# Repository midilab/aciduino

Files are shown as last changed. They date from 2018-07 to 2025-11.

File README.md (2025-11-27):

# Aciduino

The DIY Arduino-based Roland TB303 and TR808 Step Sequencer clone and MIDI Controller. Designed using readily available, inexpensive parts. It can be easily assembled on a protoboard or [ordered as PCB](https://pushermanproductions.com/product/midilab-aciduino-303-style-midi-sequencer-pcb-only/). 

There are two flavors of aciduino, the [first version(v1)](https://github.com/midilab/aciduino/tree/master/v1/) is a TB303 sequencer only, the [second version(v2)](https://github.com/midilab/aciduino/tree/master/v2/) is a TB303 and TR808 sequencer with oled display and step/pattern/mute grid system.

Find out more about at [official home page](https://midilab.co/aciduino/)

## [Aciduino V1](https://github.com/midilab/aciduino/tree/master/v1/)  
2 Tracks TB303 sequencer and MIDI Controller.

V1 on PCB
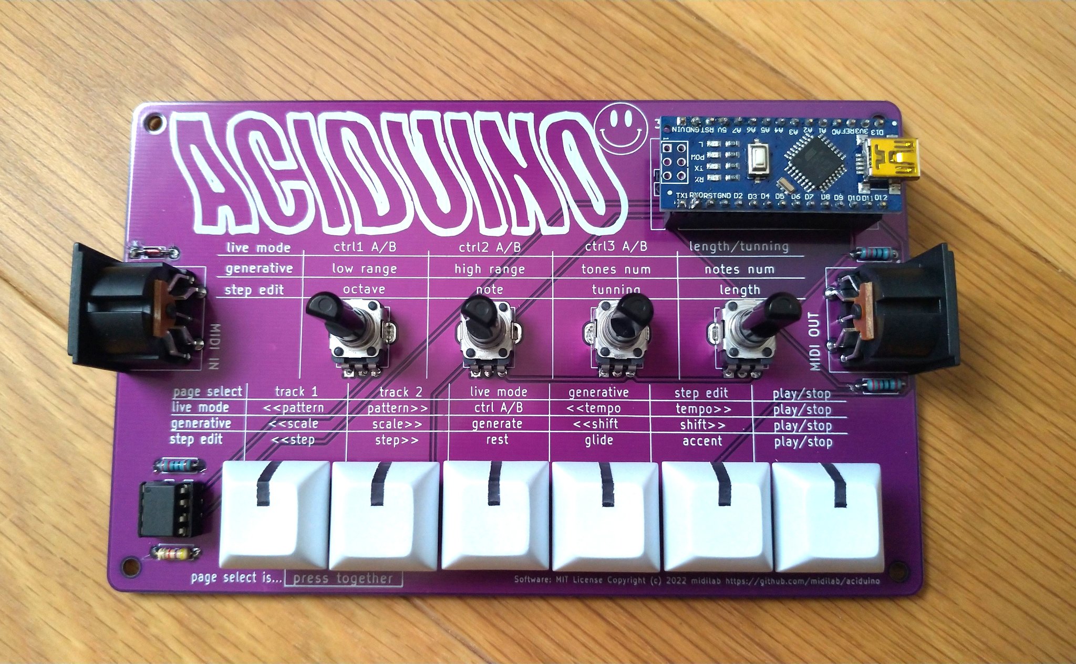
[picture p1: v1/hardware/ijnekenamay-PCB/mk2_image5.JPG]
Image of aciduino on pcb


## [Aciduino V2](https://github.com/midilab/aciduino/tree/master/v2/)  
Up to 16 Tracks TB303/TR808 sequencer with step, pattern and mute automation grid system, MIDI Controller, OLED display and extensible modular design to plug more potentiometers, buttons, MIDI or CV/Gate interfaces.

V2 on Protoboard
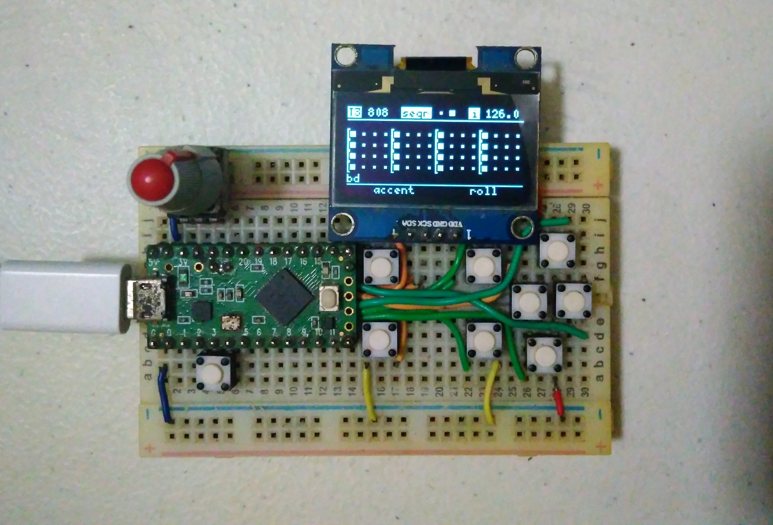
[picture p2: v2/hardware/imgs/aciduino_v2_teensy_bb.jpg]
Image of aciduino on protoboard


V2 on PCB(prototype)

Image of aciduino on uone front

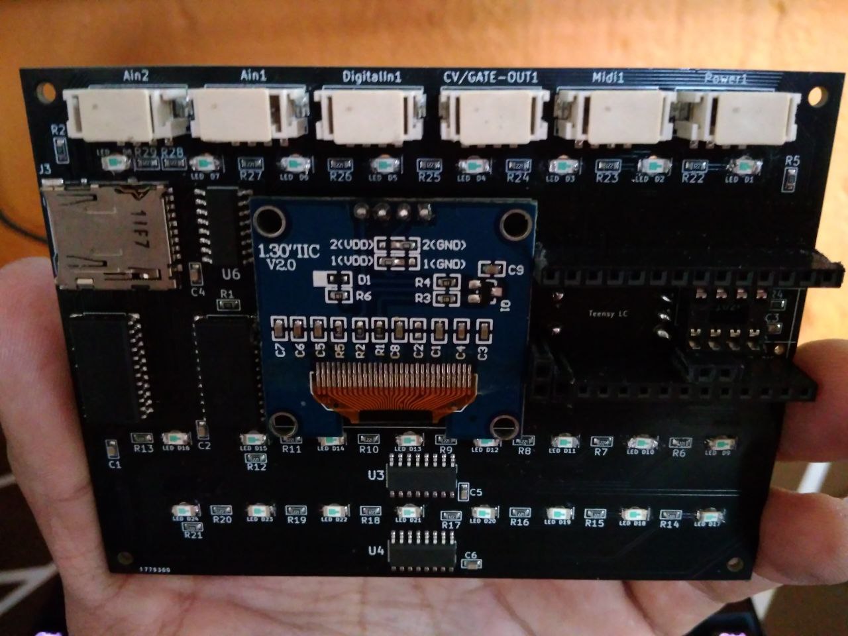
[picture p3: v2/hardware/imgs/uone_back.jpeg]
Image of aciduino on uone back


Features
========

### 303/808 Step Sequencer clone

Programming bass and drum steps using same analogy of original machines • Save your pattern work on microcontroller EPPROM memory for later live gigs • Use step length and shift to make some unusual sequences • Automation grid system for step edit, pattern navigation and mute tracks • Realtime and Step record modes for MIDI keyboard input(v2 only)

### Professional grade Clock

Tight and solid clock system using hardware timers to achieve realtime professional grade tick system • Send or receive clock to keep all your external equipment synced

### Generative Engine

Generate new and fresh acid music patterns by pressing a single button and twist some parameters • Harmonizer to force musical harmonic modes for bass lines • Euclidian generator for drum parts

### Midi Controller

Controls up to 16 parameters per track of your external synthesizers(bass/drums) • Midi learn(v2 only) • 16 potentiometers modular support to extend aciduino as midi controller(v2 only)

### Pattern memory

Store your patterns conveniently on the microcontroller's EEPROM, allowing you to access them effortlessly during live performances.

# Easy and fast Assembly

1 or 2 hours assembly time on protoboard. 

[V1 Assembly](https://github.com/midilab/aciduino/tree/master/v1)

[V2 Assembly](https://github.com/midilab/aciduino/tree/master/v2#assembly)

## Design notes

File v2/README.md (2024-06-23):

# Aciduino V2

Put your DIY super powers to the test building your own Roland's TB-303 and/or TB-808 step sequencer! An Arduino based clone project specially hacked with corrosive features to improve live performances! Save your money building the classic and timeless TB-303 and TR-808 step sequencer clone faster than a blink of an eye.

This version is multi-architecture, allowing for the use of different microcontrollers in the build. Currently, it supports Arduino Mega, any Teensy >= 3.2, and ESP32(tested on wroom dev kit only for now).

Aciduino V2 is also the first official [uMODULAR](https://github.com/midilab/uMODULAR) app, leveraging uMODULAR schematics, [uCtrl](https://github.com/midilab/uCtrl) drivers/interface library, and [uClock](https://github.com/midilab/uClock) BPM clock generator.

# Download

The recommended way for aciduino users is to make use of release pack on [Releases area](https://github.com/midilab/aciduino/releases), make sure to download the one named aciduino-v2_xxx.zip, where xxx is the version released.  
  
If you want to get the latest on the edge features and keep in track with development of aciduino you can make use of git version via clone.  
  
As this version utilizes uCtrl and uClock libraries as submodules, please remember to initialize the submodules immediately after cloning the repository.  

```console
you@acidlab:~$ git clone https://github.com/midilab/aciduino.git
you@acidlab:~$ cd aciduino/
you@acidlab:~$ git submodule update --init --recursive
```  

Open v2/AciduinoV2/AciduinoV2.ino and uncomment only one of the following microcontroller ports depending on wich one you're going to use.

```c
...
//
// Select your platform port
//
//#include "src/ports/avr/mega.h"
//#include "src/ports/teensy/protoboard.h"
#include "src/ports/esp32/wroom.h"
//#include "src/ports/esp32/wroom-ext1.h"
//#include "src/ports/teensy/uone.h"
//#include "src/ports/avr/midilab_mega.h"
...
```

## How does it looks like?

Image of aciduino on protoboard

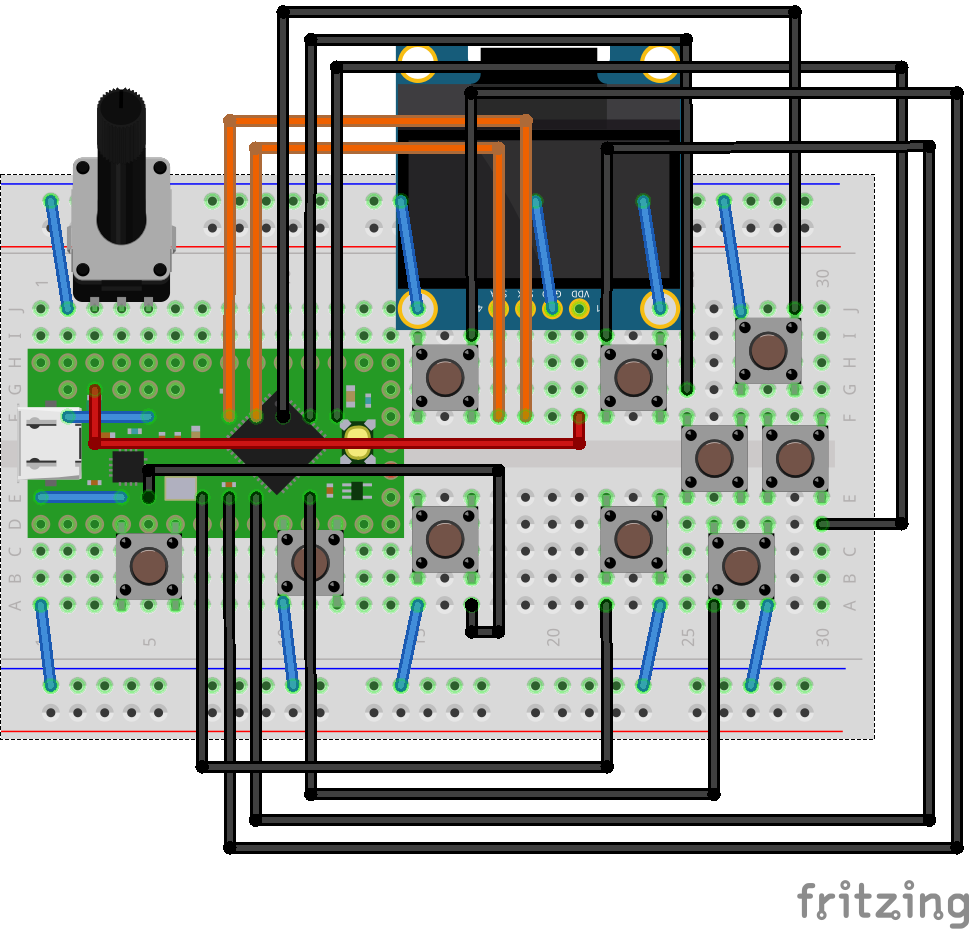
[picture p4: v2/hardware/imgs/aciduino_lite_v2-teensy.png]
Image of aciduino teensy on protoboard


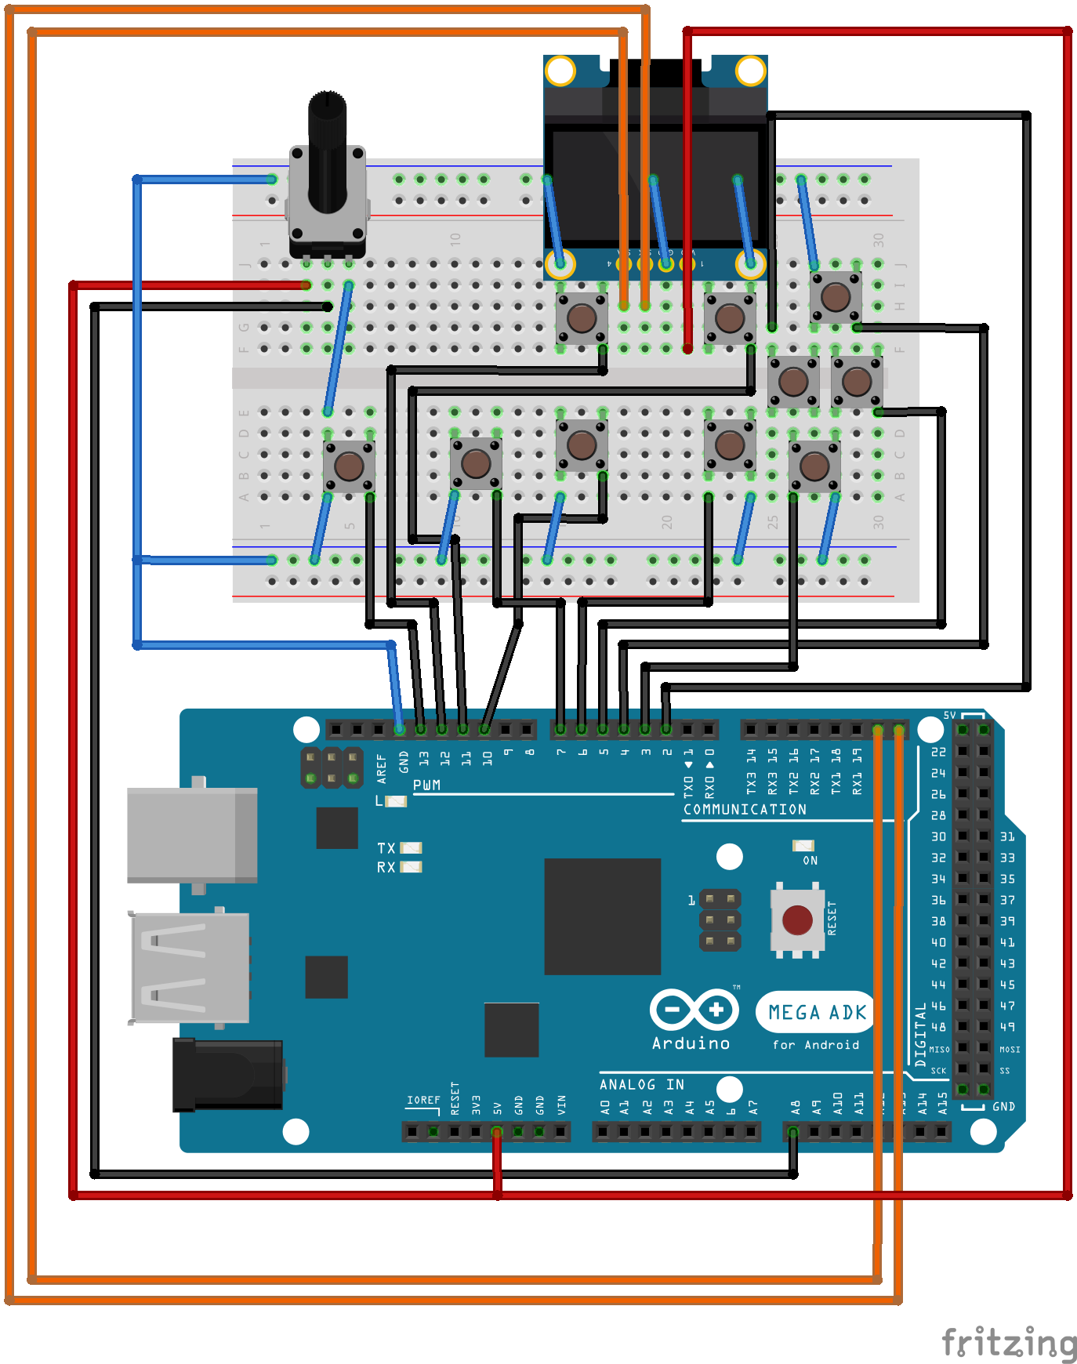
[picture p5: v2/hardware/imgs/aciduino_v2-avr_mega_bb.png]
Image of aciduino mega on protoboard


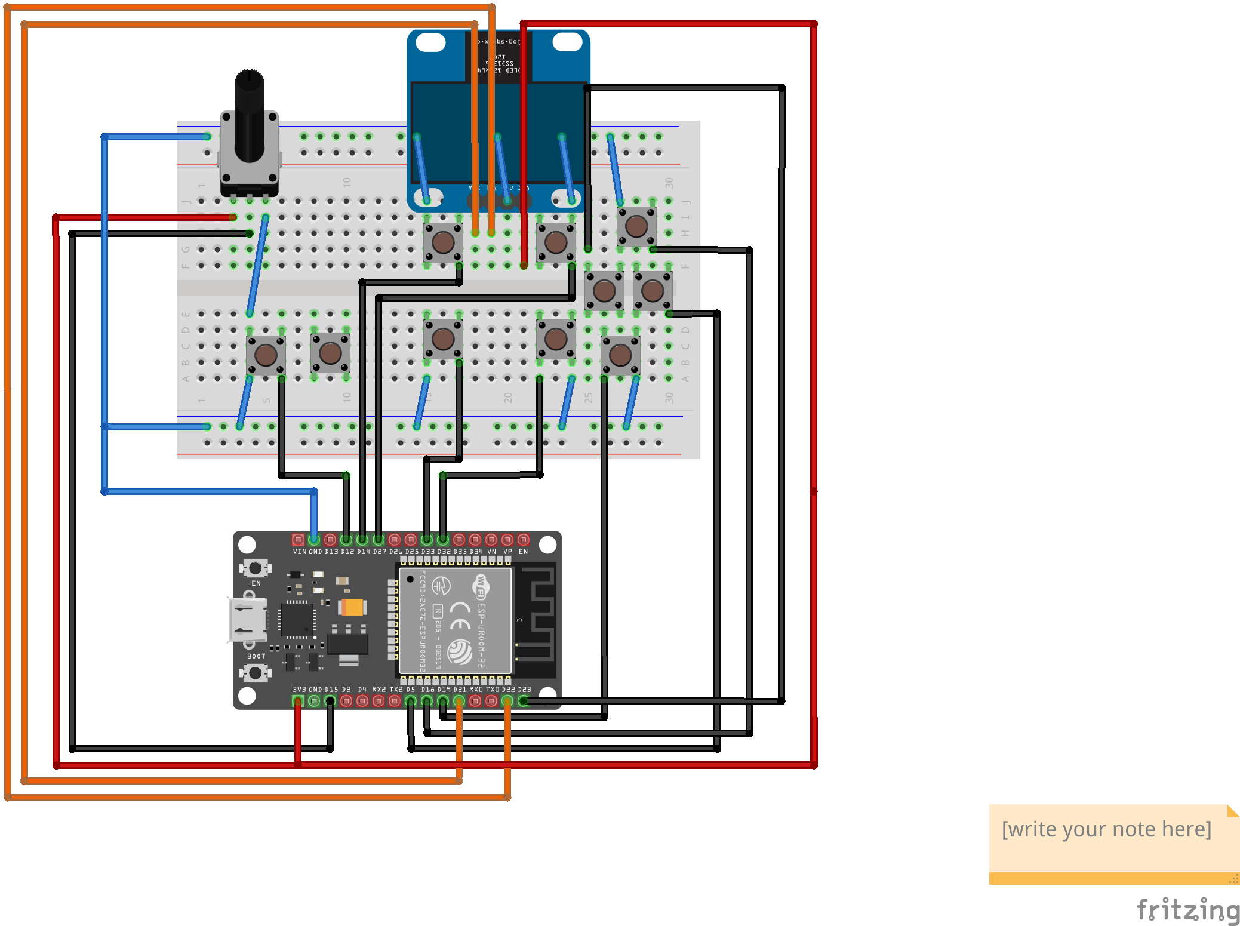
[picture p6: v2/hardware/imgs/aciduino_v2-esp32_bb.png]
Image of aciduino esp32 wroom on protoboard
  

Aciduino v2 brings new acid elements such as 808 step sequencer and a generative engine based on euclidian algorithm for great acid drums ideas.

A oled screen to get access to all parameters that matters in realtime, a easy to edit grid system for 808 and 303.

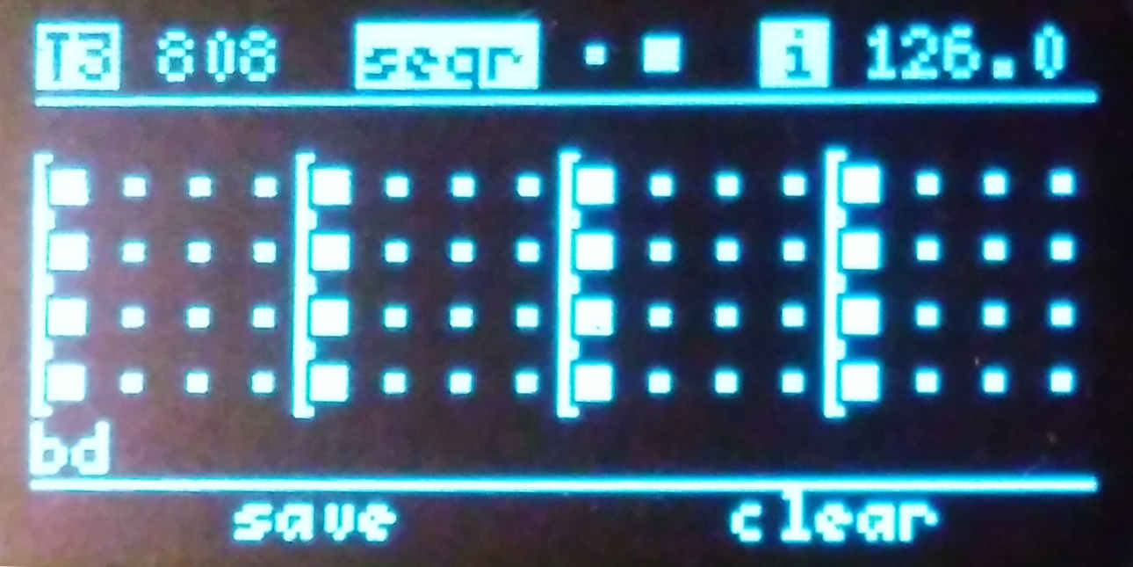
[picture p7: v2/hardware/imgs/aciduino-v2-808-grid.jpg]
Image of aciduino on protoboard


[Click here for more info](https://github.com/midilab/aciduino/tree/master/v2/)

## How to use?

Please reffer to [user manual](https://github.com/midilab/aciduino/tree/master/v2/docs/aciduinoV2-midi_sequencer-user_manual.md)

## Assembly

Place the buttons, knob and powerlines

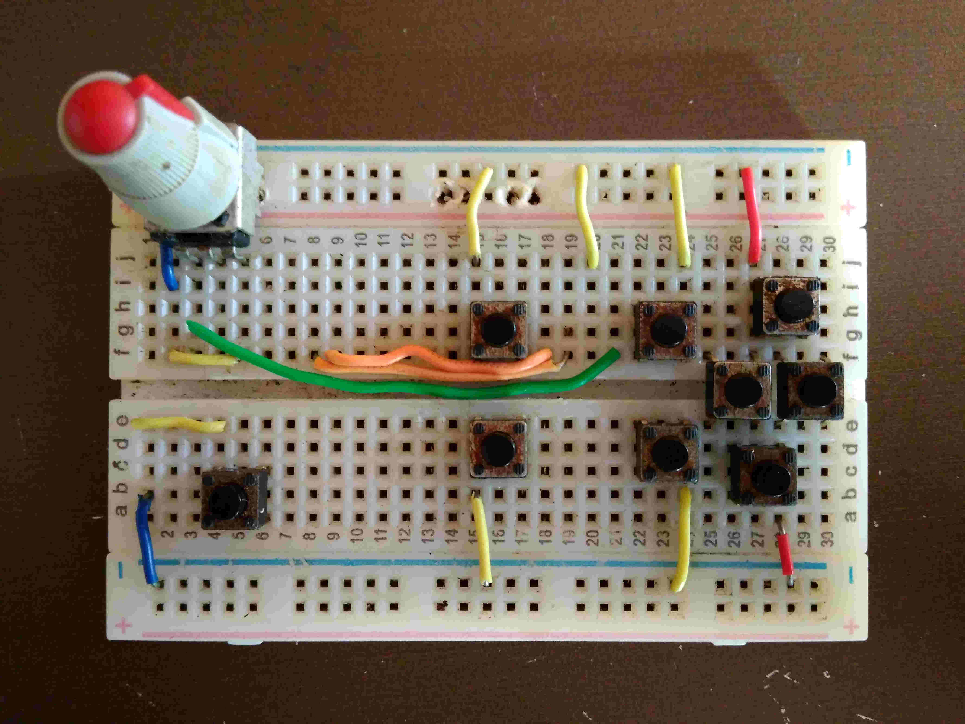
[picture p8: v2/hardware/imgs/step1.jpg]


You need to increase the size of two of the hole to place the pot base support on top (+) connect grid line.

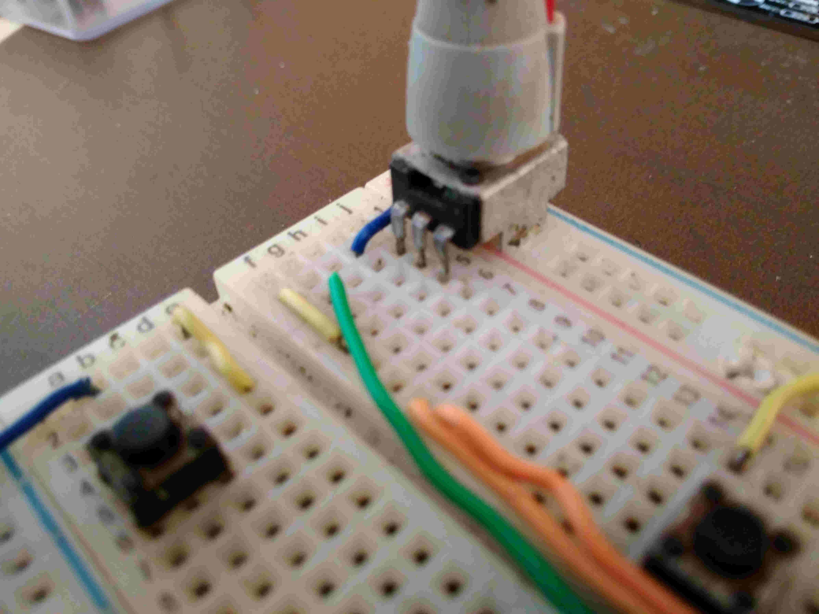
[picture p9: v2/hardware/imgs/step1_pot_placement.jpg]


Place signal lines for buttons

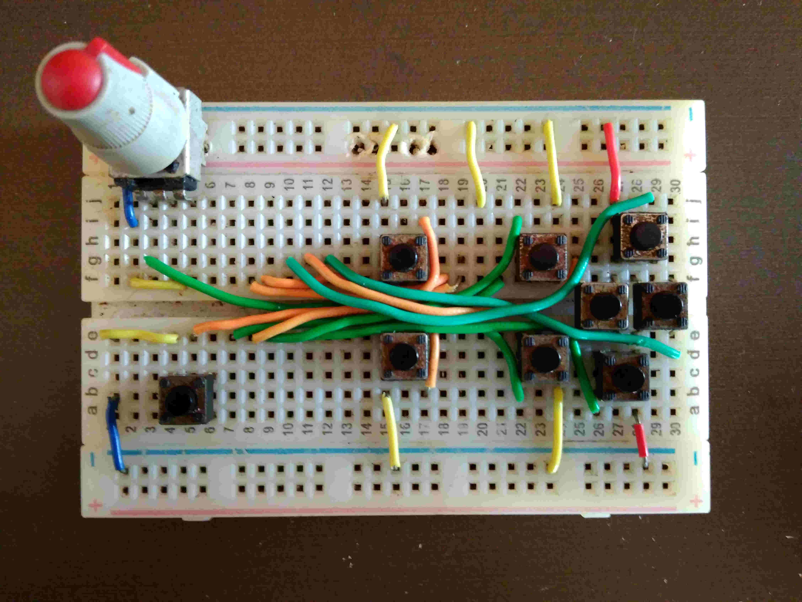
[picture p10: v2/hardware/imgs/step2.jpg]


# uMODULAR uOne

One of the uMODULAR projects to run your Aciduino V2, soon avaliable.

Image of aciduino on uone front

Image of aciduino on uone back

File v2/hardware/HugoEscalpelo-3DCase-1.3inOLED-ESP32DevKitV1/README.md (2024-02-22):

# Hugo Escalpelo 3D printed Case for 1.3 inches OLED Display

This is a 3D printed Case for 1.3 inches OLED Display specifically for the ESP32 DevKit V1. 

This case was designed in Fusion 360 for a prototype perforated PCB. Instructions, images, circuits, modifications and part list are included in this file.

This version has some button misalignment, be aware of that.

## Requirements
You need the following parts. Reference images of parts and dimentions are provided in `img` folder.

| Quantity | Part name |
|---|---|
| 1 | ESP32 DevKit V1 |
| 1 | 128x64 1.3" I2C OLED Display |
| 9 | 12mm x 12mm Push Button with Cap |
| 1 | Keyes Rotary Encoder Module |
| 1 | Female header |
| 4 | M3x10mm Screw |
| 3 | M3x20mm Screw |
| 1 | M3x25mm Screw |
| 4 | M3 Nut |
| 1 | 90x150mm Universal PCB |

## 3D printed parts
The files are provided in `.stl` for direct 3D printing and `.step` for modifications.

| Quantity | Part name |
|---|---|
| 1 | Base |
| 1 | Top |
| 1 | Faceplate |
| 1 | Wheel |

All the parts can be printed without support, don't forget to rotate them with the most flat part facing down.

This was originally tested on Creality K1 printer and Creality Print Software with both, Normal and High Quality default Settings. PLA filament was used, any rigid filament should do the trick.

If you have an Open Cage Printer, 5 milimiters of brim is needed for Base and Top parts.

Parts need aproximatelly 250gr of filament.

A Blank Faceplate is provided for you to customize. An Audiomáquinas Faceplate is provided to remember this design was first for a workshop in audiomaquinas.com.

## Circuit
This 3D printed case only fits with a very specific placement of the components in the Universal PCB as Shown in the `Circuit` images. Be sure to use the exact same placement. Wiring is more flexible and can be done as you see fit.

An Schematic image and a `.sch` file is provided in the same folder.

## Assembly
You can see images of the assembly in the `Assembly` folder.

## Code Modifications
For the 2.0 version you need to go to the `\aciduino\v2\AciduinoV2\src\ports\esp32\` path and change the following in the `wroom.h` file.

### Navigation Method
Activate encoder navitation.

```
// main navigation
//#define USE_CHANGER_POT
#define USE_CHANGER_ENCODER
```
Activate select pins for ESP32 DevKit V1
```
// going to use changer encoder?
#define NAV_ENCODER_DEC_PIN       35
#define NAV_ENCODER_INC_PIN       34
```

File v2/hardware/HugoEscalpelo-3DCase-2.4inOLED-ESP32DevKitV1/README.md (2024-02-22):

# Hugo Escalpelo 3D printed Case for 2.4 inches OLED Display

This is a 3D printed Case for 2.4 inches OLED Display specifically for the ESP32 DevKit V1. 

This case was designed in Fusion 360 for a prototype universal PCB. Instructions, images, circuits, modifications and part list are included in this file.

This version also includes files for a customized PCB with Gerber and Drill Files.

## Requirements
You need the following parts. Reference images of parts and dimentions are provided in `img` folder.

| Quantity | Part name |
|---|---|
| 1 | ESP32 DevKit V1 |
| 1 | 128x64 2.4" I2C OLED Display |
| 9 | 5mm x 5mm Push Button |
| 1 | Keyes Rotary Encoder Module |
| 1 | Female header 4 pin |
| 2 | Female header 15 pin |
| 4 | M3x10mm Screw |
| 4 | M3x28mm Screw |
| 4 | M3 secure Nut |
| 2 | M2x8mm Screw |
| 2 | M2 Insert |
| 1 | 90x150mm Universal PCB |

## 3D printed parts
The files are provided in `.stl` for direct 3D printing and `.step` for modifications. Files are in ther respective folder.

| Quantity | Part name |
|---|---|
| 1 | Base |
| 1 | Top |
| 1 | Wheel |
| 1 | Buttons |
| 2 | Separator |

All the parts can be printed without support, don't forget to rotate them with the most flat part facing down.

This was originally tested on Creality K1 printer and Creality Print Software with both, Normal and High Quality default Settings. PLA filament was used, any rigid filament should do the trick.

If you have an Open Cage Printer, 5 milimiters of brim is needed for Base and Top parts.

Parts need aproximatelly 250gr of filament.

This version does not need push buttons with caps, a plate of 3D printed buttons is included. Separators are needed to fit buttons properly along screws.

## Circuit
This 3D printed case only fits with a very specific placement of the components in the Universal PCB as Shown in the `Circuit` images. Be sure to use the exact same placement. Wiring is more flexible and can be done as you see fit.

An Schematic image and a `.sch` file is provided in the same folder. Gerber and Drill Files are provied for a Custom PCB.

## Assembly
You can see images of the assembly in the `Assembly` folder.

## Code Modifications
For the 2.0 version you need to go to the `\aciduino\v2\AciduinoV2\src\ports\esp32\` path and change the following in the `wroom.h` file.

### Navigation Method
Activate encoder navitation.

```
// main navigation
//#define USE_CHANGER_POT
#define USE_CHANGER_ENCODER
```
Activate select pins for ESP32 DevKit V1
```
// going to use changer encoder?
#define NAV_ENCODER_DEC_PIN       35
#define NAV_ENCODER_INC_PIN       34
```

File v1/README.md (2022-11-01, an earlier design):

# Aciduino

Cheap Roland TB303 Step Sequencer clone aimed for live interaction. Your acid lines for a very low cost.

With some user interface changes for cheap construction of a functional TB303 engine we present you the interface:

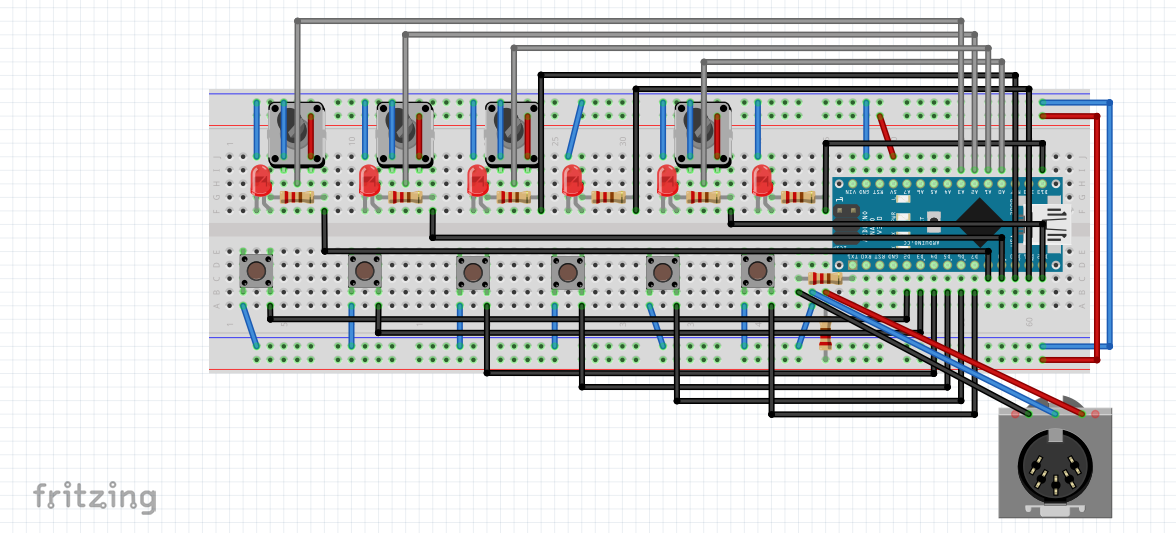
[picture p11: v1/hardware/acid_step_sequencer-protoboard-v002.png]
Image of aciduino on protoboard


### So you want a aciduino PCB?
  
[ijnekenamay](https://github.com/ijnekenamay) has created one for us, you can [download the files](https://github.com/midilab/aciduino/tree/master/v1/hardware/ijnekenamay-PCB) and send it to a fab house, or asking him to sell one for you.  
  
Image of aciduino on pcb

# Features

## 303 Step Sequencer clone
2 Tracks of famous Roland TB303 sequencer with 14 non volatile pattern memory slots to save your work. Programming using rest, tie, glide and accent on each step. The addition of step length parameter per track makes you able to choose from 1 step to 16 steps of pattern length to make some unsual sequences.

## Generative Engine
Generate automatic harmonized acid lines by pressing a single button and twist some harmonic parameter knobs. Just pick up a harmonic mode(scale), the low and high notes to fit the sequence and you have infinite sequences by pressing random it button!

## Midi Controller
Controls your synthetizer acid midi parameters per track up to 6 parameters.

## Midi Clock
Tight and solid MIDI clock to drive your gears clock needs or receive midi sync signal.

# User Interface

4 knobs and 6 buttons divided into 3 pages

When turning your aciduino on you have the page select, the page leds will be blinking indicating that you are on page select mode.

Any time you press button 1 and button 2 together you will be drive to the page select, there you can choose the disered page and track.
  
You can put you aciduino into slave mode to be in sync with a master clock source by press and hold the play/stop button until his led is ON. To get back to master mode  press and hols again until the led is OFF. 
  
Use this information above as reference for aciduino interface 

**[page select]**  
knobs    ( none )    ( none )    ( none )    ( none )  
buttons [ track 1 ] [ track 2 ] [live mode] [generative] [step edit] [play/stop]  

**[page 1 live mode]**  
knobs    (ctrl 1 A/B)  (ctrl 2 A/B)  (ctrl 3 A/B)  (length/tunning)  
buttons [ << pattern ] [ pattern >> ] [ ctrl A/B ] [ << tempo ] [ tempo >> ] [play/stop]  
hold    [save pattern] [delete pattern] => hold button 1 or button 2 until led blink to complete the action.  

**[page 2 generative mode]**  
knobs    (low range)  (high range)  (tones num)  (notes num)  
buttons [ << scale ] [ scale >> ] [ generate ] [ << shift ] [ shift >> ] [play/stop]  

**[page 3 step edit]**  
knobs     (octave)    (note)      (tunning)    (length)  
buttons [ << step ] [ step >> ] [   rest   ] [   glide   ] [  accent  ] [play/stop]  

## [page select]: press button1 and button2 together

Just press the desired page button to navigate thru. 

Use track 1 and track 2 buttons to select the track to be use. The selected track is the one with led on.

**interface**  
knobs    ( none )    ( none )    ( none )    ( none )  
buttons [ track 1 ] [ track 2 ] [live mode] [generative] [step edit] [play/stop]  

## [live mode]

The navigation buttons 1 and 2 are used to change pattern, one of the leds will turn on when you reach the navigation barrier - first patterns led 1 on, last pattern led 2 on.

Holding button 1 or 2 for 2 seconds: save pattern, delete and reset pattern

The midi cc commands will be sent to the selected track only.

ctrl A and ctrl B change between knobs midi data to be sent or controlled. The selected ctrl A is the one with led off and ctrl B the led on.

Global tunning lets you go up or down on scale tunning, from -12 to +12 interval.

**interface**  
knobs    (ctrl 1 A/B)  (ctrl 2 A/B)  (ctrl 3 A/B)  (length/tunning)  
buttons [ << pattern ] [ pattern >> ] [ ctrl A/B ] [ << tempo ] [ tempo >> ] [play/stop]  
hold    [save pattern] [delete pattern] => hold button 1 or button 2 until led blink to complete the action.  

## [generative]

Press generate button to get a fresh new sequence on selected track, turning knobs here doesnt change the current sequence, it only sets the parameters for the next time you press generate button.

harmonic scale mode -(previous) and harmonic scale mode +(next) lets you navigate thru harmonic modes(scales). Pressing harmonic mode - all the way until get led on means no harmonic context apply to sequence generation.

By default harmonize is off, just press once harmonic +(next) to get first scale on list, ionian, next again to got to dorian and so on.

Ramdom range low note selects the first note of sequence range notes that can be generated by probabilty. Ramdom range note defines the range of notes that can be generated starting from ramdom low note.

Ramdom range high note selects the barrier to the most high note allowed to be generated on a sequence.

Using shift buttons you can shitf all the sequence steps one step left or rigth using shift navigation buttons.

**interface**  
knobs    (low range)  (high range)  (tones num)  (notes num)  
buttons [ << scale ] [ scale >> ] [ generate ] [ << shift ] [ shift >> ] [play/stop]  

## [step edit]
Here you can program you acid lines in the same way you program a original one, but instead of keypad for notes you use 2 knobs, one for octave and other for note to get access to all midi range notes spectrum while editing step by step your sequence using rest, glide and accent.

Using step navigation buttons the led on for prev step button means you are have the first step selected for edit, led on for next step button means you have the last step select for edit.

The rest, glide, tie and accent buttons are applied to selected step, led on/off are used to express the state of each parameter per step.

Octave and note knobs lets you select the note for the selected step.

Sequence lenth knob lets you choose from 1 step to 16 steps or lenth for your sequence.

**interface**  
knobs     (octave)    (note)      (tunning)      (length)  
buttons [ << step ] [ step >> ] [   rest   ] [   glide/tie   ] [  accent  ] [play/stop]  

# Configure for personal needs

Use config.h to hack your environment as you wish.

# Dependencies

This clone is based on uClock library to generate sequencer BPM clock. The library is now part of project to get DIYers a easy compile time.

You can check more info for this library on [github repo](https://github.com/midilab/uClock/)

# BOM List

* 1x arduino nano
* 1x solderless breadboard protoboard 830 tie points 2 busess
* 1x solderless breadboard jumper cable wire kit box
* 6x 220ohms resistors
* 6x 6mm taticle switch
* 6x 3mm diffused leds
* 4x 10k linear potentiometers

## MIDI connection?

Add more two 220ohms resistors to you boom list and choose one of thoses above methods as main midi conection.

* 1x 5 pins DIN female connector (standard MIDI connector) + sto protoboard - you need solder skills here.
* 1x midi cable. Cut it in  a half and connect it directly to protoboard - its a good idea to soldering the wire tip before make the connections.
  
You can also use a MIDI input board to sync the aciduino with a master clock source if needed. Search over the internet for a MIDI input schematic if you want to build it yourself for aciduino.  
  
## USB Connection?

* Open config.h and set MIDI_MODE to 1. 
* Download and install a [serial-to-midi converter like](http://projectgus.github.io/hairless-midiserial/)
* Open your favorite DAW, configure MIDI port to get signal from serial-to-midi converter and just go acidulize with your preferred acid synth plugin. Depends on your operational system you may need a additional MIDI virtual port driver installed.

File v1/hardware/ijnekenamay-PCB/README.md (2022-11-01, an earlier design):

# ACIDUINO PCB MK2

### ACIDUINO has been upgraded to MK2 with MIDIinput!
I have created a PCB that can build an aciduino by midilab as a bare board device.
It would be easy to build with less number parts!
Please refer to the folder hierarchy above for the code.
(Be sure to use the latest firmware!)

↓↓↓Completed build image↓↓↓



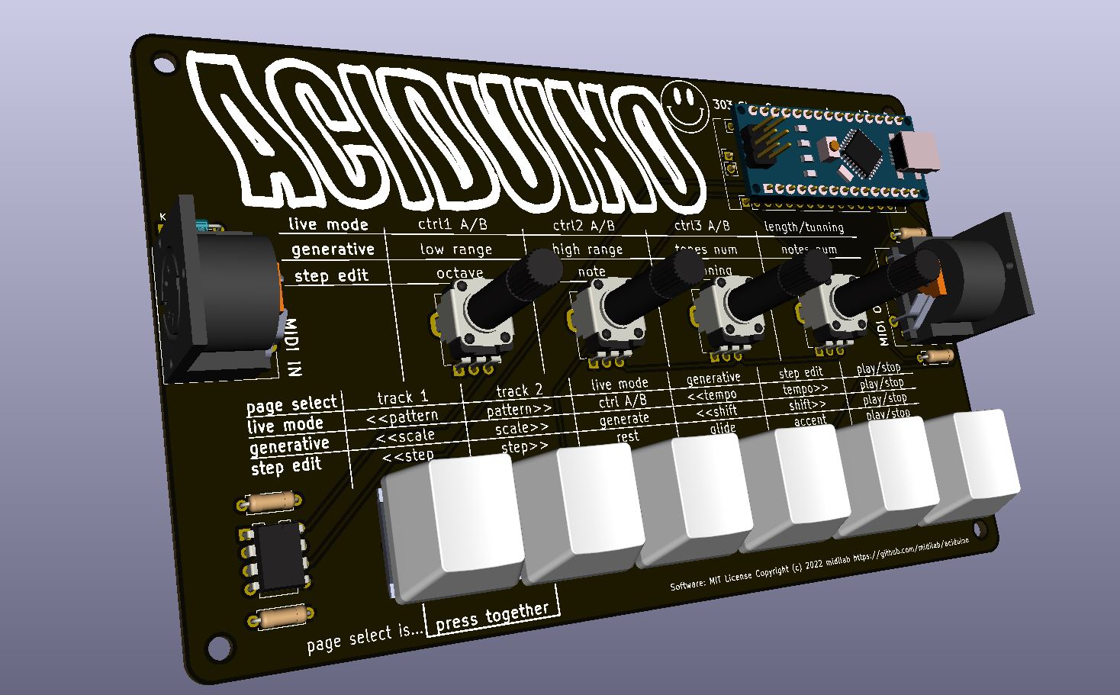
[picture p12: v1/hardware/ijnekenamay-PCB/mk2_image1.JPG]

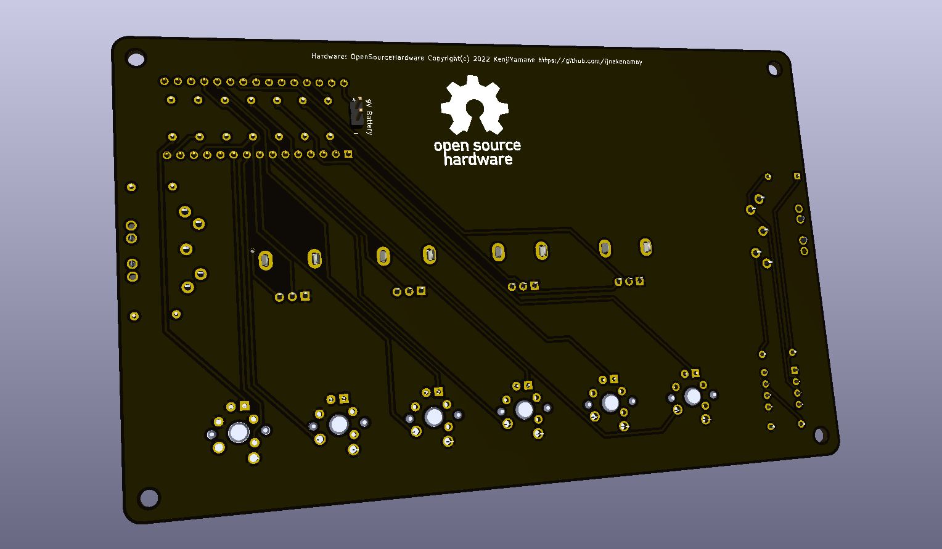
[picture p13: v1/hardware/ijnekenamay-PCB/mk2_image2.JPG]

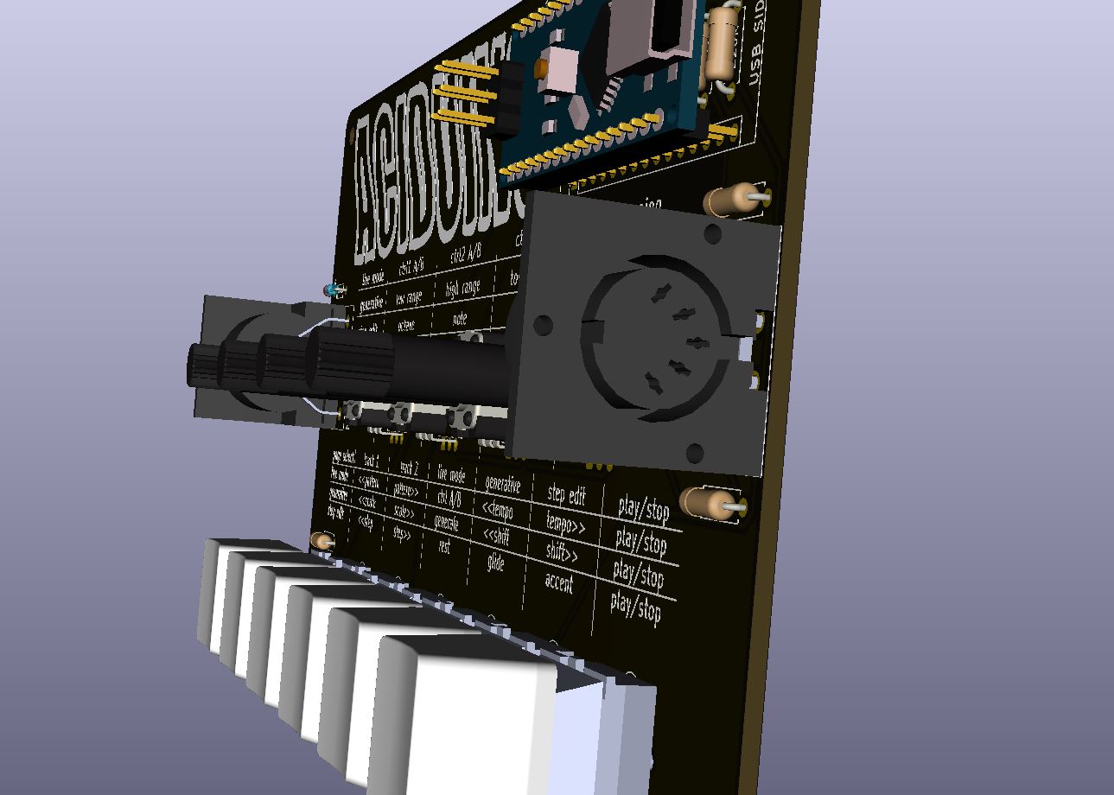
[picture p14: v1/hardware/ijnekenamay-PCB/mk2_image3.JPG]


# About Fabrication
You can get the PCB by submitting the "aciduino_gerber.zip" to a PCB fabrication company in China.
It's usually a lot of 5 pieces.

# BOM List

* 1x arduino nano
* 10x 220ohms resistors
* 1x 4.7kohms resistors
* 1x 1N4148 diodes
* 1x 6N138 optocoupler
* 6x Key switches(If you don't like that, you can substitute a 6mm taticle switch)
* 6x 3mm diffused leds
* 4x 10k linear potentiometers
* 2xMIDI Connector[like this](http://modularanalog.com/?product=midi-jack-5-pin-din-pcb-mount)

!! Additional !!
- A hole is provided to connect a 9V battery box.
- It also works with power supplied from the Arduino's USB port.
- DEMO with my modular and polyend traker(use as MIDI master)[instagram](https://www.instagram.com/reel/CaJfxwNDVI4/?utm_source=ig_web_copy_link)

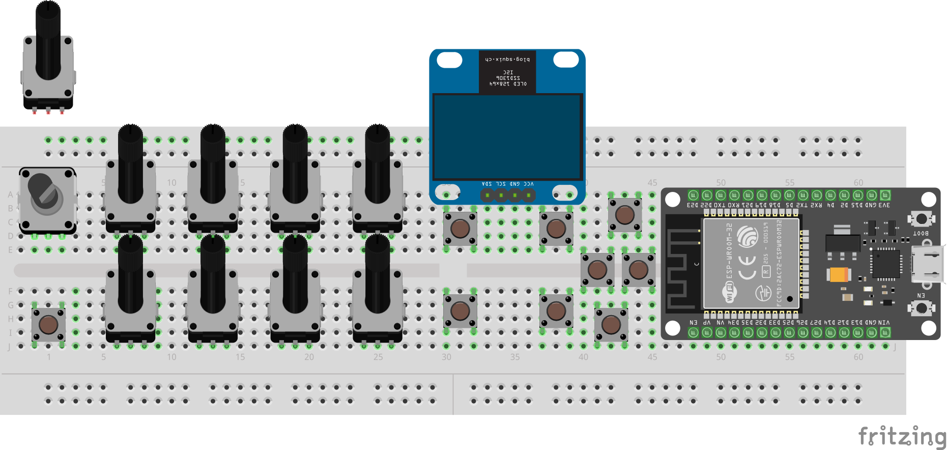
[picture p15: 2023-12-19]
v2/hardware/imgs/aciduino_v2-esp32_midi_controller_ext_bb.png

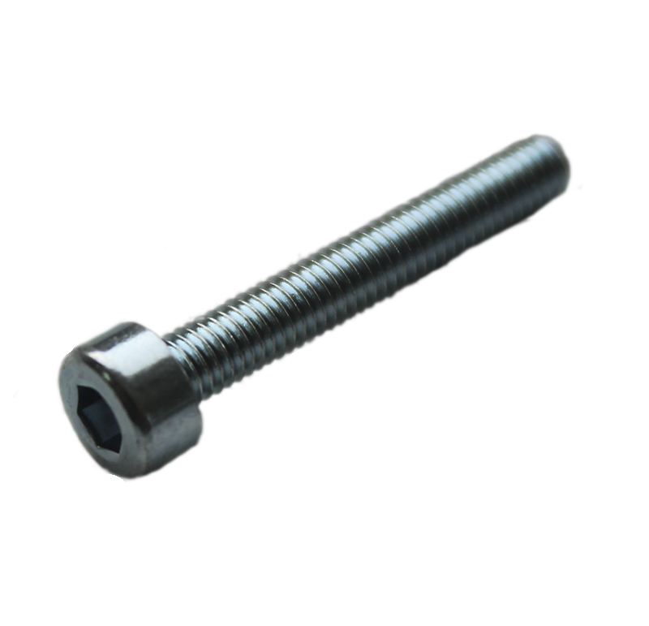
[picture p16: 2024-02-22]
v2/hardware/HugoEscalpelo-3DCase-2.4inOLED-ESP32DevKitV1/img/m3x20mm-screw.jpg

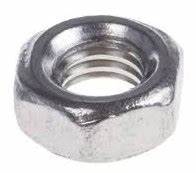
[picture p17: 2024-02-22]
v2/hardware/HugoEscalpelo-3DCase-1.3inOLED-ESP32DevKitV1/img/m3nut.jpg

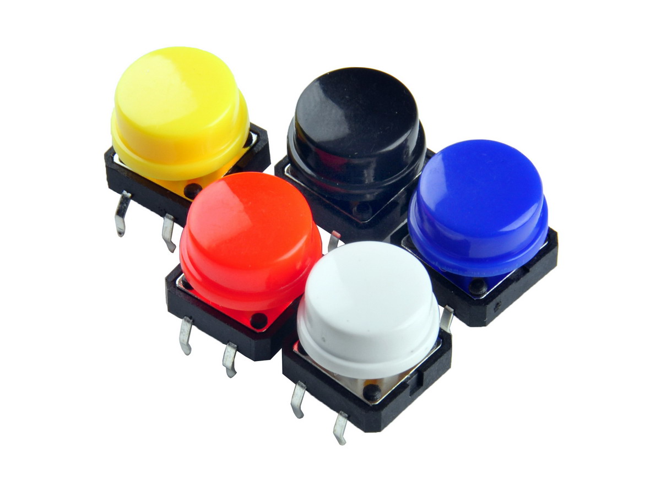
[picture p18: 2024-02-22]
v2/hardware/HugoEscalpelo-3DCase-1.3inOLED-ESP32DevKitV1/img/12-X-12MM-X-7.5MM-PUSH-BUTTON.jpg

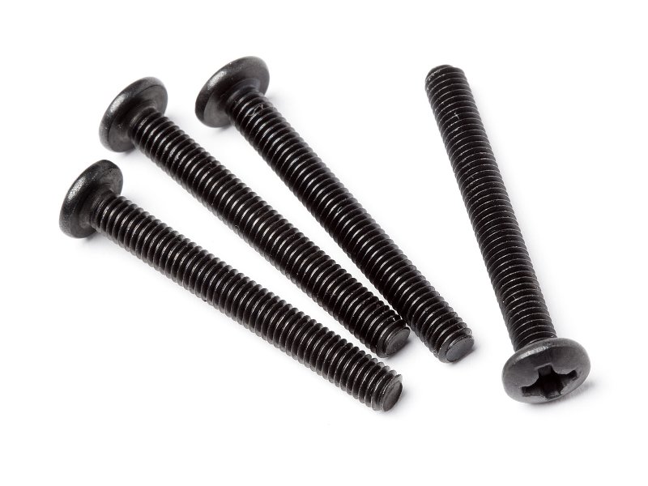
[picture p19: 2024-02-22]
v2/hardware/HugoEscalpelo-3DCase-1.3inOLED-ESP32DevKitV1/img/m3x25mm-screw.jpg

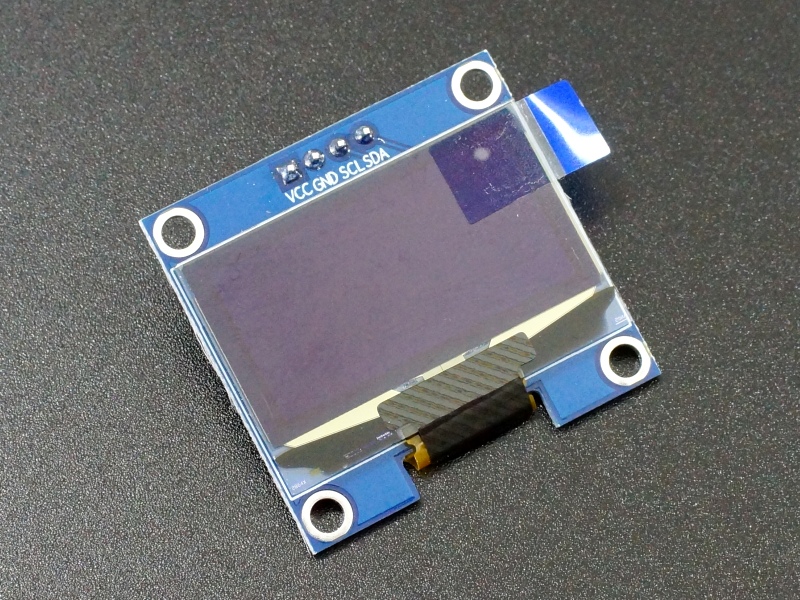
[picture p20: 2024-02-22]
v2/hardware/HugoEscalpelo-3DCase-1.3inOLED-ESP32DevKitV1/img/OLED-1.3-Blue-I2C.jpg

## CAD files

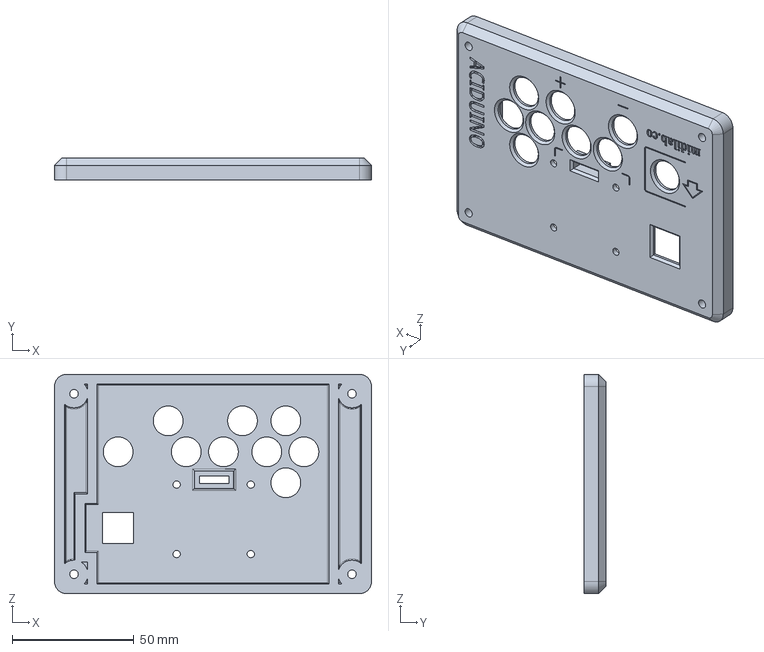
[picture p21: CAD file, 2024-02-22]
v2/hardware/HugoEscalpelo-3DCase-1.3inOLED-ESP32DevKitV1/STEP/Top v33.step
130.0 x 9.00 x 90.0 mm

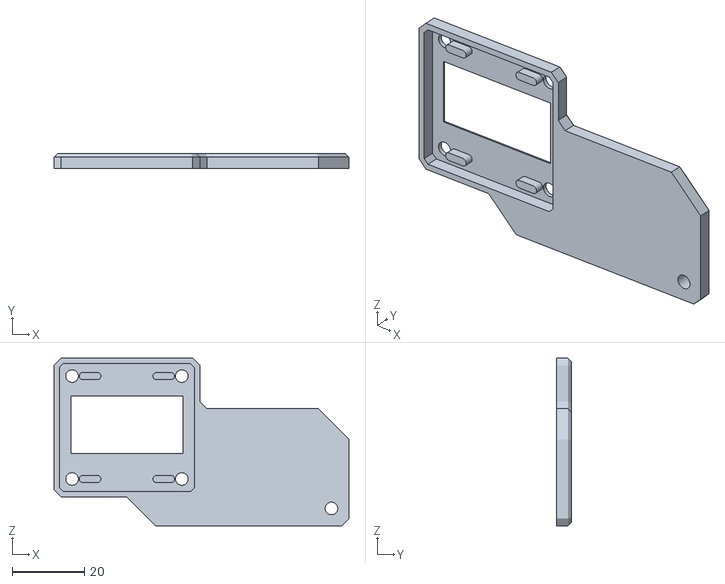
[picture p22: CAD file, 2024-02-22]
v2/hardware/HugoEscalpelo-3DCase-1.3inOLED-ESP32DevKitV1/STL/Faceplate v30.stl
81.7 x 4.10 x 46.5

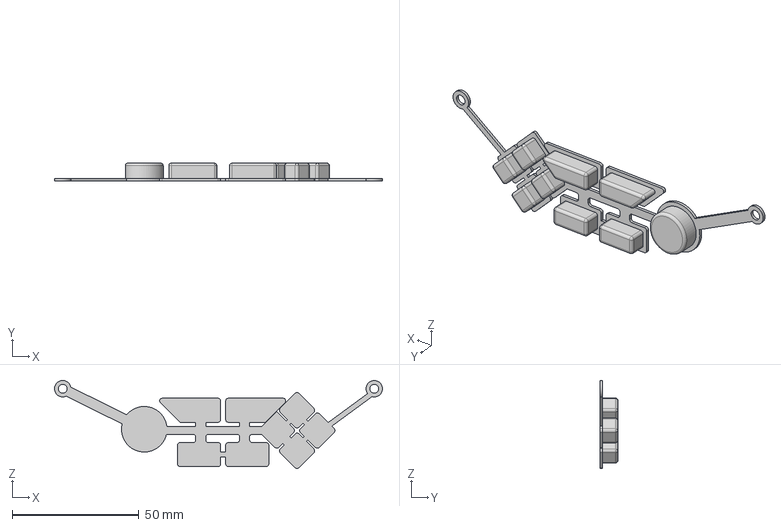
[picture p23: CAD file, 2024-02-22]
v2/hardware/HugoEscalpelo-3DCase-2.4inOLED-ESP32DevKitV1/STEP/Buttons v4.step
129.5 x 7.00 x 34.7 mm

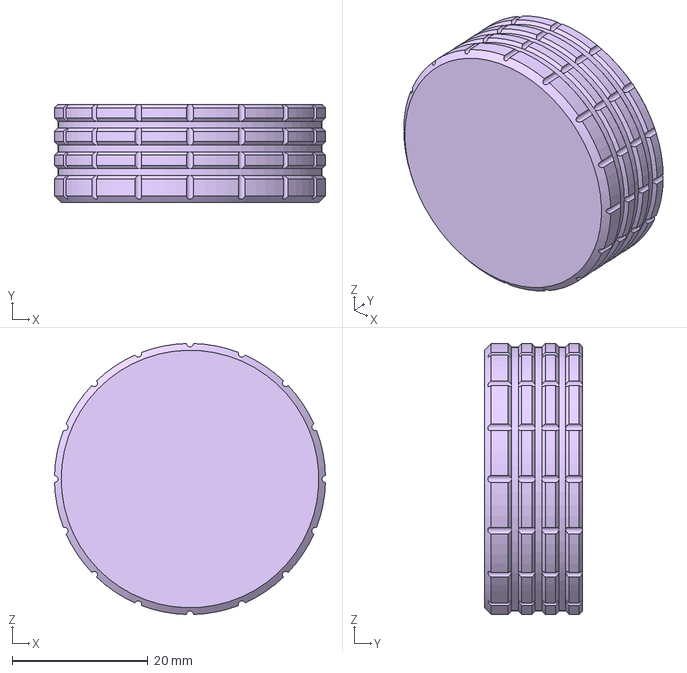
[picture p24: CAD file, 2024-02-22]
v2/hardware/HugoEscalpelo-3DCase-1.3inOLED-ESP32DevKitV1/STEP/Wheel v3.step
40.0 x 14.5 x 40.0 mm

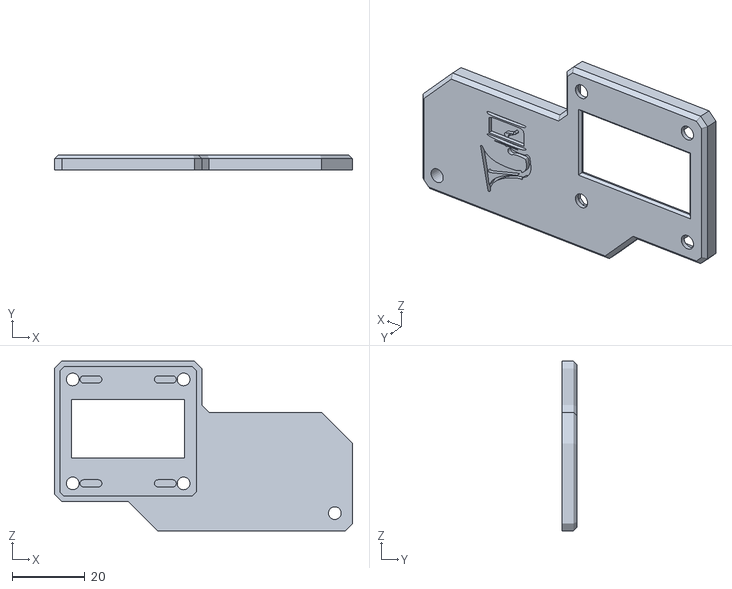
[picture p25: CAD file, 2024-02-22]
v2/hardware/HugoEscalpelo-3DCase-1.3inOLED-ESP32DevKitV1/STL/Faceplate-AudiomaquinasLogo v32.stl
81.7 x 4.10 x 46.5

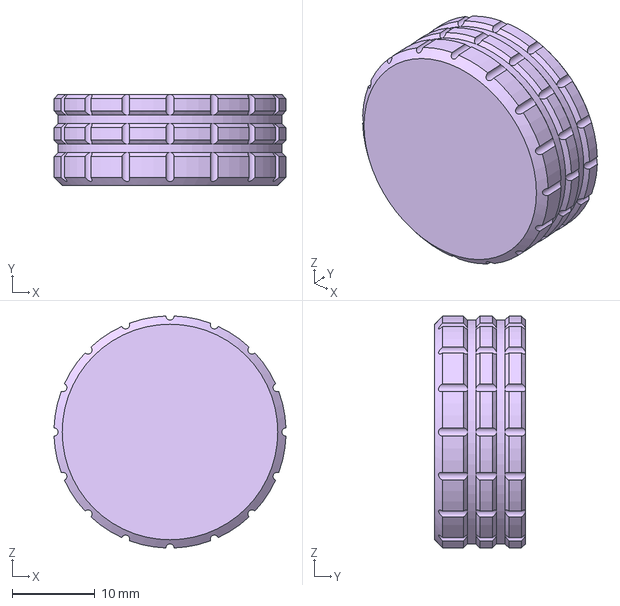
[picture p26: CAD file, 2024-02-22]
v2/hardware/HugoEscalpelo-3DCase-2.4inOLED-ESP32DevKitV1/STEP/Wheel v5.step
28.0 x 11.0 x 28.0 mm

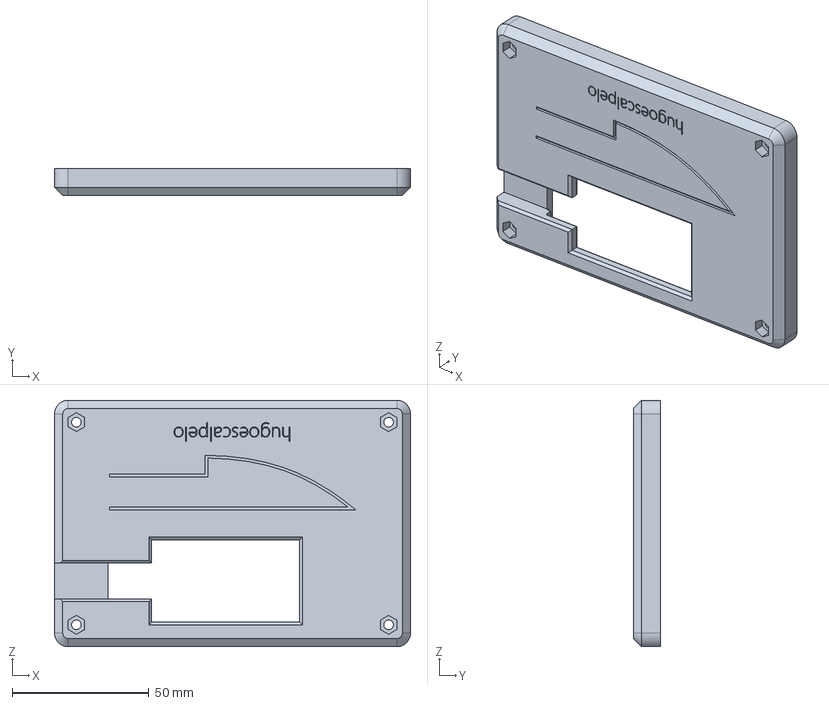
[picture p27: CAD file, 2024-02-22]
v2/hardware/HugoEscalpelo-3DCase-1.3inOLED-ESP32DevKitV1/STEP/Base v18.step
130.0 x 10.0 x 90.0 mm

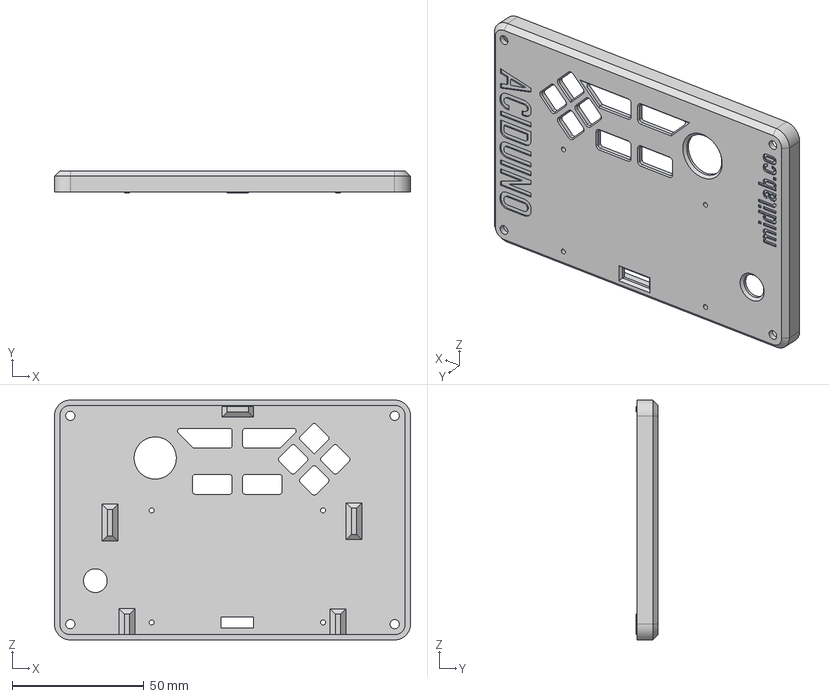
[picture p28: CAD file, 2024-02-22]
v2/hardware/HugoEscalpelo-3DCase-2.4inOLED-ESP32DevKitV1/STEP/Top v11.step
135.0 x 8.50 x 91.0 mm

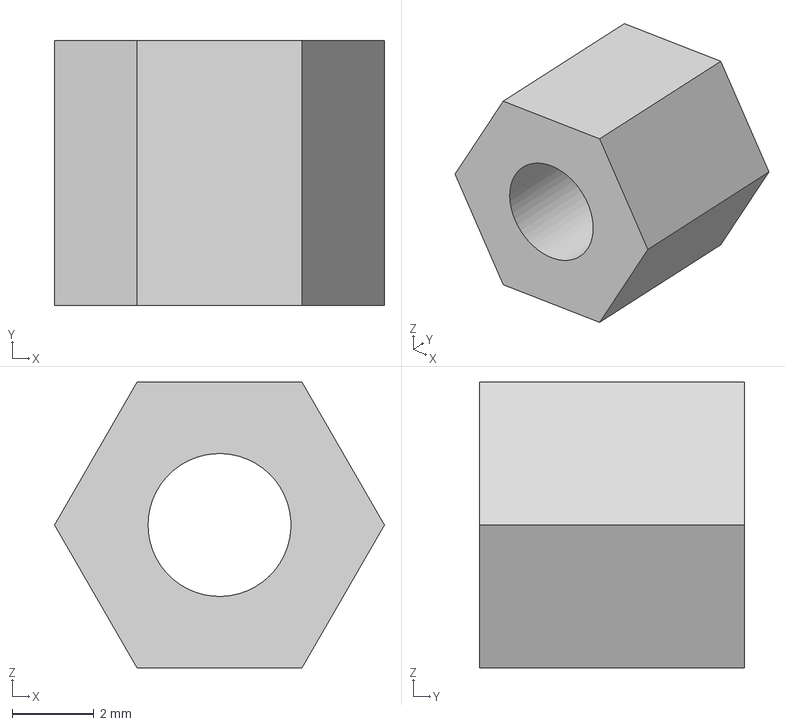
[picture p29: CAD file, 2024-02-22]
v2/hardware/HugoEscalpelo-3DCase-2.4inOLED-ESP32DevKitV1/STEP/Separator v1.step
8.08 x 6.50 x 7.00 mm

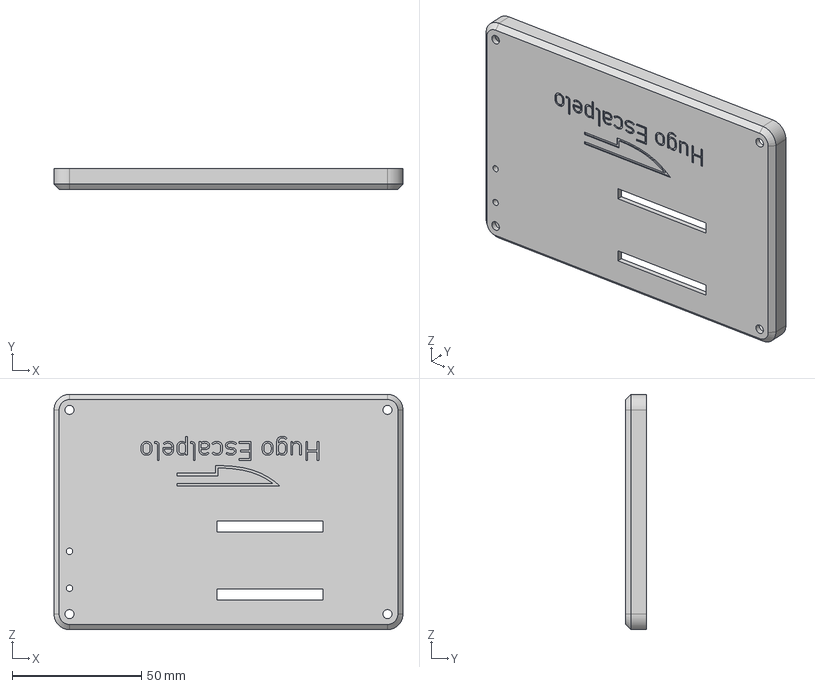
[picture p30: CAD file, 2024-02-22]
v2/hardware/HugoEscalpelo-3DCase-2.4inOLED-ESP32DevKitV1/STEP/Base v7.step
135.0 x 8.00 x 91.0 mm

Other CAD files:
v2/hardware/HugoEscalpelo-3DCase-1.3inOLED-ESP32DevKitV1/STEP/Faceplate Audiomaquinas v32.step
v2/hardware/HugoEscalpelo-3DCase-1.3inOLED-ESP32DevKitV1/STEP/Faceplate v32.step
v2/hardware/HugoEscalpelo-3DCase-1.3inOLED-ESP32DevKitV1/STL/Base v18.stl
v2/hardware/HugoEscalpelo-3DCase-1.3inOLED-ESP32DevKitV1/STL/Top v33.stl
v2/hardware/HugoEscalpelo-3DCase-1.3inOLED-ESP32DevKitV1/STL/Wheel v3.stl
v2/hardware/HugoEscalpelo-3DCase-2.4inOLED-ESP32DevKitV1/STL/Base v7.stl
v2/hardware/HugoEscalpelo-3DCase-2.4inOLED-ESP32DevKitV1/STL/Buttons v4.stl
v2/hardware/HugoEscalpelo-3DCase-2.4inOLED-ESP32DevKitV1/STL/Separator v1.stl
v2/hardware/HugoEscalpelo-3DCase-2.4inOLED-ESP32DevKitV1/STL/Top v11.stl
v2/hardware/HugoEscalpelo-3DCase-2.4inOLED-ESP32DevKitV1/STL/Wheel v5.stl

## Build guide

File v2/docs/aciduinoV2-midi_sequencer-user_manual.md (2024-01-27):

# ACIDUINO V2 User Manual

## Introduction

Up to 16 Tracks TB303/TR808 sequencer with step, pattern and mute automation grid system, MIDI Controller, OLED display and extensible modular design to plug more potentiometers, buttons, MIDI or CV/Gate interfaces.

A friend of mine some time ago had come out with this one:
"Put your DIY super powers to the test building your own Roland’s TB-303 and TB-808 step sequencer! An Arduino based clone project specially hacked with corrosive features for live performances! Save your money building this classic sequencer clone faster than a blink of an eye."

## GETTING STARTED

To use aciduino, follow these steps:

1. Read the documentation [here](https://github.com/midilab/aciduino/tree/master/v2/)
2. Build your device [following these steps](https://github.com/midilab/aciduino/tree/master/v2#assembly)
3. Download the latest [software](https://github.com/midilab/aciduino/releases)
4. Check your hardware configuration in `/AciduinoV2/0_hardware_setup.ino`
5. Ajust the sequencer to your taste in `/AciduinoV2/src/sequencer/setup.h`

## USER INTERFACE
If you followed the assembly guide you should have a device like this :

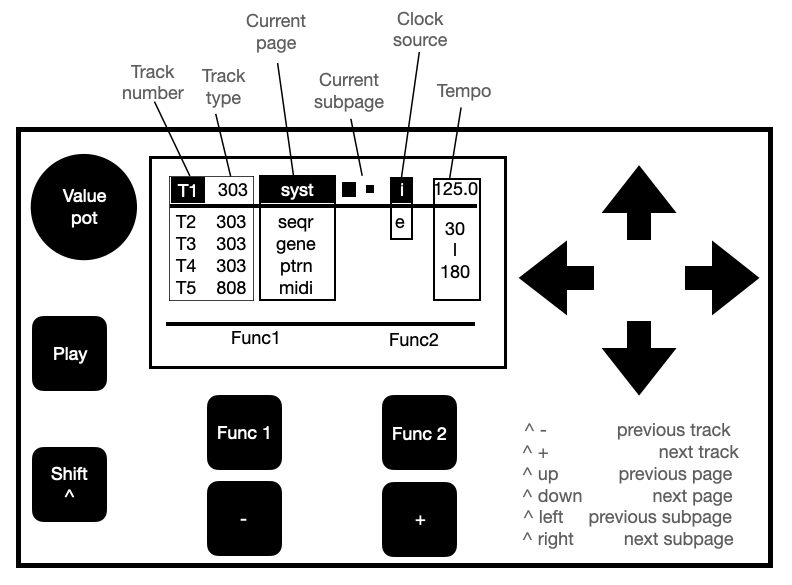
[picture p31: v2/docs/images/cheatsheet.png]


The interface presents you simple schema to navigate and interact with you aciduino.

- **Navigation buttons:** UP, DOWN, LEFT. RIGTH. use to navigate thru page elements. The current selected element is blinking.  
*4 right most buttons*  
- **Function buttons:** If the current selected element has an action, it will show up at bottom of your display with the action name for each button.  
*2 upper buttons*  
- **Generic buttons:** Acts as value changer, a decrementer and incrementer for almost all elements.  
*2 lower buttons*  
- **Pot:** Acts as a value changer just like generic buttons, most of elements can be changed using generic buttons or the pot as wish.  
- **Shift button** Hold it while press another interface button.  
*bottom left button*  
- **Transport button** press to start or stop the sequencer  
*middle left button*  

The GUI is divided into the following main sections:

- **Header bar:** Contains the Track number (by default T1 to T5) and type (303 or 808), the Page name and selected subpage (1 or 2), the clock soucre and tempo value (40-180).
- **Subpage display:** where the actual tweaking occurs.
- **Function buttons label:** Provides a clear feedback for the 2 function buttons

## WORKFLOW

The Workflow consists of 5 pages :  
**System** : common parameters to all tracks  
**Sequencer** : the place to edit the Track sequence  
**Generator** : where the magic happens  
**Pattern** : performance page, mute or unmute tracks or drum voices, save and load patterns
**Midi** : tweak your 16 favourite CCs  

*Shift + Nav UP/DOWN:* Change page  
*Shift + Nav LEFT/RIGHT:* Changes subpage  
*Shift + Generic button 1:* Previous track  
*Shift + Generic button 2:* Next track  

 ### **System Page** 
The system Page is common to all tracks
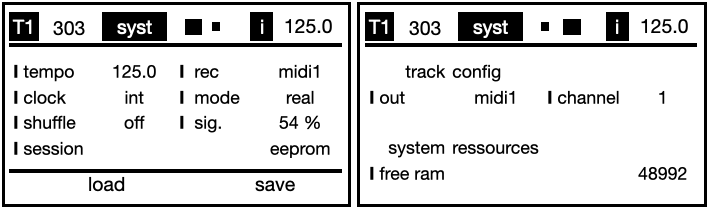
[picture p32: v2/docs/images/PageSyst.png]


**Tempo** set uClock tempo from 40 to 180  
*pot=coarse adjust  
F1=rec / F2=play  
generic buttons=fine adjust*  

**clock:** choose clock source, internal, midi1 or midi2  
*pot=coarse adjust  
No function available  
generic buttons= decrementer / incrementer*  

**shuffle:** turn the groove on or off  
*pot=on/off  
No function available  
generic buttons=on/off*  

**sig.:** set the swing signature (3 MPC signatures, user signatures can be added)
*pot=54, 58, 62, 68, 71%  
No function available  
generic buttons= decrementer / incrementer*  

**rec:** input source midi1 or midi2  
*pot=select source  
No function available  
generic buttons= decrementer / incrementer*  

**mode:** record in real time or step mode  
*pot=real/step  
No function available  
generic buttons= decrementer / incrementer*  

**session:** save your ideas on eeprom or SDCard  
*pot=storage  
F1=load / F2=save  
generic buttons= decrementer / incrementer*  

**Track Config:**  
**out :** midi 1 or midi 2

*pot=storage  
F1=load / F2=save  
generic buttons= decrementer / incrementer*  

---  

### Sequencer page     
 There are slightly different parameters depending on the Track type.
 
  **length:**  define the number of steps in the current sequence 
  0 to whatever you defined in `/AciduinoV2/src/sequencer/setup.h`for a 303 track.  
 0 to 64 for a 808 track. Note that each drum voice of a 808 track can have a different pattern length   
*pot=step number  
No function available   
generic buttons= decrementer / incrementer* 

 **Shift :** offset the whole sequence forward or backward  
 
  - **303 Sequencer Page**  
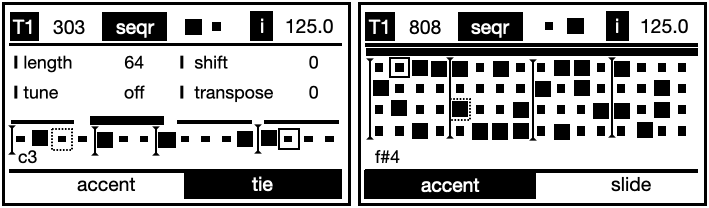
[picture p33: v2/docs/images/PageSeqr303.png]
   
  **Tune:** set the tonic note (off - C1 -> B1)  
   *pot=off/set tonic note  
   No function available   
   generic buttons= decrementer / incrementer*   
     
  **transpose :** transpose the sequence   
  *pot=off/set tonic note  
No function available    
generic buttons= decrementer / incrementer*  
  
  **Bar Selector :** the bar above the step sequencer representation. Each division represent a 16 step bar, a bold division tells which bar is being played, a blinking division tells which bar is being edited    
  *pot=no option  
F1=clear sequence / F2=mute pattern   
generic buttons= bugs the sequence*  

  **Step Selector :** each small square is a rest,each bold square is a gated step. The label underneath the sequencer is indicating the step note and octave. The blinking step outline tells which bar is being edited. When Aciduino is playing, the moving step outline is indicating which step is being played.  
     Default note velocity is 70, accented is 127. This can be defined in `/AciduinoV2/src/sequencer/setup.h`  
  *pot=select picth  
  shift+pot=select octave      
  F1= accent / F2=slide(gated step) or tie (rest) 
  generic buttons= trigger  / F2=mute pattern*  

  - **808 Sequencer Page**
  - 
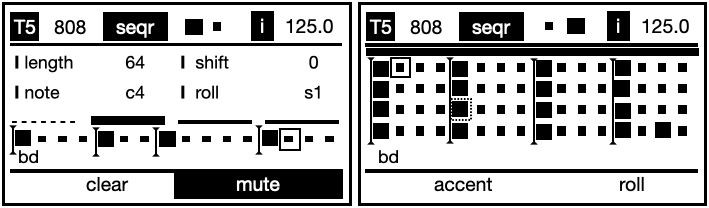
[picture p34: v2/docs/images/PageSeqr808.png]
   
 **Voice:** set the tonic note    
 **Note:** set the drum part midi note number  
 **roll:** set the roll type  
 **Step Sequencer Pot, Shift + Pot**  
808: [Pot] Changes notes [Shift + Pot] Changes Drum Voice  

---

### Generator page  

 **Fill:**  the percentage of activated steps in the sequence, this will only affect the next generated sequence  
  *pot=step number  
No function available  
generic buttons= decrementer / incrementer*  

  - **303 Generator Page**  
    
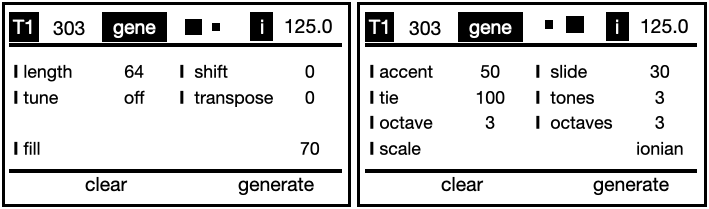
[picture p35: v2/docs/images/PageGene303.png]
 
   **Tune:** set the tonic note (off - C1 -> B1)  
  **transpose :** transpose the sequence  

 - **808 Generator Page**
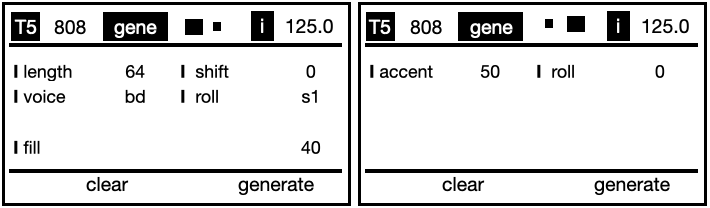
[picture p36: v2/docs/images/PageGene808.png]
   
 808: [Pot] Changes voice [Shift + Pot] Changes voice config(midi cc or cv port) 

---  

### Pattern page  

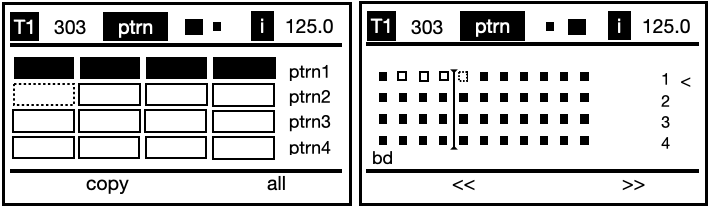
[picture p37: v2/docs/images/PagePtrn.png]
   
  *pot=no interaction here
F1=copy / F2=all
Shift+F1=save as / Shift+F2=save  
generic buttons= play selected pattern / play selected scene*  

--- 

### MIDI page  

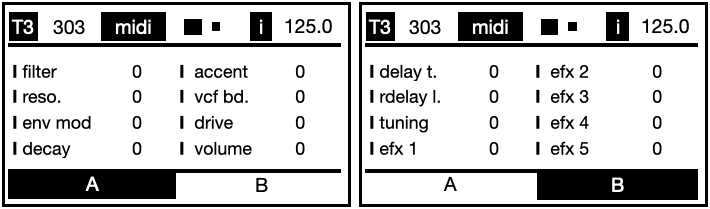
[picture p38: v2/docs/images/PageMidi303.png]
MIDI Sequencer Interface
   
 
 Labels and CC# are different 
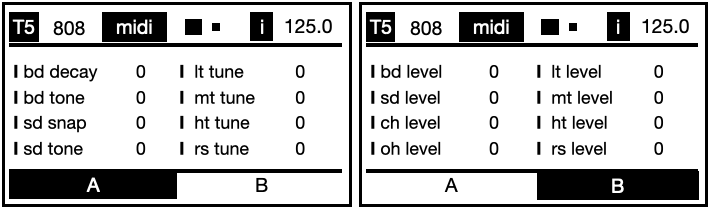
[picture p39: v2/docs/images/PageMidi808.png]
MIDI Sequencer Interface
    

 - **Midi CCs** they are sent on the selected Track MIDI channel, CC# and naming can be changed in in `/AciduinoV2/page_midi.ino` : look for     `midiControllerComponent.set303Control("filter", 74);`

---

## Support

Check the [official midilab website](https://midilab.co/)  for the latest news

For any inquiries or technical support, please open an [issue](https://github.com/midilab/aciduino/issues)

For some nice talking, ideas or questions you can say hi on our  [discord channel](https://discord.com/channels/1137685010967703582/1137685011416498236)

---
 2023 Aciduino.

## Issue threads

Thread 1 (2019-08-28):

FEATURE REQUEST (not an issue): Easy x0xheart integration with 8 note knobs and note display. Thanks in advance!

01GOD, 2019-08-28:
Hi,

Would be great to make this easy to use with the x0xheart project as a full sequencer. Add a nice little blue note display and 8 step knobs for notes.

Thanks in advance!

01GOD, 2019-08-28:
Oh I see. Here are some things found during research. (I don't have a
x0xheart handy yet)

Have a look at the "punkseq10" here. There is a build video.
https://www.whitefordresearch.com/products/punkseq10-preorder?variant=45657478407

Also look at this with a little display:
https://www.youtube.com/watch?v=emMyMncFpMk

Keeping it SIMPLE on the electronics build side is DEFINITELY recommended.
That is one thing that is really cool about this. Modding things in
software logic is much easier to handle later.

Adding a "7 segment display" or LCD (because OLED has ghosting issues) in
the center of that punkseq10 and adding slide and accent would be a nice
way forward.

Looking forward to trying an aciduino 2. Thanks in advance for making it an
awesome sequencer! Honestly the community really needs a proper DIY
sequencer for the x0xheart and MB33 Retro.

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

midilab, 2019-08-29:
This little display on the video is a OLED one, the same i was told you, but with less pixel space(128x32 vs 128x68). I had manage to work with that display without ghosting issues(most of the times it happens because of the shared interface of SPI or I2C with another subsystem), it works really nice and has a good visibility for night and day.

As soon as i have time to, i will try to finish the PCB for the aciduino v2, some changes like swap the arduino nano for a ardunio pro micro to have a USB/MIDI connection that will help people integrate computer setup with standalone acid basses, or even virtual acid basses on PC will be an easier setup option.

This project is part of a bigger project(not released yet) for a complete full multitrack DIY sequencer using arduino mega(16 tracks, 4 midi in/out, usb/midi, sdcard support for pattern save/load, pattern matrix remix - like ableton scene mode - and other goodies for sequencer dudes out there), just like a midibox seqv4 one.

My bad i had miss a MB33 deal last year... :( hope to get myself a xOxheart soon!

SeanTurner026, 2020-04-13:
> This project is part of a bigger project(not released yet) for a complete full multitrack DIY sequencer using arduino mega(16 tracks, 4 midi in/out, usb/midi, sdcard support for pattern save/load, pattern matrix remix - like ableton scene mode - and other goodies for sequencer dudes out there), just like a midibox seqv4 one.

Has this one come out yet? Otherwise, aciduino is a cool project! I've wanted to do something like this for a few years now

doctea, 2020-04-13:
Chiming in too because this is also one I have been hopefully waiting for? :)

midilab, 2020-04-13:
> > This project is part of a bigger project(not released yet) for a complete full multitrack DIY sequencer using arduino mega(16 tracks, 4 midi in/out, usb/midi, sdcard support for pattern save/load, pattern matrix remix - like ableton scene mode - and other goodies for sequencer dudes out there), just like a midibox seqv4 one.
>
> Has this one come out yet? Otherwise, aciduino is a cool project! I've wanted to do something like this for a few years now

The 8 tacks sequencer is not released yet, but it is sitting here with me, my personal sequencer for loop music nowdays.

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

midilab, 2020-04-13:
> Chiming in too because this (that is, the 'aciduino v2 pcb') is also one I have been hopefully waiting for? :)

Im just trying to get some time to continue my work on it, but for sure it will be released this year...
For now some drafts i came up so far for the PCB thing, getting smaller and easier to make, by using a OLED screen we can minimize the interface for a clean design(the CV Converters goes on the middle of protoboard)
I had pickup the arudino pro micro because of his in-built capatibilities to act as a standalone midicontroller also for USB on computer side(avoid the use of serial to midi converters on the way). So that said, we can easily integrate our CV modular setup with computers for clock sync and other goodies.

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

midilab, 2020-05-23:
Finished the final layout of aciduino V2.

On the empty middle we can chose go for:

* CV/GATE 2 channels 12bits
* MIDI Input

Still working on CV/Gate module...

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

01GOD, 2020-05-24:
Saw now. Nice! Thanks!

If I can get a x0xheart for a decent price, likely make one of these soon.

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

midilab, 2022-10-05:
First steps almost done.

Schematic is ready and the source code almost done.

The idea behind the minimal is to make it esiear to build but also to extend, here is where it goes the cv/gate request for modular that will be coded soon.

[https://github.com/midilab/aciduino/blob/aciduino_v2/AciduinoV2/aciduino_v2.png](aciduino v2 schematics)

midilab, 2022-10-14:
closing this issue since the release of aciduino 2 is comming.

first steps is the basic module, then you can extend it for more detent encoders or pots as you wish

Closed 2022-10-14.

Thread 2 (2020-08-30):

How do potentionmeters connect exactly?

seanturner026, 2020-08-30:
Hi,

Really think this is a cool project, but having difficulty finishing putting it together specifically with regards to the potentionmeters.

Can someone give me locations on the board where the connecting pieces go? E.g. `J3`.

The potentionmeters in the picture on the repo don't indicate where the connectors go.

The screenshot below from the video doesn't indicate where to connect exactly.
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

Any help with this would be amazing. Thanks.

midilab, 2020-08-31:
welcome aboard!

the fritzing schematic picture on the repo has the pinage, by taking a looking now its not so visual the way it compiles the final image version, so you're bring here a point.

the connections that fritzing software had created are over the potentiometer component, but you can see a pattern, blue(ground), gray(signal) and red(5v) from the left to rigth side on repo picture, and they are connected to the 3 pins of pontentiometers.

the potentiometer on the video image are different from the repo picture only by pins distance(those are easly found where i live, but the one on repo are most common avaliable across the globe).

but you can use the fritzing file on repository to check the schematic

midilab, 2020-10-20:
closing because of inactivity...

Closed 2020-10-20.

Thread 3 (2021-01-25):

303duino+aciduino = TD-303

Harvie, 2021-01-25:
Aciduno has 303 sequencer, 303duino has 303 synth. Why not combine these two to get full 303 experience?

https://github.com/midilab/aciduino
https://github.com/treisti/303duino

midilab, 2021-01-26:
looks like a great idea.

303duino makes use of mozzi library for audio sound. i left uClock(the bpm generator of aciduino) a commented code to make use of other timers(since mozzi makes use of timer1, the same as uclock), but never test along with mozzi library, but thats on my todo list.

I was asking myself how it sounds like, mozzi is a really good library, but how 303ish it can be?

maybe if a get some time to test the 303duino i can integrate booth.

Did you test it? can you make a audio or video so i can check how it sounds?

Harvie, 2021-01-26:
I have plans to test it, but i guess the sound mostly depends on output method you choose. Mozzi supports everything from pwm to external i2s dac.

midilab, 2021-01-26:
true, im working rigth now on aciduino v2, using teensy LC, that has a DAC builtin and mozzi support out-of-the-box. that can be a good choice for a cheap ARDUINO-303.

LeandroBarros, 2021-04-02:
I was thinking if it's possible to get MIDI clock input? That would make this even more useful to integrate with other gear in the studio.

midilab, 2021-04-03:
@LeandroBarros yes its possible, i didn't make aciduino v1 midi input ready to keep it low cost and simple to construct as possible(since midi input schematic involves a CI to be built).

You do have the option to buy a midi input board to use, i will need to code support for MIDI input clock to make it work.

But i totatly agree with you, MIDI input is a must have, thats why im working on aciduino V2 to overcome some of the limitations of V1, like MIDI input via USB for easy integration with computer setup like ableton live or whatever daw you're using and also keep it ready for a MIDI input board in case you want to use a native MIDI connection instead of MIDI/USB.

01GOD, 2021-04-03:
Better to make a clone of DELAY LAMA style sounds and add a sequence
randomization section similar to ABL 3.

Doing exact clones of analog on sound on an arduino doesn’t sound like a
fun adventure. Easier to clone digital style

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

midilab, 2022-10-14:
For now i will leave this request as a future possible implementation on the roadmap. thanks for the request, it always help the project to grow.

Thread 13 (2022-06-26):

Stuck in the programming part

ssid1, 2022-06-26:
I'm really interested in that sequencer but I haven't used arduino before. Now I'm finished the hardware part and don't know what to do next.Could you make a step-list about how to install? Little bit confused because the software part are too many files.

midilab, 2022-06-27:
hey ssid!

sure, i will workout a install guide on README.md file soon, i will let you know when done.

But in short you need to:

1. Install Arduino environment IDE.
2. Download latest release of aciduino zip file here: https://github.com/midilab/aciduino/releases
3. Unzip/Untar the release file and using Arduino IDE open the file aciduino-1.2.0/Aciduino/Aciduino.ino
4. With your board connected to PC and configured accorddly on Arduino IDE, press Sent button and wait untill you get a success message that the code was uploaded.

ssid1, 2022-06-27:
I'm using Mac OS system.

Is it because I connected pin 1 and 2? (I use the PCB broad and solder them all.)

ssid1, 2022-06-28:
No, I don't think there's anything changed after I reset, reconnect and restart the IDE.

midilab, 2022-06-28:
If you get thru all the steps and nothing happens you probably brick or burn your arduino.

Here it goes the list of steps at the link:

Here are some easy things that can often fix this error:

    Disconnect and reconnect the USB cable.
    Press the reset button on the board.
    Restart the Arduino IDE.
    Make sure you select the right board in Tools ► Board ►, e.g. If you are using the Duemilanove 328, select that instead of Duemilanove 128. The board should say what version it is on the microchip.
    Make sure you selected the right port in Tools ► Serial Port ►. One way to figure out which port it is on is by following these steps:
        Disconnect the USB cable.
        Go to Tools ► Serial Port ► and see which ports are listed (e.g. COM4 COM5 COM14).
        Reconnect the USB cable.
        Go back to Tools ► Serial Port ►, and see which port appeared that wasn't there before.
    Make sure digital pins 0 and 1 do not have any parts connected, including any shields.

If none of those work, you will want to try to isolate the issue by replacing things: try a different computer on the same arduino, try a different arduino on the same computer, and try using a different USB cable.

If the issue is with the computer:

    Double-check all computer-related issues in the "easy fixes" list above.
    Reinstall the IDE.
    Reinstall the drivers.

If the issue is with the Arduino:

    Double-check all board-related issues in the "easy fixes" list above.
    Make sure the microcontroller is seated correctly.
    You may need to [burn the bootloader](https://arduino.stackexchange.com/a/474/37).
    Replace the microcontroller if you have another one handy nearby.
    You may have bricked your Arduino. Sorry :(

midilab, 2022-07-05:
Closing by inactivity

Closed 2022-07-05.

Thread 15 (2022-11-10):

Aciduino V2B02 tempo menu

2b2a2t2, 2022-11-10:
tempo menu is broken, knob jumps automatically to 266 and up/down buttons are reversed

midilab, 2022-11-10:
thanks for reporting back!
it was a regression bug related to some changes on uCtrl recently. fixed on:
https://github.com/midilab/aciduino/commit/ef857940406705c0b1dbe404377a5cbef73d7e91

Closed 2022-11-10.

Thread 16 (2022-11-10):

V2B02 Generative page "octave" parameter

2b2a2t2, 2022-11-10:
octave parameter is not tweakable through buttons, works fine with knob but not with buttons
octaveS parameter works just fine

midilab, 2022-11-10:
great to have a beta tester around! thanks for reporting! i hope you're enjoying jamming with aciduino.
fixed on:
https://github.com/midilab/aciduino/commit/68f9bedcb1fc44458008ba650fac2aff68767a72

Soon i will make a release as beta2, waiting a bit more bugs and new features to come, but you can clone the latest changes on the repo to use the fixes. remember to init submodules. check README.md

2b2a2t2, 2022-11-14:
Hello and thanks for this work !
I tested Beta 3 and have nothing to report, a small fix when exiting the tempo menu (left and right buttons only work after pressing up or down a second time)
For the jamming part, a few more CCs would be much appreciated in the 808 live page, it would be nice to add a few pots or encoders, the generate button is a delight.

Closed 2022-11-10.

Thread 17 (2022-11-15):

Midi clock loss

2b2a2t2, 2022-11-15:
Hello,
using V2B03
I was able to reproduce the issue several times, using different pluggins, tweaking the resonance CC makes the aciduino crash, interface and sequencer are still running, controls are responding, but the DAW says the MIDI connection was lost, and my MIDI monitor does not receive information anymore from the aciduino.

midilab, 2022-11-15:
Any code changes made for this beta3 from your side? like new mici CC or number of tracks?

Are you using teensy lc or 3.6?

thanks for test and reporting!

2b2a2t2, 2022-11-16:
using a Teensy 3.2, the only code changes I made are the button pins (had 2 pairs of buttons reversed)
I no longer have this issue since I uncommented the extra CC in the live page and re-upladed the sketch in the teensy

midilab, 2022-11-16:
great! auto fix bugs!
the midi control object part has some flaws for extend that i intent to correct soon, i know it works on the beta but add or remove or creating another track without made some changes could lead to that freeze.

midilab, 2022-11-16:
what are the new cc you are looking for? drums?

2b2a2t2, 2022-11-17:
in the 808 engine, one CC per voice would be great !

Closed 2022-11-16.

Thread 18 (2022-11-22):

Generative "feature"

2b2a2t2, 2022-11-22:
Hello, enjoying this V2.0.0Beta 4 so far... except this little feature or bug :

if I use the generate button in one voice of one 808 engine, the generate settings are recorded so if I switch voice I still keep the last generate setting for this voice (I always inherit the previous fill, accent and roll setting if switch tho).

if I use the generate button in a 303 engine, the other 303 track only keeps the 1st setting page and the second page inherits from the previous track settings, so each time I change Track I lose all the fill, accent, slide, tie, tones, octave and octaves settings.

That being said, I like when switching to new 303 engine, the scale is kept from the previous and the length is reset to default

Would it be possible to increase the number of physical knobs like on V1 for a faster tweaking control ? I saw the code include encoders... Could I open a case for each question I have ? I don't want to pollute your project tho !

cheers

midilab, 2022-11-22:
Hi @2b2a2t2 ,

No problem at all about open a case for each question/request, thats what a beta is for and im always ears to the end-user and those UI/UX interactions thoughts are really important at that beta stage.

Its quite doable to make those changes(generative parmeters per track), but i haven't done so far because of memory limitations of teensy LC im working with. So my plan is to create some options for the enduser before compiling to choose what features he want, so we can go from a minimun features(teensy lc with a lite aciduino version) but fully functional to a more featuread(teensy 3.2/3.6/4.0/4.1) version with maybe sampler capatibilities and keep it choices for builders to get a cheaper teensy and get a working version.

So for now you can leave this request opened, i will implement that as soon as i get the options feature avaliable, so you can compile using teensy 3.2.

uCtrl allows you to extends up to 64 pots if you wish, just a matter of connect some 4051 and initiate the driver on uCtrl accordly. Those extensions are also on the roadmap for a modular like aciduino(a brain like the lite version we have so far and a module with lots of pots too or a module for CV/Gating).

midilab, 2022-12-09:
Implemented on [added generative per track parameters](https://github.com/midilab/aciduino/commit/638579dc2ba3932fe83113d9c2282152f62046cc)

Closed 2022-12-09.

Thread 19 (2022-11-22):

Pot question... or encoders

2b2a2t2, 2022-11-22:
Could there be a way to get 5-6 pots from V1 to match with on screen parameters ? or even better, encoder so we don't have value "jumps" when changing page/layer/engine ?

midilab, 2022-11-23:
yes thats possible, that will be a module to be released(wiring and code definitions option) to extend the lite basic version.

midilab, 2022-12-02:
two questions:

1- how often are your pot jumping when changing page/layer/engine?

I will write a pickbyvalue option for Pots but im not sure if that will be a good UX choice without testing.

2- Do you think a encoder could be a better option for values and midicc?

Im using a encoder instead of pot on uone and for general stuffs is quite better specially to avoid jumps, but for sure its a nigthmare to drive midi CC on acid 303 lines. thats the reason i choose a pot instead of encoder for the aciduino lite so people with minimal interface could experiment the acid twists of a pot.

But in case someone is going to use a extension of 4051 for more pots then i think could be a good option to let the user change it easly on the code side(as a #define).

midilab, 2022-12-09:
any news on this one?

Closed 2022-12-11.

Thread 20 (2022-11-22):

Hardware ideas

2b2a2t2, 2022-11-22:
to get some better feedback and fewer wires, could some lite neopixel  (or FASTLED) support be implemented to your library ?
Maybe this is stupid : switching for a SPI screen would free the I2C bus a bit and allow the use of MCP23017 so you can ideally link up to 8 of these and get 128 CV/triggers ?

midilab, 2022-11-23:
everything related to input/output extension is handle by uCtrl DIN and DOUT driver modules, there you can use to driver 595/165 shiftregisters for buttons/encoders and leds.

SPI is going for CV module and other subsystems, since the subsystem is shared i got really bad response from those SPI oled screens.

Closed 2022-12-11.

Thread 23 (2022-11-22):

UONE presentation ?

2b2a2t2, 2022-11-22:
What is this secret weapon that looks so attractive and that you display everywhere, are the PCB ready ? for sale somewhere ? can we create one of our own waiting for this to be available ? the code seems to imply multiplexing touch pins with a 4067, can we have some more details ? wiring diagram ? workflow ?

midilab, 2022-11-23:
this is a new series of uModular modules using uCtrl, aciduino will be the first app for uModular project.
https://github.com/midilab/uMODULAR

I will release the schematic and boards for selling soon, just need to finish the review of the uOne + base module + pots module + cv/gate module.

The code is using captouch driver of uCtrl(not released yet), and you rigth, capacitive touch using the pcb cooper area and 2x 4067 for 32 buttons.

Closed 2022-12-07.

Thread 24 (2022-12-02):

Aciduino v2 build question

copych, 2022-12-02:
Hello, @midilab ! It was great to know that somebody is making such cool stuff. Some time ago I wanted to build a handy "toy" with real pots and buttons to make some acid fun, like playing 2 basslines along with drums. I thought that I would find something more or less ready, but nope. Okay , guys all over the net have written a lot of DSP code: filters, delays, reverbs etc. So I tried to make it play on two cores of esp32. For the time being I have it working on a esp32 wrover with 4mb psram and an external DAC, and gonna make it available to public. It's midi driven, and could be a perfect pair for the aciduino2 (ok, not perfect, as it's far from 303 + 808 sound yet, but still fun). So the question is: how can I build Aciduino v2 for an Avr or ESP ? I am not a real coder, and #include \<functional\> makes me scared )

midilab, 2022-12-03:
hey @copych !

Im really curious about how it sounds, do you have a video or demo?

Aciduino v2 is based on uCtrl and uClock libraries, so far those libraries are ported to work with AVRs, Teensys and Seedstudio Xiao and the idea is to port to other platforms too, esp32 is not supported rigth now but it can be done. You can open a issue on uClock project asking for a esp32 port, since i dont have one sitting here with me probrably i will need your help tests and debug.

So bassicly after creating a support for esp32 on [uCtrl](https://github.com/midilab/uCtrl) and [uClock](https://github.com/midilab/uClock) you can use aciduino v2 arduino source code with any of the supported platforms(that has the minimun epprom and ram for aciduino v2 firmware).

Did you try any teensy >= 3? they have a nice audio library to create synths and i see a lot of guys out there doing some amazing sounding stuffs with it, maybe port your work for teensy can be a short path to the aciduino + sound engine?
There is a sample support too on teensy audio library too beside the really nice DSP stuff, so i plan to get a engine for sampler to be used along with 808 for those who need a standalone solution and later i got this TODO list to check how far i can go with teensy audio library dsp stuff to get a 303 sound from it.

copych, 2022-12-03:
Thanks for the reply, @midilab !
I'll try to record some sounds from the breadboard =)
As of Teensy, I am sure it's a great piece of gear, but only starting with v4.0 (600MHz), cause AFAIK v3.+ only gives 120MHz single core, which is less than ESP32 which has (2 x 240MHz cores). But looking at Teensy 4.+ we have price level ($70+) of a card-sized PC (OrangePI or similar) running @GHz.. So taking the price into account, I choose ESP32 ($10).
About the libraries, you have mentioned that AVR is supported, right? Should I just use library manager in Arduino IDE?

copych, 2022-12-03:
https://www.dropbox.com/s/tf3pz1pt6qpfezv/demo.wma?dl=0

copych, 2022-12-03:
https://github.com/copych/AcidBox uploaded src

midilab, 2022-12-03:
> Thanks for the reply, @midilab ! I'll try to record some sounds from the breadboard =) As of Teensy, I am sure it's a great piece of gear, but only starting with v4.0 (600MHz), cause AFAIK v3.+ only gives 120MHz single core, which is less than ESP32 which has (2 x 240MHz cores). But looking at Teensy 4.+ we have price level ($70+) of a card-sized PC (OrangePI or similar) running @GHz.. So taking the price into account, I choose ESP32 ($10). About the libraries, you have mentioned that AVR is supported, right? Should I just use library manager in Arduino IDE?

Actually teensy 4 is $23 dolars, kinda 2x the price of esp32 and 6.5x more powerfull for processing, so i guess its a winner for real horse power for DSP. Its a huge jump from 32bits to 64bits arch and it also contains a FPU and DSP extension embedded. Just imagine that the M8 tracker is based on a single teensy 4 then you can picture how low cost it is for the power it has for DSP.

[Teensy coremark](https://www.pjrc.com/store/coremark_barchart_t40_small.png)
[Teensy4](https://www.pjrc.com/store/teensy40.html)

Any way you got a point for 10 dolars ARM being a real low cost too. But teensy audio library can save you a lot of work on DSP side that on a long run project needs to be acountable too.

For uClock you can use Arduino library manager to install it from github, but the better current way of using is to put all libs inside /src folder of your arduino project, jsut following the AciduinoV2/src strcuture you will be good to go.

> https://www.dropbox.com/s/tf3pz1pt6qpfezv/demo.wma?dl=0 looping, mouse control 1cc at a time. )

The square wave is convincing! can you twist some filter around so i can get an idea of the filter quality.

> https://github.com/copych/AcidBox uploaded src

Hey great job! unfortally i dont have a esp32 to test it out. Open a issue as request for new platform esp32 to be supported on uClock then we have a start point to check if we can merge the 2 acid projects into a standalone diy acid box.

copych, 2022-12-04:
Thanks for the info! I'd surely prefer a Teensy for the price indicated, but unfortunately, the world is not ok lately, and I can't pay directly to the US, as well as they are probably not delivering to Russia. Buying from China or from 3rd party gives the price I've mentioned. About the filter, I'm not quite satisfied yet, and now experimenting with the one from the open303 bundle. Also there's one more in SoundPipe collection to test. Thanks again for the attention

midilab, 2022-12-05:
You got a point! I got same issues here, buy anything directly from US will cost me something around 3x the original price, the only way out is always to DIY as much as possible.

So in that way ESPs are avaliable for good prices all over the world, so its good to see projects like yours making use to the arm power to DSP some opensource noises and notes.

It would be great to follow the progress of your project with the filter research.

Open the issue i mention, there is already one opened for a new platform request, so maybe you can take a read to follow up with the help i need to port uClock and uCtrl to ESPs on the new issue.

copych, 2022-12-05:
Getting back to the matter, when I tried to compile in ArduinoIDE for Leonardo, I got the following
```
In file included from D:\xxx\arduino\AciduinoV2\src\uCtrl\uCtrl.h:75:0,
                 from D:\xxx\arduino\AciduinoV2\AciduinoV2.ino:39:
D:\xxx\arduino\AciduinoV2\src\uCtrl\module\page\page.hpp:33:10: fatal error: functional: No such file or directory
 #include <functional>
          ^~~~~~~~~~~~
compilation terminated.
exit status 1
Error compiling for board Arduino Leonardo.
```

midilab, 2022-12-05:
uCtrl needs a review for AVR since i added some new stuffs while working on aciduino teensy version, i will try to do it asap. It looks like functional is not available for AVRs, you can try to find the correlated include for this one to compile.

But in the mean time i can teel you that leonardo doesn't have the minimum ram and epprom to run aciduino v2.
I think the only AVR that can handle it is Mega2560.

midilab, 2022-12-05:
you also have the option to use aciduino v1 wich is can run on any AVR arduino based. but its only 303 sequencer with no oled screen.

copych, 2022-12-05:
Still trying to compile for AVR
```
name.c:5:10: fatal error: usb_names.h: No such file or directory
 #include "usb_names.h"
          ^~~~~~~~~~~~~
compilation terminated.
exit status 1
usb_names.h: No such file or directory

```

midilab, 2022-12-05:
you can delete name.c since its a teensy only usb midi driver initiation.

copych, 2022-12-05:
Oh I've got several pages of error output, you'd better look at it with your own eyes. I think that would be a bad idea to scroll all this output in here)

midilab, 2022-12-05:
you can create a gist for that i guess

midilab, 2022-12-05:
you need to comment the USE_USB_MIDI too, its a teensy option only, and ucomment USE_UART_MIDI

copych, 2022-12-05:
https://gist.github.com/copych/0ff0b755c5c8aa3fe3fcd09da66f5205
tried to disable both USE_USB_MIDI and USE_UART_MIDI, target is set to Mega

midilab, 2022-12-05:
Uhmmm..

Try to use this function(replace per the one on acid_ui_components.ino):

void genericOptionView(const char * title_char, String value, uint8_t line, uint8_t col, bool selected, bool large = false)
{
  String title(title_char);
  const uint8_t view_size = 12;
  uint8_t x=(col-1)*5, y=(line-1)*8;
  uint8_t value_col = large ? (view_size*2)-value.length()+1 : view_size-value.length();
  uCtrl.oled->display->drawBox(x+1, y, 1, 7);
  uCtrl.oled->print(title, line, col+1, selected);
  uCtrl.oled->print(value, line, col+value_col, selected);
}

copych, 2022-12-05:
https://gist.github.com/copych/c31840bc3af368172183562083dfe2ad

midilab, 2022-12-05:
doesn't look like those compile erros are using the function above

midilab, 2022-12-05:
One thing that could be done from your side until i push the changes is to replace all genericOptionView() calls over the code base changing the second argument to be passed to a String object before genericOptionView(somethign like change value_x per String(value_x), so it converts before goes to the function.

copych, 2022-12-06:
C:\Users\admin\AppData\Local\Temp\cccFAY5h.ltrans0.ltrans.o: In function `freeram':
E:\YandexDisk\arduino\AciduinoV2/page_welcome.ino:7: undefined reference to `sbrk'
collect2.exe: error: ld returned 1 exit status
exit status 1

midilab, 2022-12-06:
you can comment freeram() function and all references too, its a teensy function only.

midilab, 2022-12-14:
i will release a multi-arch version soon to support either teensy and avrs(with minimun memory specs).

do you have a video or audio of the current acidjukebox? looks interesting! you're about right, never hear about before this acid-banger.

copych, 2022-12-14:
i've just put a demo on the main page of the AcidBox repo. No buttons pressed, no knobs turned.

midilab, 2022-12-21:
> i've just put a demo on the main page of the AcidBox repo. No buttons pressed, no knobs turned.

Sounds promisor!

You can now build out of the box aciduino v2 for mega 2560 o beta 7 release:
https://github.com/midilab/aciduino/releases/tag/v2.0.0-beta7

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

copych, 2022-12-21:
Oh! Nice that the project moves on! I hope someday it'd be ported to ESP32 ) because of arduinos I only have ProMicro which is identical to Leonardo, but it won't allow to run your app (

midilab, 2022-12-21:
soon i guess, its on todo list already.

estufilla, 2023-11-18:
> you also have the option to use aciduino v1 wich is can run on any AVR arduino based. but its only 303 sequencer with no oled screen.

Is there any way that this can be explained? Been trying for 3 days straight to use a Uno or Leonardo (or Pro Micro) with Aciduino V1, but have been just literally impossible for me.

midilab, 2023-11-18:
The code is ready for arduino Nano, other AVR microcontrollers should work but maybe it needs some changes on code side to the specific arduino model, i cant tell since i've never try, one the things could be messing up its the EPPROM size differences on nano and leonardo, those part of the code needs to be ported to run fine. anyway, its on todo list, get leonardo running on acidunio v1 with usb midi support.

Closed 2022-12-21.

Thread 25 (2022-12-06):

V2 Beta 05 Navigation issue

2b2a2t2, 2022-12-06:
Hello,
 I'm having a strange behaviour on SEQR page 1 (left page), controls seem to be in the wrong order :

tune    | transpose
- - - -
[°°°°[°°°°[°°°°[°°°°
lenght | shift

I also cannot switch from tune to transpose or from lenght to shift, previous and next buttons act like up and down, they are only efficient in the bar or sequence item

It's the same in both 303 and 808 engines.

midilab, 2022-12-06:
its fixed on main branch, but not released as a beta yet, you can clone the repo and init him(init uCtrl and uClock libraries)

2b2a2t2, 2022-12-07:
Thanks ! Nice and quick !

Closed 2022-12-07.

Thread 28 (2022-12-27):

System Freeze in Seqr Page 2

2b2a2t2, 2022-12-27:
had the problem with every beta so far...
if the src/sequencer/setup, when the pattern length is modified for something above 64 steps, the second page UI is not designed for such a long pattern and makes the teensy unresponsive. Could a security implementation prevent from switching to the second page ?

midilab, 2022-12-29:
prevent to access the page is a bad UI/UX behaviour, a good solution will be finish the step grid to support more than 64 steps.

i will see what i can do for that matter.

midilab, 2022-12-30:
Any way until some changes go for release you can do that on page_sequencer.ino inside
...
} else if (subpage == 1) {
    //...
    //...
    if (!AcidSequencer.is303(_selected_track))
        uCtrl.page->component(stepSequencerComponent, 2, 1, true);
}

that way the stepsequencer will only showup as full size if its not a 808 track...

midilab, 2023-01-02:
implemented a support for up to 256 steps on 303 for UI.

https://github.com/midilab/aciduino/releases/tag/v2.0.0-beta9

Closed 2023-01-02.

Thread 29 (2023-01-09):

Seqr Page V2Beta10

2b2a2t2, 2023-01-09:
The second SEQR page when in a 808 engine is now a live play page ? I cannot move the select step box with arrows but I see the moving box, and pushing the on/off button for this step will only activate the step under the running box.
IT'S NOT A BUG IT'S A FEATURE !
this is actually simpler and quicker than navigating to the desired step, but a deletion would be a great implementation too !!

midilab, 2023-01-09:
That is actually an old feature, maybe from beta7 i guess... the original TB303 and TR808 all has this function, a TAP, soh you can record in realtime by tapping, for 303 you can twist the pot to change note while TAPing like crazy to get some great sequences too, it records the note the POT is poiting at the time, if you hold the button you get a longer note with TIE on each step while holding. For the 808 tap just put a note at the time you tap.

So for that function to be alive i need to sacrifice the other button that "deletes" but i made the other one as a switch state(press once, you put a note on selected, press again on a selected with note it deletes).

I really need sometime to write a proper manual with updates for new stuffs.

Other live focused feature like the TAP was the "last used midi control" on live page, once you get to you preffered control, you can change back to the mute page and use the control(change tracks wont change the pot either, he keeps the last used one for track and parameter).

Closed 2023-01-23.

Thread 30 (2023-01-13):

ESP32s2

copych, 2023-01-13:
Hello, @midilab , I'm trying now to run it on the ESP32S2 board, how do I set pins for OLED SDA and SCL?
Please, note that ESP32, ESP32S2, ESP32S3 and ESP32C3 are VERY different boards. They need different settings for cores and for pins...
Say, ESP32S2 only has just one core, has no FPU, has WiFi, but no BT, has just 2 UARTS, but has native USB support, including USB-OTG, while ESP32 has 2 cores, has FPU, has 3 UARTS, has WiFi+BT, but no built-in USB etc...

midilab, 2023-01-13:
Since its experimental support, im counting on the community to help testing, document or come up with solutions.

So in case you have more than one board for example and want to test it, you can document everything related to the port so we can add to the project(for example the tests you have done for the GPIOs i've updated at the schematics, but its always welcome an effort to pull changes on code or schematics when they come up).

By now everything related to drivers and devices are setup inside 1_uctrl.ino.

`//
// Display device
//
//U8G2_SSD1306_128X64_NONAME_F_HW_I2C u8g2(U8X8_PIN_NONE);
U8G2_SH1106_128X64_NONAME_F_HW_I2C u8g2(U8G2_R0, U8X8_PIN_NONE);
`
So you just need to comply with u8g2 driver usage and pinage setup. the uCtrl just uses the object of device instead of trying to configure it self, leading to the problem of a reduced portability.

copych, 2023-01-13:
ok, i'm just not familiar with u8g2 drivers, and esp32s2 seems not to have default i2c pins, so i need to assign them explicitly, that's why i ask.

midilab, 2023-01-13:
you can check they reference manual for that, i never had to change the default i2c before:
https://github.com/olikraus/u8g2/wiki/setup_tutorial

bassicly you just need to follow the manual and change the line for that on 1_uctrl.ino.

If you succeed, please create a pull request with the changes so i can add to the the codebase.

Ideally we should create a schematic for each of ESP32XXXX since it looks like we have different boards pinage. If you could copy the [one we have](https://github.com/midilab/aciduino/blob/master/v2/hardware/aciduino_v2-esp32.fzz) and make the modifications needed and rename it to the board name - like aciduino_v2-esp32s2.fzz - and pull that will be a great contribution. After that we need to find the FLAGS that identify each of these boards to make the code compile transparent for all boards we test so far.

copych, 2023-01-14:
Thanks for the link, I've managed to launch tha app on a ESP32-S2 (LOLIN S2 MINI), I'll send what I have later

Closed 2023-01-23.

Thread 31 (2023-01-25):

Nano

jaseat1, 2023-01-25:
hi, I'm really interested in building this, but would be great if it could run on a Nano instead of the mega. Is this possible?

jaseat1, 2023-01-25:
Thank you for the fast reply. Dam!I was hoping it would work on a nano, just to keep the project small, also only have nanos at the moment. Just makes a nicer project to have the screen aswell. Thank you.

midilab, 2023-01-25:
No problem at all!

For small option you can go for teensy 3.2 or 4.0 or even a ESP32. unfortally the only AVR avaliable so far that has the minimun flash and ram is Mega.

jaseat1, 2023-01-25:
I guess it would also work on a mega mini as they share the same chipset?

midilab, 2023-01-25:
Yes it should run fine! Its the same hardware in small size.

If it happens to you build it on top of it, please report back so i can add officially tested and supported by aciduino too.

Closed 2023-01-26.

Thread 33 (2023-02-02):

Leds wont work

riegerben, 2023-02-02:
Hi,
I soldered everything on pcb, after that i found out that my arduino nano was unable to be uploaded skeches to.
So i replaced it with a new one.
Im afraid i broke something in the pcb while desoldering old one.

Because leds wont work, but i connected midi out the another arturia sequencer and its controlling play/stop.

Also i didnt solder the knobs yet because i ordered wrong ones.

What do you i need to check in order to find out the problem?

Thank you very much and sorry for the noobish questions...

Closed 2023-02-03.

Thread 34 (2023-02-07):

Encoder acceleration

2b2a2t2, 2023-02-07:
Hello !
Having a lot of fun with my aciduino, I wanted to upgrade. I found 2*4051, I built a Pot16 module and selected
#define USE_CUSTOM_PINOUT
//#define USE_PROTOBOARD_PINOUT

changed the modules.h  page
 //#define USE_CHANGER_POT
  #define USE_CHANGER_ENCODER

uncommented
#define USE_POT_16

i get data from the pots, but if I disconnect the pot16 module, all 16 MIDI CC values get crazy (because the muxs are not connnected).
So i went back to the code and commented //#define USE_POT_16...

Could there be an option so we can switch pot16 on/off onboard ?
Also I now have both CHANGER_POT and CHANGER_ENCODER hooked on the device since the encoder is not really usable when the pot16 is not connected, it is much more convenient when tweaking options but MIDI CCs are so slow it reminds me of an Arturia's controller ;p !
Could you implement an acceleration setting for the encoder ?

PS : Also something weird : "Aciduino" is now "Teensy MIDI"... and I promise I didn't change name.c

midilab, 2023-02-09:
> Could there be an option so we can switch pot16 on/off onboard ?

What are your needs? how often do you connect and disconnect them?

> Also I now have both CHANGER_POT and CHANGER_ENCODER hooked on the device since the encoder is not really usable when the pot16 is not connected, it is much more convenient when tweaking options but MIDI CCs are so slow it reminds me of an Arturia's controller ;p !

That was the main reason behind a pot instead a encoder on the minimal version of aciduino v2, no matter the quality of your encoders, they will never ever going to behave like the old and good pot for midi cc changes and i really think they are unusable for the matter of midi cc, but the best for value changing.

I dont know if that will work, but did you try to enable both CHANGER_POT and CHANGER_ENCODER so you can make use of the most appropriated one when needed?

> Could you implement an acceleration setting for the encoder ?

I was expecting someone to complain about the speed, most machines i see fo far make use of shift to acceletare the pot change, could be an option for aciduino but there are places where shift+pot is used too so i need to check a good way of doing this, and i agree, its a needed to have the option to acceletare it.

> PS : Also something weird : "Aciduino" is now "Teensy MIDI"... and I promise I didn't change name.c

No idea about, but i guess thats something related to your side of teensyduino compiler setup(IDE update... midi options changed?)

2b2a2t2, 2023-02-14:
> What are your needs? how often do you connect and disconnect them?
well sometimes the aciduino is connected to the computer, sometimes it is connected to the phone, if I take the aciduino out for a quick jam on the phone I don't take the pots... ;p

> no matter the quality of your encoders, they will never ever going to behave like the old and good pot for midi cc changes
you could definitely try a midi fighter twister, feels just like a "real" pot, the code is on github https://github.com/DJ-TechTools/Midi_Fighter_Twister_Open_Source
(but they use a M74HC165M1R chip to count each encoder)
also take a look at Zynthian way of implementing encoders... their acceleration detection is pretty efficient and smooth (but they added some capacitors lately so they also may have changed the code)

midilab, 2023-02-19:
> you could definitely try a midi fighter twister, feels just like a "real" pot, the code is on github https://github.com/DJ-TechTools/Midi_Fighter_Twister_Open_Source
(but they use a M74HC165M1R chip to count each encoder)
also take a look at Zynthian way of implementing encoders... their acceleration detection is pretty efficient and smooth (but they added some capacitors lately so they also may have changed the code)

Thanks for the references! Good to know some devices that feels ok for Potting with a encoder.

uCtrl makes use of 74H165 too, but thats not the point for velocity or smoothness of changes. Its related mainly to the speed of reading wich takes use of cpu and it is running inside a ISR sharing processing time in a multiplexed kinda of way with other drivers, so we have a sort of limit(not explored yet) of how smooth changes can be using uCtrl.

Thats also related to the quality and resolution of the encoder, i dont have a good resolution one with me to test, but maybe we can try to figure out how to do it if you have one around and could test it.

> well sometimes the aciduino is connected to the computer, sometimes it is connected to the phone, if I take the aciduino out for a quick jam on the phone I don't take the pots... ;p

Originally i wrote the uCtrl and compose the uMODULAR modules to be able to be able to hotswap modules, so i can try to think of a way to enable that in a user friendly way for the next releases.

2b2a2t2, 2023-08-03:
I can test whatever code you want ! I also can provide the code I'm using if you wan't to give an eye...

midilab, 2023-08-03:
great! please show me the code you have tested so far and i will take a look at.

So this code you're using, how does it feels about the user interaction compared to the other gears you have and does good acceleration?

midilab, 2023-09-24:
closing issue and move it to [uCtrl](https://github.com/midilab/uCtrl/) roadmap.

Closed 2023-09-24.

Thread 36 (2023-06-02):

Step sequencer support

2b2a2t2, 2023-06-02:
Hello !
Would there be a simple way to add (in the setup file for example) a physical support for the 16 step sequencer (using a 4067 mux or several MPR121), we could declare an array for the step buttons independently of the hardware ?
the same for LEDs could we use WS2812 (one more cable per LED but uses only one GPIO pin)
thanks !

midilab, 2023-06-03:
Hi @2b2a2t2

> Would there be a simple way to add (in the setup file for example) a physical support for the 16 step sequencer (using a 4067 mux or several MPR121), we could declare an array for the step buttons independently of the hardware ?

Yes, this is the  generic 16 button/LED extension module to be released, there is already some code implemented on Aciduino, but it is not yet complete, but it follows the same idea of the 16-knob extension released, so now this module is already on the roadmap.

For the CIs, aciduino is based on uCtrl framework wich has his list of CIs and drivers avaliable to use, please take a look at the [documantion of uCtrl](https://github.com/midilab/uCtrl#din). The 4067 is only for Touch buttons(capacitive), for normal button matrix you should go for 74H165 and for the leds the 74H595, any other CIs is not avaliable at the moment and new support requests should be asked on [uCtrl](https://github.com/midilab/uCtrl) project it self.

But if you really want to play around, I have initiated the support for the step sequencer buttons matrix. The [uOne PCB](https://raw.githubusercontent.com/midilab/aciduino/master/v2/hardware/imgs/uone_umodular.jpg) currently utilizes it, although it may not be fully functional as intended since it is still under development.

Basically, I need to complete the user flow definitions for the generic 16-button/LED module for pages other than the step sequencer. Additionally, I need to incorporate shift presses, most likely for track selection.

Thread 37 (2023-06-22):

Compilation errors for Teensy 3.2

espcam, 2023-06-22:
Hi!
I'm filing issue after discussing it with author.
I tried to verify the code in Arduino IDE 1.8.19, Teensyduino 1.58, Teensy 3.2 board - it outputs the same errors no matter if i switch Serial, MIDI, MIDI + Serial modes. I used master branch, then Aciduino v2 rc1 - no big difference.
Main PC - Fedora 37, Kernel: 6.3.8-100.fc37.x86_64 , Arduino 1.8.19, Teensyduino 1.58. (compilation logs attached)
Windows laptop - got the same errors on Windows 8.1, Arduino 1.8.19, Teensyduino 1.58. (windows log attached)

[error_midi_mode.log](https://github.com/midilab/aciduino/files/11834674/error_midi_mode.log)
[error_midi-serial_mode.log](https://github.com/midilab/aciduino/files/11834675/error_midi-serial_mode.log)
[windows8.1_compilation.log](https://github.com/midilab/aciduino/files/11834676/windows8.1_compilation.log)

Steps to reproduce: open v2 rc1 project, connect the board and choose MIDI or MIDI + Serial USB mode, Teensy board is detected by default, choose Teensy port and press "Verify" button in Arduino IDE.

I'm ready to provide extra info if needed.

midilab, 2023-06-22:
Hi @espcam

Thanks for reporting and information about it.

Looking at the logs something really strange is happen, the compiler is trying to compile using AVR libraries of teensy instead of ARM ones.

`Using library Wire at version 1.0 in folder: /home/user/arduino-1.8.19/hardware/teensy/avr/libraries/Wire `

As you see looks like there is a problem with teensyduino libraries, as it is using AVR instead of ARM even if you select teensy 3.1/3.2 that is a ARM one.

So i would like to ask you to check your teensyduino installation and try to uptade to 1.56 that im aware of working well. then we can follow from there.

I'm using 1.56, but there is newer versions already, so please try to compile using the same as mine, if it works update to the latest and please tell me if it works either. so i can write at the docs the tested versions for correct compilation.

espcam, 2023-06-22:
Downloaded Arduino 1.8.19 again and installed Teensyduino 1.56 - Compilation succeeded.
I also tried to compile project for ESP32-S3, but had no luck on either versions of software. I'll attach error log for ESP32-S3 here for future research. My issue can be closed i guess, as I believe 1.58 will be also supported later on.
[ESP32-S3_error.zip](https://github.com/midilab/aciduino/files/11835906/ESP32-S3_error.zip)

midilab, 2023-06-22:
Great that it works! hope you have some acid fun with it.

By the way, so far i have only enable support for [this ESP32 board](https://github.com/midilab/aciduino/blob/master/v2/hardware/imgs/aciduino_v2-esp32_bb.png), so i cant tell if that will compile for others EPS32 for now.

But i really want to get both projects Acidbox and Aciduino on a single ESP32, as soon as i get some free time to work on it.

Closed 2023-06-22.

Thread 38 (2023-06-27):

unable to compile with the Arduino-IDE

Di3g0, 2023-06-27:
testet on archlinux with **arduino-ide_2.0.4_Linux_64bit.AppImage:**

```
/home/diego/develop/aciduino/v2/AciduinoV2/AciduinoV2/AciduinoV2.ino:61:10: fatal error: src/uClock/src/uClock.h: No such file or directory
   61 | #include "src/uClock/src/uClock.h"
      |          ^~~~~~~~~~~~~~~~~~~~~~~~~
compilation terminated.

exit status 1

Compilation error: src/uClock/src/uClock.h: No such file or directory
```

How to reproduce:
:$ git clone https://github.com/midilab/aciduino.git
:$ cd aciduino/
:$ git submodule update --init --recursive

then open the main file from "AciduinoV2.ino" with the arduino-ide

midilab, 2023-06-28:
Hi @Di3g0,

Thanks for the report.

Looking at the logs show me that you have a folder "AciduinoV2" inside the folder "AciduinoV2" wich is not the orignal folder structure of the project.

Try to delete your local aciduino repository and clone it again with submodule update.

If you're still getting problems with cloned version of repository you may try to use the [release pack](https://github.com/midilab/aciduino/releases/download/v2.0.0-rc1/aciduino-v2_rc1.zip) instead for compilation.

Di3g0, 2023-07-05:
sorry for the late reply.
I have tried your release pack but unfortunately had no success maybe you have a tip for me. I have attached the compiler errors as a file
[compiler-error.log](https://github.com/midilab/aciduino/files/11962428/compiler-error.log)

midilab, 2023-07-06:
What is the teensy model you are trying to compile for?

Di3g0, 2023-07-31:
hey, I'm just curious and wanted to ask you if you have already found a solution or workaround to this problem

midilab, 2023-08-01:
> What is the teensy model you are trying to compile for?
> What is the Teensyduino version you are using?

Since i couldn/t reproduce the problem im still waiting from your input to continue with the debug.

Di3g0, 2023-08-01:
Also tested now with Windows 10 x64 and a fresh Arduino 2.1.1 installation

OS:          Windows 10 ( fresh VM )/ Arch Linux 64
Arduino:  Arduino 2.1.1
Board:      Teensy 3.2

teensy:teensy-tools@1.58.0
teensy:teensy-compile@11.3.1
teensy:teensy-discovery@1.58.0
teensy:teensy-monitor@1.58.0
teensy:avr@1.58.1

on both setups I get the same error if i try to compile from the source
I have some time this weekend and will have a look at the compiler since your code doesn't seem to give any real errors but only warnings.
I'm still surprised that only my setup is affected by it.

this seems to be the crucial point
`
c:/users/diego/appdata/local/arduino15/packages/teensy/tools/teensy-compile/11.3.1/arm/bin/../lib/gcc/arm-none-eabi/11.3.1/../../../../arm-none-eabi/bin/ld.exe: c:/users/diego/appdata/local/arduino15/packages/teensy/tools/teensy-compile/11.3.1/arm/bin/../lib/gcc/arm-none-eabi/11.3.1/thumb/v7e-m/nofp\libc.a(libc_a-writer.o): in function `_write_r':
(.text._write_r+0x14): undefined reference to `_write'
collect2.exe: error: ld returned 1 exit status
`

Interplain, 2023-08-05:
Hi, Thanks for making this possible. Just as Di3g0 suggests i have the same issue. I tried with Arduino IDE 2.1.1 and Teensy 3.0 with the Release Pack i managed to install the 1.56.1 but can seem to select it from the board manager. Tried an older version of IDE 1.8.16  It compiles and shows the Hex uploader:
Opening Teensy Loader...
Sketch uses 92728 bytes (70%) of program storage space. Maximum is 131072 bytes.
Global variables use 9916 bytes (60%) of dynamic memory, leaving 6468 bytes for local variables. Maximum is 16384 bytes.
But has a lot of Orange text relating to errors:
warning: no return statement in function returning non-void [-Wreturn-type] many times relating to (engine.h)
would love to get this running.

midilab, 2023-08-05:
Hi @Interplain ,

`managed to install the 1.56.1 but can seem to select it from the board manager.`
Arduino 2 will only use the last installed version, it only shows to you the versions installed when you go to the screen to select a new one to install.

The problem is related to supported version, since arduino 2 and teensyduino evolute we will need check for break changes and other things. I will put on roadmap the arduino 2 support with new releases.

`would love to get this running.`
Looks like you already have, since you compile without errors(dont mind about the warnings). You can go and try your compiled version with arduino 1.8 and teensyduino 1.56(wich now is the supported versions of aciduino).

Please let me know about!

Interplain, 2023-08-05:
That's great, thanks for the reply. I tried it with the ESP-Vroom-32 but it failed to compile. So i have a Teensy 4.0 on its way today. Thing is i have all the part and tried with the Vroom board. Confident it will work now you told me that the Orange warnings are nothing to worry about.

midilab, 2023-08-05:
Do you mind to share the compile errors of ESP32? also all the setup you made with versions and so on?

So far i have release a experimental support for those boards but no one had test so far to my knowledge, i was able to compile and run the interface without problems but no extensive use to know if it fully works as expected.
here it is the schematics for that board: https://raw.githubusercontent.com/midilab/aciduino/master/v2/hardware/imgs/aciduino_v2-esp32_bb.png

Interplain, 2023-08-05:
Yeah sure, give me a few minutes. Would like help you in what way i can. my email is Interplain1@gmail.com can you delete. after reading. i dont want my email everywhere. https://soundcloud.com/interplain

Interplain, 2023-08-05:
Thank you for the reply. OK, using the DOIT ESP32 DEVKIT V1 in the
Aurduino IDE 2.0

I compile and I get this.

C:\Users\inter\Documents\Arduino\v2\AciduinoV2\1_uctrl.ino: In function
'void uCtrlSetup()':
C:\Users\inter\Documents\Arduino\v2\AciduinoV2\1_uctrl.ino:136:19: error:
'NAV_SHIFT_PIN' was not declared in this scope
   uCtrl.din->plug(NAV_SHIFT_PIN);
                   ^~~~~~~~~~~~~
C:\Users\inter\Documents\Arduino\v2\AciduinoV2\1_uctrl.ino:145:19: error:
'NAV_FUNCTION1_PIN' was not declared in this scope
   uCtrl.din->plug(NAV_FUNCTION1_PIN);
                   ^~~~~~~~~~~~~~~~~
C:\Users\inter\Documents\Arduino\v2\AciduinoV2\1_uctrl.ino:147:19: error:
'NAV_FUNCTION2_PIN' was not declared in this scope
   uCtrl.din->plug(NAV_FUNCTION2_PIN);
                   ^~~~~~~~~~~~~~~~~
C:\Users\inter\Documents\Arduino\v2\AciduinoV2\1_uctrl.ino:149:19: error:
'NAV_GENERAL1_PIN' was not declared in this scope
   uCtrl.din->plug(NAV_GENERAL1_PIN);
                   ^~~~~~~~~~~~~~~~
C:\Users\inter\Documents\Arduino\v2\AciduinoV2\1_uctrl.ino:151:19: error:
'NAV_GENERAL2_PIN' was not declared in this scope
   uCtrl.din->plug(NAV_GENERAL2_PIN);
                   ^~~~~~~~~~~~~~~~
C:\Users\inter\Documents\Arduino\v2\AciduinoV2\1_uctrl.ino:153:19: error:
'NAV_RIGHT_PIN' was not declared in this scope
   uCtrl.din->plug(NAV_RIGHT_PIN);
                   ^~~~~~~~~~~~~
C:\Users\inter\Documents\Arduino\v2\AciduinoV2\1_uctrl.ino:155:19: error:
'NAV_UP_PIN' was not declared in this scope
   uCtrl.din->plug(NAV_UP_PIN);
                   ^~~~~~~~~~
C:\Users\inter\Documents\Arduino\v2\AciduinoV2\1_uctrl.ino:155:19: note:
suggested alternative: 'NOT_A_PIN'
   uCtrl.din->plug(NAV_UP_PIN);
                   ^~~~~~~~~~
                   NOT_A_PIN
C:\Users\inter\Documents\Arduino\v2\AciduinoV2\1_uctrl.ino:157:19: error:
'NAV_DOWN_PIN' was not declared in this scope
   uCtrl.din->plug(NAV_DOWN_PIN);
                   ^~~~~~~~~~~~
C:\Users\inter\Documents\Arduino\v2\AciduinoV2\1_uctrl.ino:157:19: note:
suggested alternative: 'NOT_A_PIN'
   uCtrl.din->plug(NAV_DOWN_PIN);
                   ^~~~~~~~~~~~
                   NOT_A_PIN
C:\Users\inter\Documents\Arduino\v2\AciduinoV2\1_uctrl.ino:159:19: error:
'NAV_LEFT_PIN' was not declared in this scope
   uCtrl.din->plug(NAV_LEFT_PIN);
                   ^~~~~~~~~~~~
C:\Users\inter\Documents\Arduino\v2\AciduinoV2\1_uctrl.ino:159:19: note:
suggested alternative: 'NOT_A_PIN'
   uCtrl.din->plug(NAV_LEFT_PIN);
                   ^~~~~~~~~~~~
                   NOT_A_PIN
C:\Users\inter\Documents\Arduino\v2\AciduinoV2\1_uctrl.ino:217:19: error:
'CHANGER_POT_PIN' was not declared in this scope
   uCtrl.ain->plug(CHANGER_POT_PIN);
                   ^~~~~~~~~~~~~~~
C:\Users\inter\Documents\Arduino\v2\AciduinoV2\1_uctrl.ino:217:19: note:
suggested alternative: 'CAN_BRP_MIN'
   uCtrl.ain->plug(CHANGER_POT_PIN);
                   ^~~~~~~~~~~~~~~
                   CAN_BRP_MIN
C:\Users\inter\Documents\Arduino\v2\AciduinoV2\acid_ui_components.ino: In
member function 'virtual void TopBar::view()':
C:\Users\inter\Documents\Arduino\v2\AciduinoV2\acid_ui_components.ino:212:29:
error: invalid conversion from 'const uint8_t*' {aka 'const unsigned
char*'} to 'uint8_t*' {aka 'unsigned char*'} [-fpermissive]
           uCtrl.oled->print(SUBPAGE_SELECTED, 1, i+9);
                             ^~~~~~~~~~~~~~~~
In file included from
C:\Users\inter\Documents\Arduino\v2\AciduinoV2\src\uCtrl\uCtrl.h:41,
                 from
C:\Users\inter\Documents\Arduino\v2\AciduinoV2\AciduinoV2.ino:66:
C:\Users\inter\Documents\Arduino\v2\AciduinoV2\src\uCtrl\module\oled\oled.hpp:62:30:
note:   initializing argument 1 of 'void
uctrl::module::Oled::print(uint8_t*, uint8_t, uint8_t, bool)'
         void print(uint8_t * bitmap8, uint8_t line, uint8_t col, bool
do_blink = false);
                    ~~~~~~~~~~^~~~~~~
C:\Users\inter\Documents\Arduino\v2\AciduinoV2\acid_ui_components.ino:214:29:
error: invalid conversion from 'const uint8_t*' {aka 'const unsigned
char*'} to 'uint8_t*' {aka 'unsigned char*'} [-fpermissive]
           uCtrl.oled->print(SUBPAGE, 1, i+9);
                             ^~~~~~~
In file included from
C:\Users\inter\Documents\Arduino\v2\AciduinoV2\src\uCtrl\uCtrl.h:41,
                 from
C:\Users\inter\Documents\Arduino\v2\AciduinoV2\AciduinoV2.ino:66:
C:\Users\inter\Documents\Arduino\v2\AciduinoV2\src\uCtrl\module\oled\oled.hpp:62:30:
note:   initializing argument 1 of 'void
uctrl::module::Oled::print(uint8_t*, uint8_t, uint8_t, bool)'
         void print(uint8_t * bitmap8, uint8_t line, uint8_t col, bool
do_blink = false);
                    ~~~~~~~~~~^~~~~~~
C:\Users\inter\Documents\Arduino\v2\AciduinoV2\midi.ino: In function 'void
midiSetup()':
C:\Users\inter\Documents\Arduino\v2\AciduinoV2\midi.ino:36:3: error:
'usbMIDI' was not declared in this scope
   usbMIDI.begin();
   ^~~~~~~
C:\Users\inter\Documents\Arduino\v2\AciduinoV2\midi.ino: In function 'void
midiOutHandler(uint8_t, uint8_t, uint8_t, uint8_t, uint8_t)':
C:\Users\inter\Documents\Arduino\v2\AciduinoV2\midi.ino:53:3: error:
'usbMIDI' was not declared in this scope
   usbMIDI.send(msg_type, byte1, byte2, channel+1, 0);
   ^~~~~~~
C:\Users\inter\Documents\Arduino\v2\AciduinoV2\midi.ino: In function 'void
sendMidiClock()':
C:\Users\inter\Documents\Arduino\v2\AciduinoV2\midi.ino:63:3: error:
'usbMIDI' was not declared in this scope
   usbMIDI.sendRealTime(usbMIDI.Clock);
   ^~~~~~~
C:\Users\inter\Documents\Arduino\v2\AciduinoV2\midi.ino: In function 'void
sendMidiStart()':
C:\Users\inter\Documents\Arduino\v2\AciduinoV2\midi.ino:72:3: error:
'usbMIDI' was not declared in this scope
   usbMIDI.sendRealTime(usbMIDI.Start);
   ^~~~~~~
C:\Users\inter\Documents\Arduino\v2\AciduinoV2\midi.ino: In function 'void
sendMidiStop()':
C:\Users\inter\Documents\Arduino\v2\AciduinoV2\midi.ino:81:3: error:
'usbMIDI' was not declared in this scope
   usbMIDI.sendRealTime(usbMIDI.Stop);
   ^~~~~~~
In file included from
C:\Users\inter\Documents\Arduino\v2\AciduinoV2\src\sequencer\engine_303.h:33,
                 from
C:\Users\inter\Documents\Arduino\v2\AciduinoV2\src\sequencer\acid_sequencer.h:36,
                 from
C:\Users\inter\Documents\Arduino\v2\AciduinoV2\AciduinoV2.ino:71:
C:\Users\inter\Documents\Arduino\v2\AciduinoV2\midi.ino: In function 'void
sendMidiCC(uint8_t, uint8_t, uint8_t)':
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

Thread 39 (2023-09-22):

V2 MidiExternalSync

canetisfluctus, 2023-09-22:
Hi,

has anyone managed to get MIDI_STANDARD(0) working in version 2, so not USB_MIDI but MIDI for use with 5 pin connector? Or even better, has anyone manage to add a CV/Gate output code to Aciduino? I would appreciate any help!

PS: I'm trying to get Aciduino working with a VCO. I have a Midi to CV module ready to convert the midi signals as well.

Thanks in advance.

Best,

midilab, 2023-09-23:
Yes, I'm using MIDI output, and by default, all platforms come configured with 1 Serial port for MIDI in/out.

For Teensys and ESP32, it will be Serial1.
For Arduino Mega, it will be Serial3.

You can search the internet for instructions on how to create and connect the circuit and the correct Serial pins depending on your arduino board. The output circuit is quite simple, typically requiring only three resistors. However, the input schematic is more complex as it involves an Optocoupler IC. Alternatively, you can find ready-to-use MIDI boards with Serial input/output online, which can be a cost-effective and convenient option.

Please keep in mind that the schematic will vary depending on the microcontroller you are using due to differences in working voltage.

For Arduino Mega, which operates at 5V, you can use this schematic: [https://github.com/midilab/uMODULAR/blob/master/lib/midi-io-5v.pdf](uModular 5v MIDI module)

For Teensys and ESP32, which use a 3.3V serial connection, you will need to search online for a MIDI schematic compatible with these devices.

I have plans to add support for CV/Gate on the roadmap, but I currently lack any CV/Gate devices or modular equipment for testing. This is the primary reason I haven't implemented anything related to that yet.

Closed 2023-09-27.

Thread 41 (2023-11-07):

USB-MIDI settings

hugoescalpelo, 2023-11-07:
Which are the baud, data bits, parity and stop bits of USB-MIDI in Aciduino V2?

I built an Aciduino V2 for protoboard with an ESP32 DevKit, the only change I've made to the code was set the GPIO34 because my model does not have GPIO0 external. I am trying connect it to Ableton Live in Windows. For this I use [hairless-midi-serial](https://projectgus.github.io/hairless-midiserial/) and [loopMIDI](https://www.tobias-erichsen.de/software/loopmidi.html).

It kinda sounds at baudrate:19200, databits:8, parity:none, stop bits:1, flow contorl:none and send this error: +7.473 - Warning: got a status byte when we were expecting 1 more data bytes, sending possibly incomplete MIDI message 0x82.

I tried default settings, clearing all notes and then leaving just a simple pattern of 8 notes in 303, and playing the same pattern as the videos, but not good results.

I tried to read all code and documentation from V1 to usb-midi definitions for uCtrl but didnt understand enough.

Please, help.

copych, 2023-11-08:
@hugoescalpelo default settings for Hairless are 115200, no flow control. It's in the "Getting started" section of the page you supplied.

midilab, 2023-11-08:
> Which are the baud, data bits, parity and stop bits of USB-MIDI in Aciduino V2?

For ESP32 family devices, there is native USB/MIDI support available for those that have TynUSB out-of-the-box support. However, Looks like your ESP32 does not have native support, you'll need to use a Hairless bridge, which it seems you are currently attempting to do.

The Aciduino V2 initializes the MIDI interface to be used as a real MIDI port, based on the Arduino MIDI library, in the file 1_uctrl.ino, line 28 on last git commit:

`...
#else
    MIDI_CREATE_INSTANCE(HardwareSerial, Serial1, MIDI1);
...`

So in this case you need to make sure the usb port of your ESP32 is Serial1, otherwise just change to the correct one.

After confirming the correct Serial port, you'll need to change the baud rate, which is automatically set by the MIDI library to 31250 (MIDI Standard definition), to match the one you intend to use on your computer. If you are working with Hairless, you can set it to 115200.

To do this, add the following line to the very end of your setup() function in the AciduinoV2.ino file:

`Serial1.begin(115200);`

Make sure Serial1 is the one on usb port side of your ESP32, otherwise change it accordly, and make sure that you're adding this line to the very end of setup() call on file AciduinoV2.ino.

Hope it helps! let me know!

hugoescalpelo, 2023-11-23:
It worked!

Sorry for the delay, executive disfunction attacked. I just tried adding the `Serial.begin(115200);` at release commit `b7aa2ee` (sep 4) and it worked. Hairless MIDI does not send any more errors :D

I will try to connect to Ableton Live and then with commit `daa7b40`, I think that's the one you mentioned. I'll keep you posted.

Do you want yo see my circuit? I hope you like it: [link](https://www.instagram.com/p/CzU3j41Op77/)

Thank You!

midilab, 2023-11-27:
Looks great! any songs or jams made on this one?

hugoescalpelo, 2023-12-08:
Yes! I have this demonstration!!

https://www.instagram.com/reel/C0nAs_hujp8/?utm_source=ig_web_copy_link&igshid=MzRlODBiNWFlZA==

Closed 2023-11-22.

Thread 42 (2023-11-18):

Aciduino V1 in Leonardo

estufilla, 2023-11-18:
Hi and sorry for asking something probably obvious but, I've read everything about midilab GH and still can't find a way. Is it possible to use a Leonardo for V1? And V2? Or a UNO?

midilab, 2023-11-18:
Hi @estufilla ,

Aciduino V1 is built on nano only, i have plans to port it to leonardo soon so we can have native usb midi port on aciduino V1, unfortunally leonardo cant handle aciduino v2 because of memory limitations.

We are always trying to port to different plataforms and now the V2 has support for arudino mega, all teensy arms and some esp32.

estufilla, 2023-11-18:
Hey!
Fast and concise answer, the best ones! Sorry about writing in the other closed post, but was the most "resembling" thing I was searching for. I'm extremely new to coding and such, and I was getting truly frustrated. Been trying for a few days :D

I somehow made it "work" in the Uno one. Everything worked as MIDI-Serial but anything related with the tempo. I get some errors when uploading the code, still uploads it and "works". Something uClock related.

`C:\Users\+++\Desktop\aciduino-master\aciduino-master\v1\Aciduino\uClock.cpp: In member function 'void umodular::clock::uClockClass::handleTimerInt()':
C:\Users\+++\Desktop\aciduino-master\aciduino-master\v1\Aciduino\uClock.cpp:358:27: warning: invalid conversion from 'volatile uint32_t* {aka volatile long unsigned int*}' to 'uint32_t* {aka long unsigned int*}' [-fpermissive]
     onClock96PPQNCallback(&internal_tick);
                           ^~~~~~~~~~~~~~
C:\Users\+++\Desktop\aciduino-master\aciduino-master\v1\Aciduino\uClock.cpp:363:29: warning: invalid conversion from 'volatile uint32_t* {aka volatile long unsigned int*}' to 'uint32_t* {aka long unsigned int*}' [-fpermissive]
       onClock32PPQNCallback(&div32th_counter);
                             ^~~~~~~~~~~~~~~~
C:\Users\+++\Desktop\aciduino-master\aciduino-master\v1\Aciduino\uClock.cpp:366:29: warning: invalid conversion from 'volatile uint32_t* {aka volatile long unsigned int*}' to 'uint32_t* {aka long unsigned int*}' [-fpermissive]
       onClock16PPQNCallback(&div16th_counter);
                             ^~~~~~~~~~~~~~~~
C:\Users\+++\Desktop\aciduino-master\aciduino-master\v1\Aciduino\uClock.cpp:374:29: warning: invalid conversion from 'volatile uint32_t* {aka volatile long unsigned int*}' to 'uint32_t* {aka long unsigned int*}' [-fpermissive]
       onClock32PPQNCallback(&div32th_counter);
                             ^~~~~~~~~~~~~~~~
Sketch uses 14108 bytes (43%) of program storage space. Maximum is 32256 bytes.
Global variables use 715 bytes (34%) of dynamic memory, leaving 1333 bytes for local variables. Maximum is 2048 bytes.
`

Anyhow, thank you and I will try to learn as much as possible.

midilab, 2023-11-21:
I'd personaly runs my aciduino v2 on a arduino mega, more than enough for aciduino v2 needs, ESP32 is somehow still experimental since its a total different archtecture it demands more work to port and test. so far not extensively tested out there. But beta testers are always welcome too! In other words, a arduino mega will work out of the box, esp32 you migth need to adpat, read, change, debug or code something new depending on the board. not garantee at all! but a work in progress...

estufilla, 2023-11-22:
Nice thanks!

So a Mega Mini and an ESP32, so I can learn and help.

Could you give me any hint on the compile errors? As said, with a hint or two so I could go on my own way and do it myself.

Either way, thank you again!

midilab, 2023-11-27:
you can get some help on midilab discord server: https://discord.gg/gtKWj7Hg
to avoid get out of topic im closing this issue.

Closed 2023-11-27.

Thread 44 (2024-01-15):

3D printed Case

hugoescalpelo, 2024-01-15:
Is it possible to join as collaborator?

I designed a 3D printed case for perforated prototyping PCB and I want to collaborate.

Also, I'm designing a dedicated PCB for Aciduino V2 and in the next weeks I'm also designing a 3D printed case for that circuit.

midilab, 2024-01-18:
hi @hugoescalpelo

sure you can! please do it via pull request, so we can use the space to thread discussion before merge.

midilab, 2024-01-21:
You can send some ideas and photos here before do a pull or join discord to discuss about it, there are other people already doing aciduinos with plenty of ideas too, maybe a open discussion will benefit everybody.
https://discord.gg/JjDs28NS

hugoescalpelo, 2024-01-30:
Thank you! Sorry for the delay. The discord link is expired.

midilab, 2024-01-30:
> Thank you! Sorry for the delay. The discord link is expired.

no worries dude! https://discord.gg/EzbaPqwCJG

Closed 2024-03-20.

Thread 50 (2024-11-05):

Steps to compile in Arduino IDE

copych, 2024-11-05:
Please, specify steps to compile Aciduino v2 in Arduino IDE.
Either I use folder from the master, or use the folder structure from the 2.0.0 release, I get the errors complaining on missing .h files.
I suppose that I do something wrong, so I better ask here for the instructions.
Also, please, can you advice if your code runs on just one core of the ESP32 MCU?

midilab, 2024-11-06:
hey @copych ,

If you follow the [download steps](https://github.com/midilab/aciduino/tree/master/v2#download) on readme you should be fine.

One thing missing on README is the current supported version of esp32 arduino core.

The last know to work is the [espressif core](https://docs.espressif.com/projects/arduino-esp32/) version 2.0.18

There is a [pull request](https://github.com/midilab/uClock/pull/46) for the core update that will be soon integrated.

Try with the mentioned version of espressif. If the problems persist, please send me the errors and some environment information:

Arduino IDE version:
ESP32 Module:
Download method used:

copych, 2024-11-06:
UPD: deleted ArduinoBLE from the `libraries` folder? now it compiles for ESP32 DevBoard.

Is there a way to compile for ESP32S3 ???
The matter is I've managed to fit the whole AcidBox synth (2 x 303 and a drumSampler + FX) into a single ESP32S3's core0, so core1 is free to run all the control routines.

midilab, 2024-11-06:
Any board that is not compiling should be investigate to create the correct port(ESP32 variations).

If DevBoard is not compiling with BLE we should guard it via macro to allows this version to run without BLE for example.

If you could share the board and compile errors(per board) we can try to manage some sort of port for specific esp32 models.

copych, 2024-11-06:
ESP32-S3 errors https://gist.github.com/copych/317927c757589ac1ff0ce62c578f4827

copych, 2024-11-06:
just in case, if you want to differentiate between ESP32 and ESP32S3 at compile time, you'd rather use something like this
```
#if defined(CONFIG_IDF_TARGET_ESP32S3)
// code for ESP32-S3 based boards
#elif defined(CONFIG_IDF_TARGET_ESP32)
// code for ESP32 based boards
#endif
```

and a fork for ESP-Arduino core versions:
```
#if (ESP_ARDUINO_VERSION_MAJOR < 3)
// 2.x.x version code
#else
// 3.x.x version code
#endif
```

midilab, 2024-11-08:
Thanks for the macros needed.

Looks like the problem with S3 is the BLE(you can remove it!) and the midi-usb support.

this usb-midi support were never tested because i dont own a S3, you need to enable midi usb support for S3 on IDE i guess before try to compile so espNativeUsbMidi will be avaliable to init usb midi stack.

I will try to integrate the macro setup asap.

midilab, 2024-11-09:
So i find the error for esp32s3:

the ports/esp32/wroom.h have a commented section that defines the usb midi object.

// in case we got USB native mode support builtin, use it! note the case of wroom, keep this setup for later other boards
//#if defined(CONFIG_TINYUSB_ENABLED)
//ESPNATIVEUSBMIDI espNativeUsbMidi;
//MIDI_CREATE_INSTANCE(ESPNATIVEUSBMIDI, espNativeUsbMidi, MIDI1);
//#endif

try to comment out it!

copych, 2024-11-14:
Hello, thanks for the feedback. I've copied wroom.h to s3.h and modified as you pointed.
Here are the errors:
https://gist.github.com/copych/b47cf8dc025e32c524e9b592141eb790

midilab, 2024-11-14:
The error is related to BLE-MIDI scope name clashes. You can remove BLE-MIDI and any reference from the code, it was a proof of concept implementation but its so lame for midi messages, maybe usable for CC messages but still, i think i will remove completly or leave it as a option macro to enable it.

copych, 2024-11-14:
I continue with the release ver.
errors: https://gist.github.com/copych/42e0f22c1ce68a4870d5f9a1dc19c75e

midilab, 2024-11-16:
hey @copych ,

I made some changes and some pull requests for newer usage of espressif arduino core esp32 that compiles now on S3, all the code is inside develop branch:

```console
you@acidlab:~$ git clone https://github.com/midilab/aciduino.git
you@acidlab:~$ cd aciduino/
you@acidlab:~$ git checkout develop
you@acidlab:~$ git submodule update --init --recursive
```
I have organized the esp32 ports and created a s3 file that compiles fine, but never tested before, so please report back so we can try to start a new esp32 model support on aciduino.

You may need to adpt the s3.h file for pinage based on your board pinout map.

copych, 2024-11-18:
Hi @midilab
I have tried to compile but failed again.
I have upgraded to ESP-Core v.3.0.7 and firstly it gave this
```
name.c:5:10: fatal error: usb_names.h: No such file or directory
    5 | #include "usb_names.h"
      |          ^~~~~~~~~~~~~
compilation terminated.
exit status 1
usb_names.h: No such file or directory
```
To my mind this shouldn't have happened because of the guard ```#if defined(TEENSYDUINO) && defined(USB_MIDI)``` but it spawned even aftar I have emptied the ```name.c``` in the root of the project and even after deleting it. I've searched through the sources and found those 3 examples for Teensy which also contained ```name.c```, so I deleted them thou it was already beyond my understanding. After that it started scrolling this:
https://gist.github.com/copych/c2ab84a5726203367a3f3d390bb188e6
It seems that I should separate the project files from all the stuff supplied, cause Arduino seems to be recursively collecting all the files in the AciduinoV2 folder, whish is somehow confirmed by unusually long building time.

midilab, 2024-11-18:
What is the board name you are trying to compile for? (the name selected on arduino dropdown menu for board)

copych, 2024-11-18:
```Esp32s3 dev module```

midilab, 2024-11-18:
There is the examples folder along with uClock library inside src directory of AciduinoV2 that needs to be deleted, i will add to the README.md as reference.

I have no problems compiling here with the board you're using, did you change any board configuration?
Arduino 2.3.3 and espressif esp32 arduino core 3.0.7.

copych, 2024-11-18:
Now, with removed examples, I get this
https://gist.github.com/copych/accb357d49617aef1e09035a0fd34a43

midilab, 2024-11-18:
It looks like you are using main branch instead of develop.

Try to follow the develop checkout instructions again and make sure you are on develop branch before init the library dependencies.

copych, 2024-11-18:
I manually reconstructed locally what you have in `develop`, and still I have
```
In file included from D:\_CLOUD_\arduino\AciduinoV2\AciduinoV2.ino:39:
D:\_CLOUD_\arduino\AciduinoV2\src\ports\esp32\s3.h:13: warning: "LED_BUILTIN" redefined
 #define LED_BUILTIN       2

In file included from C:\Users\_USER_\AppData\Local\Arduino15\packages\esp32\hardware\esp32\2.0.17\cores\esp32/esp32-hal-gpio.h:29,
                 from C:\Users\_USER_\AppData\Local\Arduino15\packages\esp32\hardware\esp32\2.0.17\cores\esp32/esp32-hal.h:83,
                 from C:\Users\_USER_\AppData\Local\Arduino15\packages\esp32\hardware\esp32\2.0.17\cores\esp32/Arduino.h:36,
                 from D:\_CLOUD_\arduino\AciduinoV2\AciduinoV2.ino:28:
C:\Users\_USER_\AppData\Local\Arduino15\packages\esp32\hardware\esp32\2.0.17\variants\esp32s3/pins_arduino.h:17: note: this is the location of the previous definition
 #define LED_BUILTIN LED_BUILTIN  // allow testing #ifdef LED_BUILTIN

In file included from D:\_CLOUD_\arduino\AciduinoV2\src\uCtrl\module\midi\midi.hpp:33,
                 from D:\_CLOUD_\arduino\AciduinoV2\src\uCtrl\uCtrl.h:38,
                 from D:\_CLOUD_\arduino\AciduinoV2\src\aciduino.hpp:15,
                 from D:\_CLOUD_\arduino\AciduinoV2\AciduinoV2.ino:33:
D:\_CLOUD_\arduino\AciduinoV2\src\uCtrl\module\midi\BLE-MIDI\hardware\BLEMIDI_ESP32.h: In member function 'virtual void bleMidi::MyCharacteristicCallbacks::onWrite(BLECharacteristic*)':
D:\_CLOUD_\arduino\AciduinoV2\src\uCtrl\module\midi\BLE-MIDI\hardware\BLEMIDI_ESP32.h:116:50: error: conversion from 'std::__cxx11::string' {aka 'std::__cxx11::basic_string<char>'} to non-scalar type 'String' requested
         String rxValue = characteristic->getValue();
                          ~~~~~~~~~~~~~~~~~~~~~~~~^~
In file included from D:\_CLOUD_\arduino\AciduinoV2\src\sequencer\acid_sequencer.h:36,
                 from D:\_CLOUD_\arduino\AciduinoV2\src\aciduino.hpp:20,
                 from D:\_CLOUD_\arduino\AciduinoV2\AciduinoV2.ino:33:
D:\_CLOUD_\arduino\AciduinoV2\src\sequencer\engine.h: In member function 'virtual uint16_t Engine::getTrackLength(uint8_t)':
D:\_CLOUD_\arduino\AciduinoV2\src\sequencer\engine.h:87:53: warning: no return statement in function returning non-void [-Wreturn-type]
     virtual uint16_t getTrackLength(uint8_t track) {}
                                                     ^
D:\_CLOUD_\arduino\AciduinoV2\src\sequencer\engine.h: In member function 'virtual bool Engine::stepOn(uint8_t, uint8_t)':
D:\_CLOUD_\arduino\AciduinoV2\src\sequencer\engine.h:91:55: warning: no return statement in function returning non-void [-Wreturn-type]
     virtual bool stepOn(uint8_t track, uint8_t step) {}
                                                       ^
D:\_CLOUD_\arduino\AciduinoV2\src\sequencer\engine.h: In member function 'virtual uint8_t Engine::getStepData(uint8_t, uint8_t)':
D:\_CLOUD_\arduino\AciduinoV2\src\sequencer\engine.h:95:63: warning: no return statement in function returning non-void [-Wreturn-type]
     virtual uint8_t getStepData(uint8_t track, uint8_t step) {}
                                                               ^
D:\_CLOUD_\arduino\AciduinoV2\src\sequencer\engine.h: In member function 'virtual uint8_t Engine::getCurrentStep(uint8_t)':
D:\_CLOUD_\arduino\AciduinoV2\src\sequencer\engine.h:97:52: warning: no return statement in function returning non-void [-Wreturn-type]
     virtual uint8_t getCurrentStep(uint8_t track) {}
                                                    ^
D:\_CLOUD_\arduino\AciduinoV2\src\sequencer\engine.h: In member function 'virtual uint8_t Engine::getTrackVoice(uint8_t)':
D:\_CLOUD_\arduino\AciduinoV2\src\sequencer\engine.h:101:51: warning: no return statement in function returning non-void [-Wreturn-type]
     virtual uint8_t getTrackVoice(uint8_t track) {}
                                                   ^
D:\_CLOUD_\arduino\AciduinoV2\src\sequencer\engine.h: In member function 'virtual const char* Engine::getTrackVoiceName(uint8_t, uint8_t)':
D:\_CLOUD_\arduino\AciduinoV2\src\sequencer\engine.h:102:83: warning: no return statement in function returning non-void [-Wreturn-type]
     virtual const char * getTrackVoiceName(uint8_t track = 0, uint8_t voice = 0) {}
                                                                                   ^
In file included from D:\_CLOUD_\arduino\AciduinoV2\AciduinoV2.ino:33:
D:\_CLOUD_\arduino\AciduinoV2\src\aciduino.hpp: In member function 'uint8_t Aciduino::setSelectedTrack(uint8_t)':
D:\_CLOUD_\arduino\AciduinoV2\src\aciduino.hpp:111:88: warning: no return statement in function returning non-void [-Wreturn-type]
   uint8_t setSelectedTrack(uint8_t selected_track) { _selected_track = selected_track; };
                                                                                        ^
exit status 1
Error compiling for board ESP32S3 Dev Module.

```

copych, 2024-11-18:
oops, on this PC I have 2.0.17, I will upgrade it

copych, 2024-11-18:
here it is
https://gist.github.com/copych/b3faf977a17688130f18cb84da165bcd

Closed 2024-11-21.

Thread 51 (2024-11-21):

AciduinoBox

copych, 2024-11-21:
@midilab @rdridder
My suggestion is to make a new repository (I don't know if it can both be private and grant access for you). For the time being I have a snapshot of the minimal code to test that won't compile for some reason. With this repo we should at least reach the 'proof of concept' state, so that main questions would have answers, like "If it is compiled in the end, will it fit into the ESP32S3?" or "Are there some runtime conflicts" or "How to organize inter-module communications"...

rdridder, 2024-11-21:
@copych You can also make it a public repository, does not really matter. We can work with pull requests to submit changes.

copych, 2024-11-21:
@midilab please, advise, uCtrl/module/ contains whole huge libraries like U8g2 and SdFat. What is the reason for you to keep all these files? Are they modified versions or are you afraid that the newer versions would lack some of deprecated functions?

midilab, 2024-11-21:
> @midilab please, advise, uCtrl/module/ contains whole huge libraries like U8g2 and SdFat. What is the reason for you to keep all these files? Are they modified versions or are you afraid that the newer versions would lack some of deprecated functions?

To keep maintenance simple and development less prone to errors with different versions.

> @copych You can also make it a public repository, does not really matter. We can work with pull requests to submit changes.

My idea was to start a new branch here, by looking at the acidbox source code the easiest way to integrate it, is inside aciduino project, on src/ directory.

So the code inside src/ will be a submodule pointing to original acidbox repository. Just as uClock and uCtrl...

@copych you told me about a version where you use only 1 core to run all acidbox rigth? we probrably need it to run with aciduino smoothly.

After we have this 1 core version in hands, asap, i can try to glue everything to compile and commit it to the new branch so we can start work on it.

copych, 2024-11-22:
Here's the version where I tried to integrate projects. https://github.com/copych/AciduinoBox/blob/main/AciduinoBox/
 ATTENTION! /src/ isn't full! I started uploading, but then saw how many files it has, so it's better to link them.
Anyway, @midilab  feel free to do whatever you think is right.

midilab, 2024-12-12:
Closing due to Inactivity....

Closed 2024-12-12.

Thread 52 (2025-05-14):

code not compiling for esp32 devkit v1

riyant56, 2025-05-14:
I am a beginner please help me through this problem

Im leaving this  error message from arduino ide here

 Arduino: 1.8.19 (Windows Store 1.8.57.0) (Windows 10), Board: "DOIT ESP32 DEVKIT V1, 80MHz, 921600, None, Disabled"

C:\Users\riyan\Downloads\v2\AciduinoV2\0_hardware_setup.ino:75: warning: "LED_BUILTIN" redefined

   75 |     #define LED_BUILTIN               2

      |

In file included from C:\Users\riyan\OneDrive\Documents\ArduinoData\packages\esp32\hardware\esp32\3.1.1\cores\esp32/esp32-hal-gpio.h:29,

                 from C:\Users\riyan\OneDrive\Documents\ArduinoData\packages\esp32\hardware\esp32\3.1.1\cores\esp32/esp32-hal.h:88,

                 from C:\Users\riyan\OneDrive\Documents\ArduinoData\packages\esp32\hardware\esp32\3.1.1\cores\esp32/Arduino.h:36,

                 from sketch\AciduinoV2.ino.cpp:1:

C:\Users\riyan\OneDrive\Documents\ArduinoData\packages\esp32\hardware\esp32\3.1.1\variants\doitESP32devkitV1/pins_arduino.h:8: note: this is the location of the previous definition

    8 | #define LED_BUILTIN LED_BUILTIN  // allow testing #ifdef LED_BUILTIN

      |

In file included from C:\Users\riyan\Downloads\v2\AciduinoV2\src\sequencer\engine_303.h:33,

                 from C:\Users\riyan\Downloads\v2\AciduinoV2\src\sequencer\acid_sequencer.h:36,

                 from C:\Users\riyan\Downloads\v2\AciduinoV2\AciduinoV2.ino:71:

C:\Users\riyan\Downloads\v2\AciduinoV2\src\sequencer\engine.h: In member function 'virtual uint16_t Engine::getTrackLength(uint8_t)':

C:\Users\riyan\Downloads\v2\AciduinoV2\src\sequencer\engine.h:62:53: error: no return statement in function returning non-void [-Werror=return-type]

   62 |     virtual uint16_t getTrackLength(uint8_t track) {}

      |                                                     ^

C:\Users\riyan\Downloads\v2\AciduinoV2\src\sequencer\engine.h: In member function 'virtual bool Engine::stepOn(uint8_t, uint8_t)':

C:\Users\riyan\Downloads\v2\AciduinoV2\src\sequencer\engine.h:66:55: error: no return statement in function returning non-void [-Werror=return-type]

   66 |     virtual bool stepOn(uint8_t track, uint8_t step) {}

      |                                                       ^

C:\Users\riyan\Downloads\v2\AciduinoV2\src\sequencer\engine.h: In member function 'virtual uint8_t Engine::getStepData(uint8_t, uint8_t)':

C:\Users\riyan\Downloads\v2\AciduinoV2\src\sequencer\engine.h:70:63: error: no return statement in function returning non-void [-Werror=return-type]

   70 |     virtual uint8_t getStepData(uint8_t track, uint8_t step) {}

      |                                                               ^

C:\Users\riyan\Downloads\v2\AciduinoV2\src\sequencer\engine.h: In member function 'virtual uint8_t Engine::getCurrentStep(uint8_t)':

C:\Users\riyan\Downloads\v2\AciduinoV2\src\sequencer\engine.h:72:52: error: no return statement in function returning non-void [-Werror=return-type]

   72 |     virtual uint8_t getCurrentStep(uint8_t track) {}

      |                                                    ^

C:\Users\riyan\Downloads\v2\AciduinoV2\src\sequencer\engine.h: In member function 'virtual uint8_t Engine::getTrackVoice(uint8_t)':

C:\Users\riyan\Downloads\v2\AciduinoV2\src\sequencer\engine.h:76:51: error: no return statement in function returning non-void [-Werror=return-type]

   76 |     virtual uint8_t getTrackVoice(uint8_t track) {}

      |                                                   ^

C:\Users\riyan\Downloads\v2\AciduinoV2\src\sequencer\engine.h: In member function 'virtual const char* Engine::getTrackVoiceName(uint8_t, uint8_t)':

C:\Users\riyan\Downloads\v2\AciduinoV2\src\sequencer\engine.h:77:83: error: no return statement in function returning non-void [-Werror=return-type]

   77 |     virtual const char * getTrackVoiceName(uint8_t track = 0, uint8_t voice = 0) {}

      |                                                                                   ^

In file included from C:\Users\riyan\Downloads\v2\AciduinoV2\src\sequencer\engine_303.h:34:

C:\Users\riyan\Downloads\v2\AciduinoV2\src\sequencer\harmonizer.h: In constructor 'HarmonizerClass::HarmonizerClass()':

C:\Users\riyan\Downloads\v2\AciduinoV2\src\sequencer\harmonizer.h:40:21: warning: 'B11011100' is deprecated: use 0b11011100 instead [-Wdeprecated-declarations]

   40 | #define IONIAN      B11011100

      |                     ^~~~~~~~~

C:\Users\riyan\Downloads\v2\AciduinoV2\src\sequencer\harmonizer.h:77:22: note: in expansion of macro 'IONIAN'

   77 |                     {IONIAN, "ionian"},

      |                      ^~~~~~

In file included from C:\Users\riyan\OneDrive\Documents\ArduinoData\packages\esp32\hardware\esp32\3.1.1\cores\esp32/Arduino.h:41:

C:\Users\riyan\OneDrive\Documents\ArduinoData\packages\esp32\hardware\esp32\3.1.1\cores\esp32/binary.h:512:3: note: declared here

  512 |   B11011100 DEPRECATED(0b11011100) = 220,

      |   ^~~~~~~~~

C:\Users\riyan\Downloads\v2\AciduinoV2\src\sequencer\harmonizer.h:41:21: warning: 'B10111010' is deprecated: use 0b10111010 instead [-Wdeprecated-declarations]

   41 | #define DORIAN      B10111010

      |                     ^~~~~~~~~

C:\Users\riyan\Downloads\v2\AciduinoV2\src\sequencer\harmonizer.h:78:22: note: in expansion of macro 'DORIAN'

   78 |                     {DORIAN, "dorian"},

      |                      ^~~~~~

C:\Users\riyan\OneDrive\Documents\ArduinoData\packages\esp32\hardware\esp32\3.1.1\cores\esp32/binary.h:478:3: note: declared here

  478 |   B10111010 DEPRECATED(0b10111010) = 186,

      |   ^~~~~~~~~

C:\Users\riyan\Downloads\v2\AciduinoV2\src\sequencer\harmonizer.h:42:21: warning: 'B01110110' is deprecated: use 0b01110110 instead [-Wdeprecated-declarations]

   42 | #define PHRYGIAN    B01110110

      |                     ^~~~~~~~~

C:\Users\riyan\Downloads\v2\AciduinoV2\src\sequencer\harmonizer.h:79:22: note: in expansion of macro 'PHRYGIAN'

   79 |                     {PHRYGIAN, "phrygian"},

      |                      ^~~~~~~~

C:\Users\riyan\OneDrive\Documents\ArduinoData\packages\esp32\hardware\esp32\3.1.1\cores\esp32/binary.h:401:3: note: declared here

  401 |   B01110110 DEPRECATED(0b01110110) = 118,

      |   ^~~~~~~~~

C:\Users\riyan\Downloads\v2\AciduinoV2\src\sequencer\harmonizer.h:43:21: warning: 'B11101100' is deprecated: use 0b11101100 instead [-Wdeprecated-declarations]

   43 | #define LYDIAN      B11101100

      |                     ^~~~~~~~~

C:\Users\riyan\Downloads\v2\AciduinoV2\src\sequencer\harmonizer.h:80:22: note: in expansion of macro 'LYDIAN'

   80 |                     {LYDIAN, "lydian"},

      |                      ^~~~~~

C:\Users\riyan\OneDrive\Documents\ArduinoData\packages\esp32\hardware\esp32\3.1.1\cores\esp32/binary.h:528:3: note: declared here

  528 |   B11101100 DEPRECATED(0b11101100) = 236,

      |   ^~~~~~~~~

C:\Users\riyan\Downloads\v2\AciduinoV2\src\sequencer\harmonizer.h:44:21: warning: 'B11011010' is deprecated: use 0b11011010 instead [-Wdeprecated-declarations]

   44 | #define MIXOLYDIAN  B11011010

      |                     ^~~~~~~~~

C:\Users\riyan\Downloads\v2\AciduinoV2\src\sequencer\harmonizer.h:81:22: note: in expansion of macro 'MIXOLYDIAN'

   81 |                     {MIXOLYDIAN, "mixolydian"},

      |                      ^~~~~~~~~~

C:\Users\riyan\OneDrive\Documents\ArduinoData\packages\esp32\hardware\esp32\3.1.1\cores\esp32/binary.h:510:3: note: declared here

  510 |   B11011010 DEPRECATED(0b11011010) = 218,

      |   ^~~~~~~~~

C:\Users\riyan\Downloads\v2\AciduinoV2\src\sequencer\harmonizer.h:45:21: warning: 'B10110110' is deprecated: use 0b10110110 instead [-Wdeprecated-declarations]

   45 | #define AEOLIAN     B10110110

      |                     ^~~~~~~~~

C:\Users\riyan\Downloads\v2\AciduinoV2\src\sequencer\harmonizer.h:82:22: note: in expansion of macro 'AEOLIAN'

   82 |                     {AEOLIAN, "aeolian"},

      |                      ^~~~~~~

C:\Users\riyan\OneDrive\Documents\ArduinoData\packages\esp32\hardware\esp32\3.1.1\cores\esp32/binary.h:474:3: note: declared here

  474 |   B10110110 DEPRECATED(0b10110110) = 182,

      |   ^~~~~~~~~

C:\Users\riyan\Downloads\v2\AciduinoV2\src\sequencer\harmonizer.h:46:21: warning: 'B01101110' is deprecated: use 0b01101110 instead [-Wdeprecated-declarations]

   46 | #define LOCRIAN     B01101110

      |                     ^~~~~~~~~

C:\Users\riyan\Downloads\v2\AciduinoV2\src\sequencer\harmonizer.h:83:22: note: in expansion of macro 'LOCRIAN'

   83 |                     {LOCRIAN, "locrian"},

      |                      ^~~~~~~

C:\Users\riyan\OneDrive\Documents\ArduinoData\packages\esp32\hardware\esp32\3.1.1\cores\esp32/binary.h:385:3: note: declared here

  385 |   B01101110 DEPRECATED(0b01101110) = 110,

      |   ^~~~~~~~~

C:\Users\riyan\Downloads\v2\AciduinoV2\src\sequencer\harmonizer.h:50:25: warning: 'B10111100' is deprecated: use 0b10111100 instead [-Wdeprecated-declarations]

   50 | #define MELODIC_MINOR   B10111100

      |                         ^~~~~~~~~

C:\Users\riyan\Downloads\v2\AciduinoV2\src\sequencer\harmonizer.h:85:22: note: in expansion of macro 'MELODIC_MINOR'

   85 |                     {MELODIC_MINOR, "melodic minor"},

      |                      ^~~~~~~~~~~~~

C:\Users\riyan\OneDrive\Documents\ArduinoData\packages\esp32\hardware\esp32\3.1.1\cores\esp32/binary.h:480:3: note: declared here

  480 |   B10111100 DEPRECATED(0b10111100) = 188,

      |   ^~~~~~~~~

C:\Users\riyan\Downloads\v2\AciduinoV2\src\sequencer\harmonizer.h:52:25: warning: 'B01111010' is deprecated: use 0b01111010 instead [-Wdeprecated-declarations]

   52 | #define PHRYGIAN6       B01111010

      |                         ^~~~~~~~~

C:\Users\riyan\Downloads\v2\AciduinoV2\src\sequencer\harmonizer.h:86:22: note: in expansion of macro 'PHRYGIAN6'

   86 |                     {PHRYGIAN6, "phrygian 6"},

      |                      ^~~~~~~~~

C:\Users\riyan\OneDrive\Documents\ArduinoData\packages\esp32\hardware\esp32\3.1.1\cores\esp32/binary.h:409:3: note: declared here

  409 |   B01111010 DEPRECATED(0b01111010) = 122,

      |   ^~~~~~~~~

C:\Users\riyan\Downloads\v2\AciduinoV2\src\sequencer\harmonizer.h:54:33: warning: 'B11110100' is deprecated: use 0b11110100 instead [-Wdeprecated-declarations]

   54 | #define LYDIAN5                 B11110100

      |                                 ^~~~~~~~~

C:\Users\riyan\Downloads\v2\AciduinoV2\src\sequencer\harmonizer.h:87:22: note: in expansion of macro 'LYDIAN5'

   87 |                     {LYDIAN5, "lydian 5"},

      |                      ^~~~~~~

C:\Users\riyan\OneDrive\Documents\ArduinoData\packages\esp32\hardware\esp32\3.1.1\cores\esp32/binary.h:536:3: note: declared here

  536 |   B11110100 DEPRECATED(0b11110100) = 244,

      |   ^~~~~~~~~

C:\Users\riyan\Downloads\v2\AciduinoV2\src\sequencer\harmonizer.h:56:25: warning: 'B11101010' is deprecated: use 0b11101010 instead [-Wdeprecated-declarations]

   56 | #define LYDIAN7         B11101010

      |                         ^~~~~~~~~

C:\Users\riyan\Downloads\v2\AciduinoV2\src\sequencer\harmonizer.h:88:22: note: in expansion of macro 'LYDIAN7'

   88 |                     {LYDIAN7, "lydian 7"},

      |                      ^~~~~~~
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
midilab, 2025-05-15:
Hi @riyant56 ,

Thanks for reporting this! Unfortunately, not all ESP32 boards are supported at the moment—there are many different variants, each with its own unique characteristics, which often require a specific port to be made.

Currently, the only officially supported boards are the ESP32-WROOM and the ESP32-S3 (the latter in experimental mode). It's possible that other boards may compile successfully, but we can't guarantee compatibility since they haven’t been tested.

Did you use a release version or did you clone the repository directly?

Closed 2025-08-17.

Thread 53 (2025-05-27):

System freezes when using external MIDI clock on ESP32

YggdrasilUrthr, 2025-05-27:
After changing the system clock to either midi1 or midi2 (implemented via a suitable midi I/O circuit) the system becomes unresponsive. The selected option keeps blinking but I cannot use any button. I had the same issue with both the latest release version and the one cloned from the repository. I also tried the develop branch but I was unable to compile the code using Arduino IDE 2.3.3 (also tested 2.3.6) and any ESP32 core from version 2.0.17 up to the latest one.
The only changes I made to the ports file have been assigning a pin to the transport button, reversing the pot direction and switching the hw midi port from Serial2 to Serial1.

Am I doing something wrong?

midilab, 2025-05-27:
Hi @YggdrasilUrthr ,

Thanks for the report,

Can you please try with no changes on ports file and report it back? keep the original one for this first test.

YggdrasilUrthr, 2025-05-27:
Hi, thanks for your quick answer.
I uploaded the code using the default wroom.h file included in the release version, but the issue is still there. Specifically, I can select freely midi1 and use the all the navigation button correctly but, as soon as I press play in my DAW, the system freezes as before. On the other hand, if I select midi2 as clock source the system immediatley crashes (but I think this is due to the now miswired hardware MIDI port, which is still attached to the Serial1 pins leaving the Serial2 pins unconnected).

Since it may be relevant, I am using a NodeMCU ESP32-S2 (which mounts the supported wroom 32 chip). I originally redefined the pins in the ports file since the default hw MIDI port (Serial2) is located on the same pin as the shift button (pin 17, as defined in the repo). I can also safely rule out any fault in the external MIDI circuit since MIDI out correctly works and I also implemented a MIDI through connection which correctly loops back any MIDI message sent from the DAW.

midilab, 2025-05-27:
I'm aware that ESP32s have some issues with specific pins. Depending on the model, a pinout that works on one ESP32 can cause another to freeze — usually because some pins are used for internal functions.

Unfortunately, the USB connector on my ESP32 is broken, so I can't verify this directly. But we can try to debug it using your board. It might take a bit of time, as I'll need to analyze things on my end and then have you test the changes.

Could you please share your modified wroom.h via a Gist?

Also, here are some notes on which pins to avoid, as they can lead to unpredictable behavior:
🔗 https://randomnerdtutorials.com/esp32-pinout-reference-gpios/

midilab, 2025-05-31:
Great, that works!

The changes are already in the develop branch and are pending merge along with a few other upcoming features.

Thanks again for your help with testing, debugging, and providing the fix.

Could you please share the exact model of your ESP32? MIDI ports used and pinout? the idea is to add as many ports to extend compatibility of different ESP32 models. We'd like to list it as a known supported device in the documentation.

YggdrasilUrthr, 2025-05-31:
Great!!

I am using a NodeMCU ESP32-S v1.1 (https://www.espboards.dev/esp32/nodemcu-32s/). On the hardware side I used the same pins defined in wroom.h, keeping in my mind that in my board they are located slightly differently (pinout in last link). I then added a transport button wired to pin 13 and reversed the pot direction (I accidentally soldered it upside down, oops). I kept the hardware midi port on Serial2 (pins 16 and 17 on my board) as in the original file. I uploaded the final port configuration here: https://gist.github.com/YggdrasilUrthr/3ff72e113739ec97654d7f4f59dfdf8d

Finally, I used this circuit https://diyelectromusic.com/2023/12/12/raspberry-pi-zero-midi-pcb/ for the midi hw interface (I just copied the circuit on breadboard without a dedicated PCB), connected to pin 16 and 17 (Serial2). I only swapped the 74HCT14 with a SN74HC14N (which according to the guide should not work, but I effectively used it without any problem on three different 3.3 devices).

That should be everything! Let me know if you need any additional detail.

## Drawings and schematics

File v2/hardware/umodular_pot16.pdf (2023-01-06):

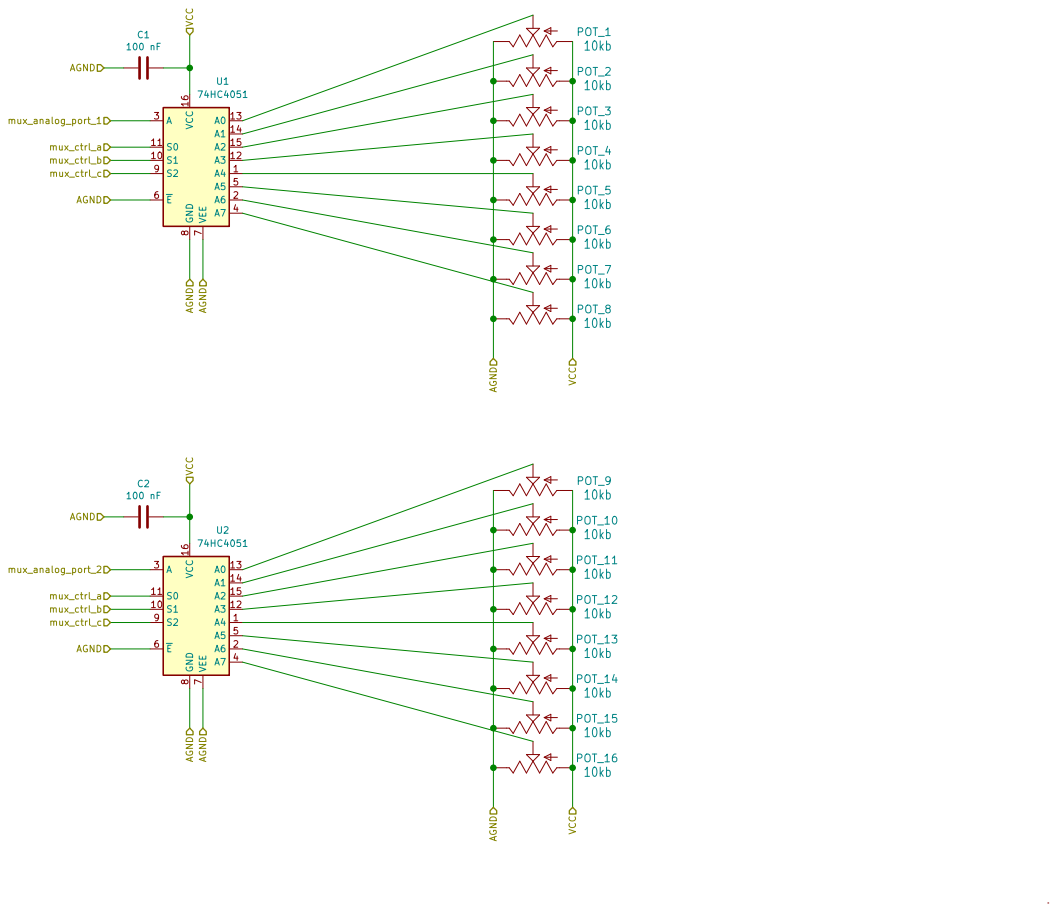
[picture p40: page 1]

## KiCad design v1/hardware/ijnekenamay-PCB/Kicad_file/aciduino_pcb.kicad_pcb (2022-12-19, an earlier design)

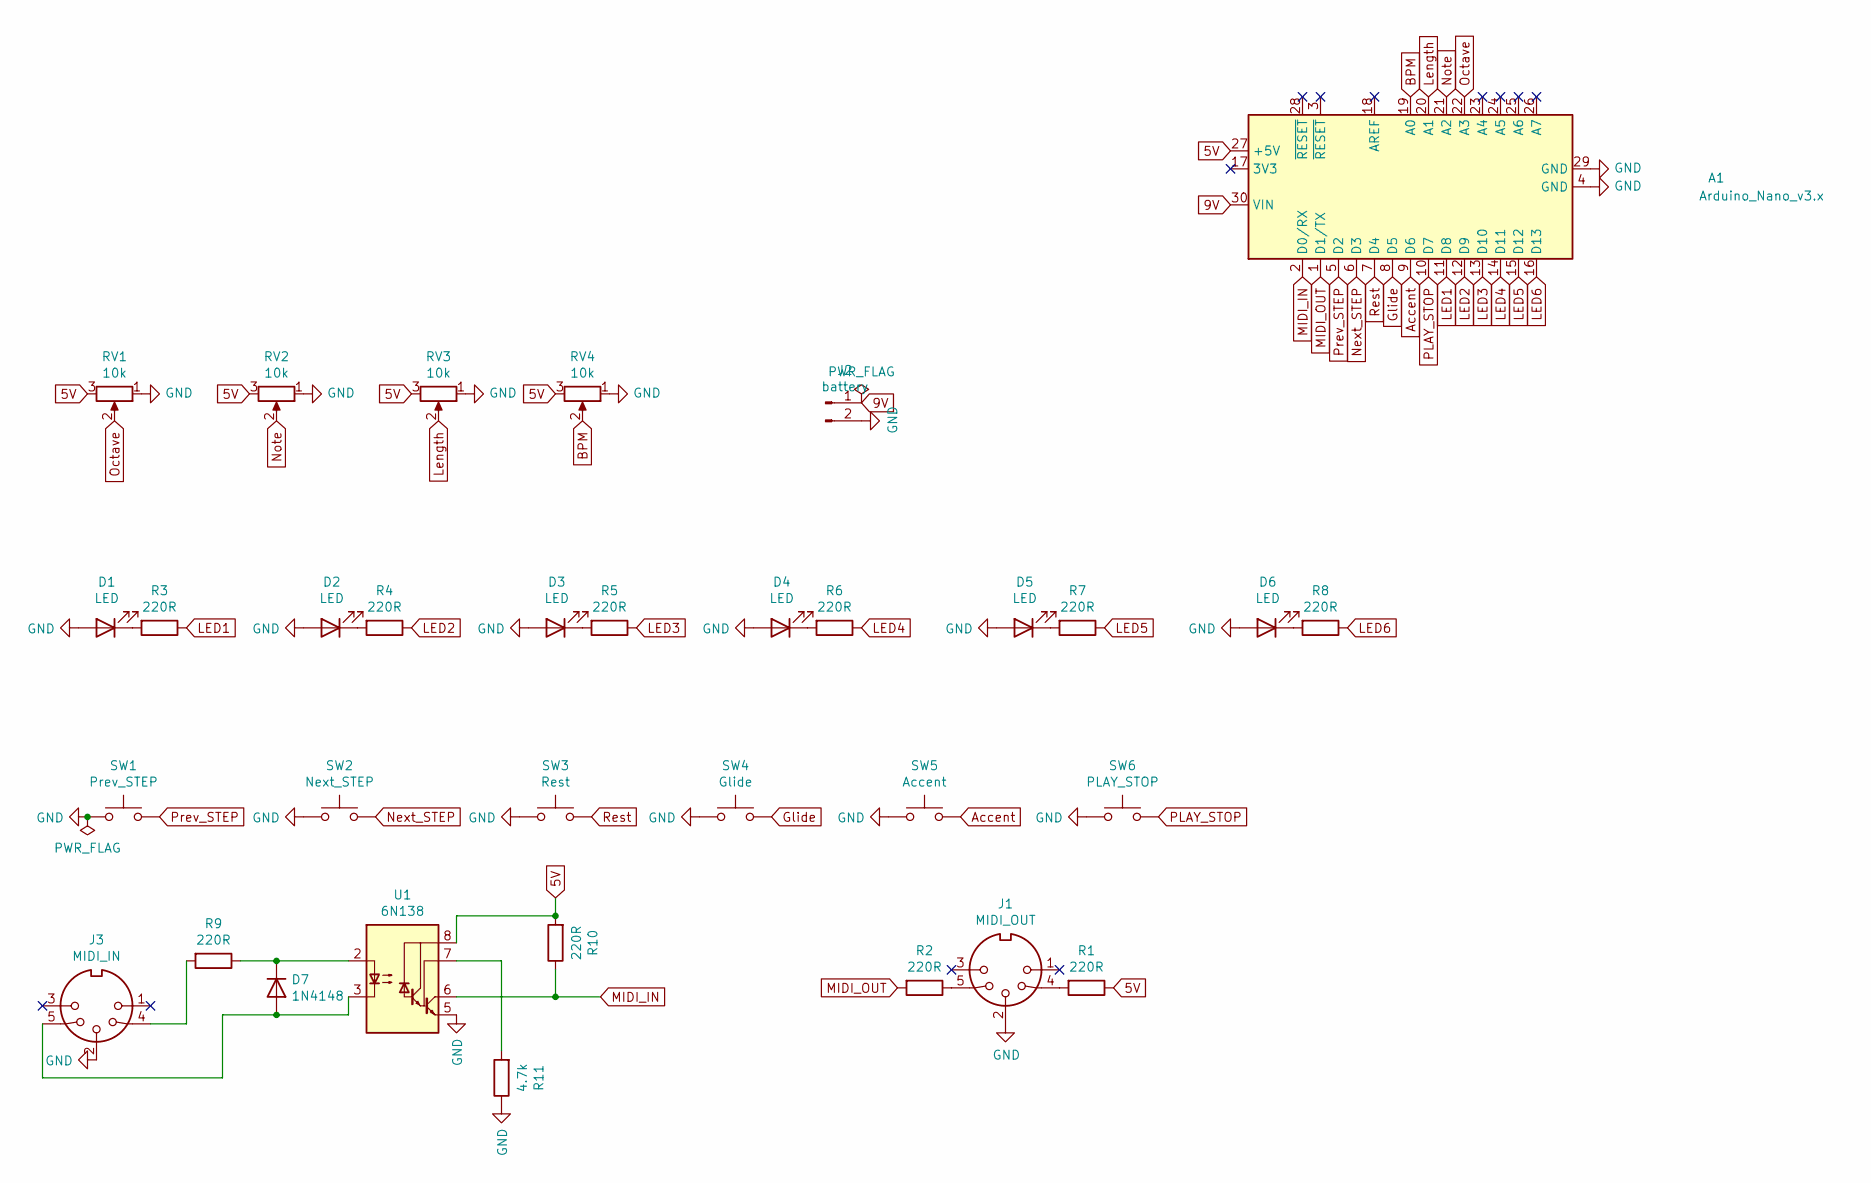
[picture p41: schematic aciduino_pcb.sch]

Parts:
A1: Arduino_Nano_v3.x; Arduino_Nano
D1, D2, D3, D4, D5, D6: LED; LED_D3.0mm
D7: 1N4148; D_DO-35_SOD27_P7.62mm_Horizontal
J1: MIDI_OUT; SDS-50J
J2: battery; PinHeader_1x02_P2.54mm_Vertical
J3: MIDI_IN; SDS-50J
R1, R2, R3, R4, R5, R6, R7, R8, R9, R10: 220R; R_Axial_DIN0207_L6.3mm_D2.5mm_P7.62mm_Horizontal
R11: 4.7k; R_Axial_DIN0207_L6.3mm_D2.5mm_P7.62mm_Horizontal
RV1, RV2, RV3, RV4: 10k; Potentiometer_Alpha_RD901F-40-00D_Single_Vertical
SW1: Prev_STEP; SW_TH_Tactile_Omron_B3F-10xx
SW2: Next_STEP; SW_TH_Tactile_Omron_B3F-10xx
SW3: Rest; SW_TH_Tactile_Omron_B3F-10xx
SW4: Glide; SW_TH_Tactile_Omron_B3F-10xx
SW5: Accent; SW_TH_Tactile_Omron_B3F-10xx
SW6: PLAY_STOP; SW_TH_Tactile_Omron_B3F-10xx
U1: 6N138; DIP-8_W7.62mm

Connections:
5V: A1.27 (+5V), R1.1, R10.2, RV1.3, RV2.3, RV3.3, RV4.3, U1.8 (VCC)
9V: A1.30 (VIN), J2.1
Accent: A1.9 (D6), SW5.2
BPM: A1.19 (A0), RV4.2
GND: A1.4 (GND), A1.29 (GND), D1.2 (A), D2.2 (A), D3.2 (A), D4.2 (A), D5.2 (A), D6.2 (A), J1.2, J2.2, J3.2, R11.1, RV1.1, RV2.1, RV3.1, RV4.1, SW1.1, SW2.1, SW3.1, SW4.1, SW5.1, SW6.1, U1.5 (GND)
Glide: A1.8 (D5), SW4.2
LED1: A1.11 (D8), R3.1
LED2: A1.12 (D9), R4.1
LED3: A1.13 (D10), R5.1
LED4: A1.14 (D11), R6.1
LED5: A1.15 (D12), R7.1
LED6: A1.16 (D13), R8.1
Length: A1.20 (A1), RV3.2
MIDI_IN: A1.2 (D0/RX), R10.1, U1.6 (VO2)
MIDI_OUT: A1.1 (D1/TX), R2.2
unnamed: D1.1 (K), R3.2
unnamed: D2.1 (K), R4.2
unnamed: D3.1 (K), R5.2
unnamed: D4.1 (K), R6.2
unnamed: D5.1 (K), R7.2
unnamed: D6.1 (K), R8.2
unnamed: D7.1 (K), R9.1, U1.2 (C1)
unnamed: D7.2 (A), J3.5, U1.3 (C2)
unnamed: J1.4, R1.2
unnamed: J1.5, R2.1
unnamed: J3.4, R9.2
unnamed: R11.2, U1.7 (VO1)
Next_STEP: A1.6 (D3), SW2.2
Note: A1.21 (A2), RV2.2
Octave: A1.22 (A3), RV1.2
PLAY_STOP: A1.10 (D7), SW6.2
Prev_STEP: A1.5 (D2), SW1.2
Rest: A1.7 (D4), SW3.2

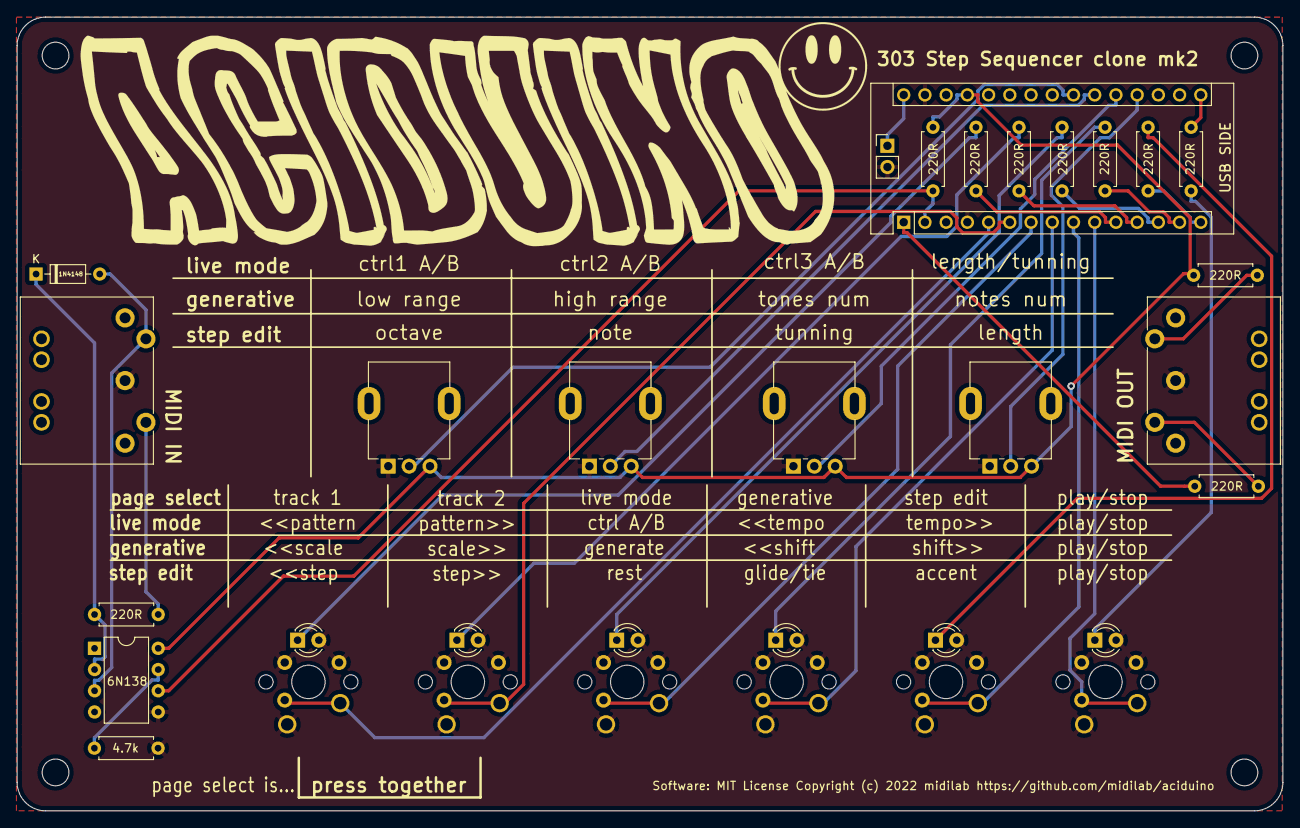
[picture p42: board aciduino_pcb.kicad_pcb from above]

Board: 2 copper layers, 151.5 x 95.0 mm, 37 parts (0 on the bottom side), 33 nets.

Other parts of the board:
mount1, mount2, mount3, mount4: Hole_2.2mm; MountingHole_2.2mm_M2_Pad

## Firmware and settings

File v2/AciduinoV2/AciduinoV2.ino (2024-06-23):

/*!
 *  @file       AciduinoV2.ino
 *  Project     Aciduino V2
 *  @brief      Roland 303 and 808 step sequencer clone
 *  @version    2.2.0
 *  @author     Romulo Silva
 *  @date       11/01/22
 *  @license    MIT - (c) 2022 - Romulo Silva - contact@midilab.co
 *
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
 * THE SOFTWARE IS PROVIDED "AS IS", WITHOUT WARRANTY OF ANY KIND, EXPRESS
 * OR IMPLIED, INCLUDING BUT NOT LIMITED TO THE WARRANTIES OF MERCHANTABILITY,
 * FITNESS FOR A PARTICULAR PURPOSE AND NONINFRINGEMENT. IN NO EVENT SHALL THE
 * AUTHORS OR COPYRIGHT HOLDERS BE LIABLE FOR ANY CLAIM, DAMAGES OR OTHER
 * LIABILITY, WHETHER IN AN ACTION OF CONTRACT, TORT OR OTHERWISE, ARISING
 * FROM, OUT OF OR IN CONNECTION WITH THE SOFTWARE OR THE USE OR OTHER
 * DEALINGS IN THE SOFTWARE. 
 */
#include <Arduino.h>

//
// Aciduino
//
#include "src/aciduino.hpp"

//
// Select your platform port
//
#include "src/ports/esp32/wroom.h"
//#include "src/ports/avr/mega.h"
//#include "src/ports/teensy/protoboard.h"
//#include "src/ports/esp32/wroom-ext1.h"
//#include "src/ports/teensy/uone.h"
//#include "src/ports/avr/midilab_mega.h"
//#include "src/ports/avr/afourtrackmind_mega.h"

void setup() {
  // inits all hardware setup for the selected port
  initPort();
}

void loop() {
  aciduino.run();
}

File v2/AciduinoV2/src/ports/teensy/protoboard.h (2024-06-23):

#include "../../uCtrl/uCtrl.h"

#include "../../aciduino.hpp"

// teensy 3.2+ on protoboard

//============================================
// Aciduino Features Setup
//============================================

// make use of bpm led?
// change for another pin if use any spi module
#define USE_BPM_LED       LED_BUILTIN
// main navigation
#define USE_CHANGER_POT
//#define USE_CHANGER_ENCODER
#define USE_TRANSPORT_BUTTON

//#define USE_POT_MICRO

#define FLIP_DISPLAY
#define INVERT_POT_READ

#define USE_MIDI1
#define USE_MIDI2

// for protoboard hacks
#define USE_TEENSY_PROTOBOARD_HACKS

// wich modules you need acidman?
// PUSH and LED modules require booth PUSH_SPI and LED_SPI to point into some spi device
//#define USE_PUSH_8      // uses 165 shiftregister (buttons)
//#define USE_PUSH_24     // uses 3x 165 shiftregister
//#define USE_PUSH_32     // uses 4x 165 shiftregister
//#define USE_LED_8       // uses 595 shiftregister
//#define USE_LED_24      // uses 3x 595 shiftregister
//#define USE_POT_8       // uses 4051 multiplexer
//#define USE_POT_16      // uses 2x 4051 multiplexer
//#define USE_TOUCH_32    // uses 2x 4067 multiplexer


//============================================
// PINOUT Setup
//============================================

// going to use changer encoder?
//#define NAV_ENCODER_DEC_PIN       24
//#define NAV_ENCODER_INC_PIN       25

#define NAV_SHIFT_PIN             4

#define NAV_FUNCTION1_PIN         6
#define NAV_FUNCTION2_PIN         7
#define NAV_GENERAL1_PIN          3
#define NAV_GENERAL2_PIN          5
#define NAV_RIGHT_PIN             15
#define NAV_UP_PIN                14
#define NAV_DOWN_PIN              9
#define NAV_LEFT_PIN              16

#define TRANSPORT_BUTTON_1_PIN    10

// going to use changer pot?
#define CHANGER_POT_PIN           A9

// you need USE_POT_MICRO to enable those pins
//#define POT_MICRO_1_PIN   ??
//#define POT_MICRO_2_PIN   ??
//#define POT_MICRO_3_PIN   ??
//#define POT_MICRO_4_PIN   ??
// + 4 pots extensions
//#define POT_MICRO_5_PIN   ??
//#define POT_MICRO_6_PIN   ??
//#define POT_MICRO_7_PIN   ??
//#define POT_MICRO_8_PIN   ??

//============================================
// Managed Devices Setup
//============================================

// Display device
//U8G2_SSD1306_128X64_NONAME_F_HW_I2C u8g2(U8G2_R0, U8X8_PIN_NONE);
U8G2_SH1106_128X64_NONAME_F_HW_I2C u8g2(U8G2_R0, U8X8_PIN_NONE);

// Midi device
// initing midi devices
#define MIDI1         usbMIDI
MIDI_CREATE_INSTANCE(HardwareSerial, Serial1, MIDI2);

// SPI devices
//#define PUSH_SPI          SPI
//#define LED_SPI           SPI

// the main interface choice
#include "../../interface/midilab/main.h"

void initPort() {
  //
  // OLED setup
  //
  uCtrl.initOled(&u8g2);
#if defined(FLIP_DISPLAY)
  uCtrl.oled->flipDisplay(1);
#endif

  //
  // Storage setup
  //
  uCtrl.initStorage();
  //uCtrl.initStorage(&STORAGE_SPI, 7);

  //
  // DIN Module
  //
#if defined(USE_PUSH_8) || defined(USE_PUSH_24) || defined(USE_PUSH_32)
  // going with shiftregister and SPI?
  uCtrl.initDin(&PUSH_SPI, PUSH_LATCH_PIN);
#else
  uCtrl.initDin();
#endif

#if defined(USE_CHANGER_ENCODER)
  // dec
  uCtrl.din->plug(NAV_ENCODER_DEC_PIN);
  // inc
  uCtrl.din->plug(NAV_ENCODER_INC_PIN);
#endif

  // shift button
  uCtrl.din->plug(NAV_SHIFT_PIN);

  // the default aciduino schema implements all the
  // basic navigation for full usage without any CI
  // only the usage of 32 buttons will disables
  // the direct microcontroler port connect to main interface
#if !defined(USE_PUSH_32) && !defined(USE_TOUCH_32)
  // follow the register order of BUTTONS_INTERFACE_CONTROLS enum
  // page button 1
  uCtrl.din->plug(NAV_FUNCTION1_PIN);
  // page button 2
  uCtrl.din->plug(NAV_FUNCTION2_PIN);
  // decrementer button
  uCtrl.din->plug(NAV_GENERAL1_PIN);
  // incrementer button
  uCtrl.din->plug(NAV_GENERAL2_PIN);
  // next
  uCtrl.din->plug(NAV_RIGHT_PIN);
  // up
  uCtrl.din->plug(NAV_UP_PIN);
  // down
  uCtrl.din->plug(NAV_DOWN_PIN);
  // previous
  uCtrl.din->plug(NAV_LEFT_PIN);
#if defined(USE_TRANSPORT_BUTTON)
  // transport
  uCtrl.din->plug(TRANSPORT_BUTTON_1_PIN);
#endif

#endif

// any shiftregister to plug?
#if defined(USE_PUSH_8)
  uCtrl.din->plugSR(1);
#elif defined(USE_PUSH_24)
  uCtrl.din->plugSR(3);
#elif defined(USE_PUSH_32)
  uCtrl.din->plugSR(4);
#endif

#if defined(USE_CHANGER_ENCODER)
  // encoders setup
  // in pair order always! and pairs starting with odd ids
  uCtrl.din->encoder(ENCODER_DEC, ENCODER_INC);
#endif
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

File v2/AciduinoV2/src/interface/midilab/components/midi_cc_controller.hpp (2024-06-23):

// generic controler for 303 and 808 devices
typedef struct
{
    const char * control_name;
    uint8_t control_cc = 0;
    uint8_t control_data[TRACK_NUMBER_303];
    int8_t pot_map[TRACK_NUMBER_303] = {-1};
} MIDI_CTRL_DATA_303;

typedef struct
{
    const char * control_name;
    uint8_t control_cc = 0;
    uint8_t control_data[TRACK_NUMBER_808];
    int8_t pot_map[TRACK_NUMBER_808] = {-1};
} MIDI_CTRL_DATA_808;

struct MidiCCControl : PageComponent {

    uint8_t selected_map = 0;
    uint8_t ctrl_selected = 0;

    uint8_t last_selected_track = 0;

#if defined(LEARN_ENABLED)
    const bool learn_enabled = true; 
#else
    const bool learn_enabled = false; 
#endif
    bool learn = false;

    // layout:
    // max 16 controls per track
    // (4 x 2) x 2
    // f1 = A (select A map)
    // f2 = B (select B map)
    // shift changes f1 and f2 to clear  |  learn/POTID
    MIDI_CTRL_DATA_303 control_map_303[16];
    uint8_t ctrl_size_303 = 0;

    MIDI_CTRL_DATA_808 control_map_808[16];
    uint8_t ctrl_size_808 = 0;
    
    MidiCCControl()
    {
      // we want this component to be 4 lines max and 2 grids navigable object
      line_size = 4;
      grid_size = 2;
      // enable more complex nav by updating selector pointer of page component
      update_selector_view = true;
      // initing pot_map for learn refrence
      for (uint8_t i=0; i < 16; i++) {
        for (uint8_t j=0; j < TRACK_NUMBER_303; j++) {
          control_map_303[i].pot_map[j] = -1;
        }
        for (uint8_t j=0; j < TRACK_NUMBER_808; j++) {
          control_map_808[i].pot_map[j] = -1;
        }
      }
    }

    void view() {
      uint8_t data_idx = aciduino.seq.is303(aciduino.getSelectedTrack()) ? aciduino.getSelectedTrack() : aciduino.getSelectedTrack() - TRACK_NUMBER_303;
      uint8_t ctrl_map_init = selected_map == 0 ? 0 : 8;
      uint8_t ctrl_counter = 0;
      ctrl_selected = selected_line-1 + (selected_grid == 2 ? 4 : 0);
      ctrl_selected += selected_map > 0 ? 8 : 0;
      last_selected_track = aciduino.getSelectedTrack();

      // print controls
      for (uint8_t i=ctrl_map_init; i < ctrl_map_init+8; i++) {
        // process 303 controlelrs?
        if (aciduino.seq.is303(aciduino.getSelectedTrack())) {
          if (i >= ctrl_size_303) {
            // breaks with no selected element? fix it!
            if (ctrl_selected >= ctrl_size_303) {
              selected_grid = floor((selected_map > 0 ? ctrl_size_303-1-8 : ctrl_size_303-1)/4)+1;
              selected_line = ((selected_map > 0 ? ctrl_size_303-1-8 : ctrl_size_303-1)%4)+1;
            }
            break;
          }
          genericOptionView(control_map_303[i].control_name, String(control_map_303[i].control_data[data_idx]), line+(i%4), ctrl_counter >= 4 ? 14 : 1, i==ctrl_selected);
        // process 808 controlelrs?
        } else {
          if (i >= ctrl_size_808) {
            // breaks with no selected element? fix it!
            if (ctrl_selected >= ctrl_size_808) {
              selected_grid = floor((selected_map > 0 ? ctrl_size_808-1-8 : ctrl_size_808-1)/4)+1;
              selected_line = ((selected_map > 0 ? ctrl_size_808-1-8 : ctrl_size_808-1)%4)+1;
            }
            break;
          }
          genericOptionView(control_map_808[i].control_name, String(control_map_808[i].control_data[data_idx]), line+(i%4), ctrl_counter >= 4 ? 14 : 1, i==ctrl_selected);
        }
        ++ctrl_counter;
      }

      // shift only if learn enabled
      if ((uCtrl.page->isShiftPressed() || learn == true) && learn_enabled == true) {
        updateControlMap();
        int8_t pot_map = aciduino.seq.is303(aciduino.getSelectedTrack()) ? control_map_303[ctrl_selected].pot_map[data_idx] : control_map_808[ctrl_selected].pot_map[data_idx];
        if (pot_map == -1) {
          setF2("learn", learn == true ? true : false);
        } else {
          // clear pot_map
          //setF1(String(String("clear") + String(pot_map)).c_str());
          setF2("clear");
        }
        if (learn == true) {
          setF1("cancel");
        } else {
          setF1("");
        }
      // no shift 
      } else {
        setF1("A", selected_map == 0 ? true : false);
        setF2("B", selected_map == 1 ? true : false);
      }
    }

    void change(int16_t data) {
      sendCCData(data, ctrl_selected, aciduino.getSelectedTrack());
    }
    
    void function1() {
      // shift 
      if ((uCtrl.page->isShiftPressed() || learn == true) && learn_enabled == true) {
        // cancel learn
        learn = false;
      } else {
        selected_map = 0;
      }
    }

    void function2() {
      // shift 
      if (uCtrl.page->isShiftPressed() && learn_enabled == true) {
        // learn!
        // lock all other pots
        // set waiting learn flag
        uint8_t data_idx = aciduino.seq.is303(aciduino.getSelectedTrack()) ? aciduino.getSelectedTrack() : aciduino.getSelectedTrack() - TRACK_NUMBER_303;
        int8_t pot_map = aciduino.seq.is303(aciduino.getSelectedTrack()) ? control_map_303[ctrl_selected].pot_map[data_idx] : control_map_808[ctrl_selected].pot_map[data_idx];
        if (pot_map == -1) {
          learn = true;
        } else {
          // clear pot_map
          clearCtrl(ctrl_selected);
        }
      } else {
        selected_map = 1;
      }
    }

    void sendCCData(int16_t data, uint8_t ctrl, uint8_t track, uint8_t interrupted = 0) {
      uint8_t data_idx = aciduino.seq.is303(track) ? track : track - TRACK_NUMBER_303;
      // process 303 controlelrs?
      if (aciduino.seq.is303(track)) {
        data = parseData(data, 0, 127, control_map_303[ctrl].control_data[data_idx]);
        control_map_303[ctrl].control_data[data_idx] = data;
        // send data
        aciduino.sendMidiCC(control_map_303[ctrl].control_cc, data, aciduino.getTrackOutputParam(TRACK_CHANNEL, track), aciduino.getTrackOutputParam(TRACK_PORT, track), interrupted);
      } else {
        data = parseData(data, 0, 127, control_map_808[ctrl].control_data[data_idx]);
        control_map_808[ctrl].control_data[data_idx] = data;
        // send data
        aciduino.sendMidiCC(control_map_808[ctrl].control_cc, data, aciduino.getTrackOutputParam(TRACK_CHANNEL, track), aciduino.getTrackOutputParam(TRACK_PORT, track), interrupted);
      }
    }

    void sendLastCCData(int16_t data) {
      sendCCData(data, ctrl_selected, last_selected_track);
    }
    
    void set303Control(const char * name, uint8_t cc, uint8_t initial_value = 0) {
      if (ctrl_size_303 >= 16)
        return;
      control_map_303[ctrl_size_303].control_name = name;
      control_map_303[ctrl_size_303].control_cc = cc;
      for (uint8_t i=0; i < TRACK_NUMBER_303; i++) {
        control_map_303[ctrl_size_303].control_data[i] = initial_value;
      }
      ++ctrl_size_303;
    }
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

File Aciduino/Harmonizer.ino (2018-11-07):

//
// MODE temperament
//
// MAJOR MODES
uint8_t _ionian[8] = { 0, 2, 4, 5, 7, 9, 11, 12 };
uint8_t _dorian[8] = { 0, 2, 3, 5, 7, 9, 10, 12 };
uint8_t _phrygian[8] = { 0, 1, 3, 5, 7, 8, 10, 12 };
uint8_t _lydian[8] = { 0, 2, 4, 6, 7, 9, 11, 12 };
uint8_t _mixolidian[8] = { 0, 2, 4, 5, 7, 9, 10, 12 };
uint8_t _aeolian[8] = { 0, 2, 3, 5, 7, 8, 10, 12 };
uint8_t _locrian[8] = { 0, 1, 3, 5, 6, 8, 10, 12 };

// MINOR MODES
// ascending melodic minor
uint8_t _melodic[8] = { 0, 2, 3, 5, 7, 9, 11, 12 };
// phrygian ♮6 (dorian ♭2)
uint8_t _phrygian6[8] = { 0, 1, 3, 5, 7, 9, 10, 12 };
// lydian augmented (lydian ♯5)
uint8_t _lydian5[8] = { 0, 2, 4, 6, 8, 9, 11, 12 };
// lydian dominant (also, "lydian ♭7", acoustic scale, or mixolydian ♯4)
uint8_t _lydian7[8] = { 0, 2, 4, 6, 7, 9, 10, 12 };
// mixolydian ♭6 (or melodic major or simply "fifth mode")
uint8_t _mixolydian6[8] = { 0, 2, 4, 5, 7, 8, 10, 12 };
// locrian ♮2 (also known as "half-diminished" scale)
uint8_t _locrian2[8] = { 0, 2, 3, 5, 6, 8, 10, 12 };
// super Locrian (also "altered dominant scale", or "altered scale")
uint8_t _super_locrian[8] = { 0, 1, 3, 4, 6, 8, 10, 12 };

uint8_t * _mode[] = {
  // MAJOR MODES
  _ionian,
  _dorian,
  _phrygian,
  _lydian,
  _mixolidian,
  _aeolian,
  _locrian,
  // MINOR MODES
  _melodic,
  _phrygian6,
  _lydian5,
  _lydian7,
  _mixolydian6,
  _locrian2,
  _super_locrian
};

#define MODES_NUMBER (sizeof(_mode) / sizeof(uint16_t)) // its array pointer we are holding here

uint8_t _selected_mode = 0;

uint8_t harmonizer(uint8_t note)
{
  uint8_t octave, interval;

  octave = floor(note/12);
  interval = floor((note%12)/1.5);
  
  return (octave*12) + _mode[_selected_mode][interval];
}

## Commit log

2018-03-14 Added Fritzing file as main hardware development platform. Directory structure to separate Software and Hardware.
    [aciduino.fzz]
2018-03-14 Better separation between hardware managment for Pots and Buttons from User Interface managment code. Make it easier to port other kinda of User Interfaces using same code base.
    [aciduino.fzz]
2018-04-12 Cosmetic changes on interface. Bring the thrid potentiometer close to first 2 other potentiometers.
    [aciduino.fzz]
2018-04-15 Hotfix: _transpose, _harmonize and _selected_mode are now acced atomiclly to avoid race conditions between main code and ISR code. Brief Manual notes added for pages.
    [Harmonizer.ino]
2018-04-16 Added project BOM List
2018-07-16 uClock library updated to newest version. It has some hotfixes related to external slave gear sync. Please check https://github.com/midilab/uClock/ for more detailed info.
2018-10-26 Hotfix: Midi controller screw clock timming while send CC data like crazy on bad breadboard with bad potentiometers, raise it and add a config option to set it on config.h
2018-11-07 pre 1.1 release. changelog: live mode page - prepared to comming save and load pattern, plus most used live commands to acidulize your self generative page - 2 new genarative parameters: number of to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
2018-11-09 Aciduino V1.2: 14 non volatile pattern memory slots for live jamming. You can now save and load your patterns.
2018-11-09 Hotfix: more stable version of holded() for button hold action
2018-11-09 visual feedback status for save and clear pattern on eeprom memory. hotfix for last pattern loaded on non existent pattern slot
2020-08-21 no need for drift setup on aciduino arduino nano.
2021-10-23 add gerber
    [aciduino_pcb.kicad_pcb]
2022-02-23 Update PCB
2022-02-24 Update gerber
2022-02-27 added slave midi sync feature and ijnekemany new mkii PCB files with midi input integrated to support the new feature! thanks ijnekemany!
    [aciduino_pcb.dsn, aciduino_pcb.kicad_pcb, aciduino_pcb.sch]
2022-02-27 added ijnekenamay's PCB reference
2022-06-15 Add Kicad file
    [aciduino_pcb.kicad_pcb, aciduino_pcb.sch]
2022-09-26 fix engine output midi data
    [AciduinoV2.ino, midi.ino, setup.h]
2022-09-27 trying to shrink code base to fit on teensy lc
2022-10-03 add fritzing initial breadboard and components
    [aciduino_v2.fzz]
2022-10-04 added schematic and protoboard view, unfinished pcb
    [aciduino_v2.fzz]
2022-10-05 added a png for schematics on breadboard. changes on UI/UX after some tests
    [aciduino_v2.fzz]
2022-10-11 added tie support for 303 and slide fix for 3030 engine
    [AciduinoV2.ino, midi.ino]
2022-10-14 added clear track, simplifier navigation, dedicated shift+page1 button for tempo setup
    [aciduino_v2.fzz]
2022-10-15 move things around for release
    [aciduino.fzz, aciduino_pcb.kicad_pcb, aciduino_pcb.sch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]
2022-10-17 added support for midi uart
2022-10-18 added aciduino breadboard schematic png for faster view
2022-10-28 added realtime record and note preview via generic button 1
2022-10-30 -reoganize repo for v1 and v2. -added uCtrl as submodule. -normalize tap function send note
    [aciduino.fzz, aciduino_lite_v2-teensy.fzz, aciduino_pcb.kicad_pcb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]
2022-10-30 added v2 lite assembly photos
2022-10-30 Revert "added v2 lite assembly photos" Photos way too large!
    This reverts commit f0e6f4ddabd4587a42cf8622a7c083973dd9fcf0.
2022-10-31 added assembly pictures and aciduino v2 pictures
2022-11-03 fix assembly exaplanation reference for pot base placement
2022-11-08 fix slide behaviour or 303 engine
    [setup.h]
2022-11-08 fix full sized step sequencer nav behaviour. added uOne support and step button/led matrix
    [AciduinoV2.ino, page_live.ino, page_sequencer.ino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]
2022-11-16 MidiCCControl goes to heap for initial setup of track size handling to avoid index crashes
    [AciduinoV2.ino]
2022-11-29 rewrite MidiCCControl component for better memory footprint. Added new midi cc for 808 and 303
2022-12-01 fix missbehaviour of update_selector on step page
    [page_live.ino]
2022-12-09 added generative per track parameters
2022-12-19 update ijnekenamay's pcb for new tie event panel title
    [aciduino_pcb.kicad_pcb]
2022-12-21 added avr mega 2560 support
    [aciduino_lite_v2-teensy.fzz, aciduino_v2-avr_mega.fzz]
2022-12-21 change non-implemented undo per clear track on generative page
2022-12-25 experimental support for esp32 wroom boards
    [aciduino_v2-esp32.fzz]
2022-12-26 non working version of esp32, still experimental, needs some review for multithread enviroment
2022-12-26 remove esp32 from now from list of supported devices
2022-12-29 experimental version of esp32
2023-01-06 added basic support for 16 pots midi controller via ain driver(using 2x 4051)
2023-01-06 add pot16 schematic for aciduino v2 16 potentiometer midi controler extension
2023-01-09 ESP32 buttons schematic fix
    [aciduino_v2-esp32.fzz]
2023-01-09 ESP32 new wiring setup
2023-01-26 add auto init epprom for non intialized or memory track layout changes
2023-01-26 add auto load session and first slot pattern from epprom at boot
2023-01-27 fix a 303 off by 1 step
    [acid_sequencer.ino, page_midi.ino, page_sequencer.ino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]
2023-01-29 fix midi cc for pot16 over 303 sequence
    [AciduinoV2.ino, acid_sequencer.ino]
2023-02-06 added dedicated transport button as an build option
    [aciduino_lite_v2-teensy.fzz, aciduino_v2-avr_mega.fzz]
2023-05-20 added pusherman link to aciduno v1 PCB order
2023-08-05 fix esp32 compilation
2023-08-30 update uCtrl version and fix new version off-by-one for buttons assignment
2023-08-31 off by 1 button assign bugfix
2023-09-05 uOne touch driver threshold setup
2023-09-05 uClock update to support esp32
2023-09-05 uCtrl update to support esp32
2023-09-05 esp32 support added with midi sync!
2023-09-12 added esp32 usb-midi native support(experimental)
2023-09-12 update uCtrl to fix esp32 native usb midi compile
2023-09-22 fix shuffle edge case for +5 ticks
2023-09-22 fix shuffle edge case for -5 ticks
2023-10-18 fix esp32 usb midi freezing
2023-10-19 update uCtrl that fixes esp32 usb midi compile
2023-12-10 fix: page memory bug
    [AciduinoV2.ino]
2023-12-10 fix: page memory initialize before start operation
    [AciduinoV2.ino]
2023-12-13 feature: add support for hibrid setup for pot changer and encoder changer
2023-12-18 wip: new esp32 extension module
    [aciduino_v2-esp32-30pins.fzz, aciduino_v2-esp32-wroom-30pins-protoboard.fzz, aciduino_v2-esp32.fzz]
2023-12-18 fix: set default Serial on esp32 to usb and Serial2
    [wroom.h]
2023-12-18 fix: update uCtrl for esp32 adc max resolution support
2023-12-19 feature: added esp32 wroom schematic on protoboard. official release of esp32 after tests and fixes
    [aciduino_v2-esp32-30pins.fzz]
2023-12-19 fix wroom pinout for pot control
    [wroom.h]
2023-12-21 improvment: keep testing, fix and review esp32 implementation
    [wroom-ext1.h]
2023-12-23 feature: new USE_POT_MICRO to use 1 to 8 directo ADC microntroller port to connect pots for midi controlling. fix: midi controller regression bug fixed
    [AciduinoV2.ino, mega.h, midilab_mega.h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]
2023-12-23 fix: interruped setup for midi call
    [page_midi.ino]
2023-12-23 fix: wrongly commited Serial.begin for debug
    [AciduinoV2.ino]
2024-01-05 porting aciduino to new uctrl and uclock version. supports ble midi out of the box for esp32
2024-01-06 add support for serial-to-midi bridge softwares on usb for esp32 wroom
2024-01-06 fix: roll and shuffle based on new uClock v2
    [wroom.h]
2024-01-06 fix: compile fix in case esp32 wroom dont set bluetooth midi
2024-01-07 fix: sync x5 problem for external gears
2024-01-27 clean up messy macos DS_Store files and fix uClock submodule version
    [setup.h]
2024-02-22 3D printed Case 1.3in added
    [Aciduino_Schematic_v6.sch, Base v18.step, Base v18.stl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]
2024-02-22 3D printed Case 2.4 in 128x64 OLED Version
    [Aciduino_Schematic_v6.sch, Base v7.step, Base v7.stl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]
2024-05-26 encapsulated track output setup memory access
2024-06-05 fix midi controller encapsulation
    [midi_cc_controller.hpp, midilab_mega.h, setup.h]
2024-06-06 fix esp32 -fpermise compilation errors and port esp32 ports to new aciduino schema
    [AciduinoV2.ino, mega.h, protoboard.h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]
2024-06-06 finishing whole code encapsulation port. missing tests
    [AciduinoV2.ino, mega.h, wroom-ext1.h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]
2024-06-06 fix avr mega protoboard port include of aciduino class
    [mega.h]
2024-06-06 fix generative accent and fill for 303 param change
    [midilab_mega.h]
2024-10-12 The initialization of these two arrays spawned an error.
    error: cannot convert '<brace-enclosed initializer list>' to 'uint8_t' {aka 'unsigned char'} in initialization
    Changed the initialization. Now it compiles.
    Arduino IDE 2.3.3

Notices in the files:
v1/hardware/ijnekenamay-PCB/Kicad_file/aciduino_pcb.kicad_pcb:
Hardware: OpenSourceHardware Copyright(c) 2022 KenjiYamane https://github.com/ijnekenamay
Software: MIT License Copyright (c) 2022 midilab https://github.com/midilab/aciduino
